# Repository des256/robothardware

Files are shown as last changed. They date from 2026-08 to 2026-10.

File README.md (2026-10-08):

# robothardware — Robot Backbone PCB

KiCad workspace for the backbone board described in [`HARDWARE.md`](HARDWARE.md)
(how and with what) and [`FUNCTIONAL.md`](FUNCTIONAL.md) (what it does, seen from
its connectors and from software).
Tooling follows [kevins-kicad-helpers](https://github.com/lynaghk/kevins-kicad-helpers)
(vendored at `vendor/kevins-kicad-helpers`, on PATH via `mise.toml`).

## Toolchain status

1. **mise** — `~/.local/bin/mise` (2026.10.3), activation line in `~/.bashrc`.
   `mise trust && mise install` done in this directory (babashka, cljfmt, uv).
2. **sqlite3** — static binary at `~/.local/bin/sqlite3` (3.53.4).
3. **KiCad 10** — 10.0.6 as a *user Flatpak* (`org.kicad.KiCad`, installed
   2026-10-08 because the apt PPA install did not land on this machine; the
   apt `kicad` package is absent). The kkh `bin/kicad-cli` shim falls back to
   the Flatpak automatically, so `kkh check`, `kkh build` and
   `kkh-analyze-schematic` work unchanged — run them from inside the repository,
   the Flatpak sandbox only sees `$PWD`. Direct use:
   `flatpak run --filesystem=$PWD:rw --command=/app/bin/kicad-cli org.kicad.KiCad …`.
4. **KiCad plugins** — *not* installed in the Flatpak yet: bennymeg/Fabrication-Toolkit
   (needed by `kkh build`; install from the Plugin and Content Manager inside
   the Flatpak KiCad) and CDFER/JLCPCB-Kicad-Library (not needed any more — the
   symbols, footprints and STEP models the project uses were copied into the
   project-local `0_backbone` library, see Library status).
5. **Analyzer toolchain** (`kkh check` / `kkh-analyze-schematic`) — Java
   temurin-25, clj-kondo and cljfmt via `mise -C vendor/kevins-kicad-helpers/analyzer install`.
   Clojure still needs the asdf-plugin workaround (`mise plugins install clojure
   https://github.com/asdf-community/asdf-clojure.git`, then
   `~/.local/bin/{clojure,clj}` → `~/.local/share/mise/installs/clojure/1.12.5.1654/bin/`).
   Verified: `kkh-analyze-schematic backbone/backbone.kicad_sch` runs.
6. **`KICAD_PYTHON`** — the apt `pcbnew` module is gone with the apt package;
   the board generator (`tools/schematic-gen/pcb.py`) therefore runs inside the
   Flatpak's own Python (`flatpak run --command=/usr/bin/python3 org.kicad.KiCad`).
   `mise.toml` still points `KICAD_PYTHON` at `/usr/bin/python3` for kkh's
   step-export helper; that path has no `pcbnew` until a KiCad apt package is
   installed again.

## Project layout

- `backbone/` — the KiCad project (`backbone.kicad_pro`, root sheet plus one file
  per block, see below); kkh tools discover it by scanning for `*.kicad_pro`.
  `0_backbone.kicad_sym` / `0_backbone.pretty/` / `0_backbone.3dshapes/` are the
  project-local libraries written by `kkh-import-easyeda-parts` (registered in
  the project `sym-lib-table` / `fp-lib-table`; reopen the project in KiCad
  after an import so it picks them up). Library status is tracked in the
  Schematic plan section.
- `jlcpcb_parts.db` — local JLCPCB catalog mirror (gitignored). **Currently not
  usable:** upstream jlcparts switched to a `source-db-v2` layout whose daily dump
  only carries LCSC numbers above ~C6,300,000, so the mirror built on 2026-10-08
  holds 72,611 parts and none of the classic Basic parts or the curated ICs
  (the vendored `kkh-download-jlcpcb-parts-database` also chokes on the split
  zip). The parts added during schematic capture were resolved against
  JLCPCB's live catalog search instead — see `parts-shortlist.md`.
- `docs/placement.md` — the board floorplan (placement diagram) with the
  rendered `docs/placement.png` / `.svg`.
- `tools/schematic-gen/` — the generator that produced every sheet and the
  placed board (see its README); rerun it instead of hand-editing wholesale.
- `parts-shortlist.md` — distilled candidate parts per block, queried from the DB.
- `datasheets/` — part datasheets for every curated pick plus vendor reference
  designs and the ROBOTIS servo circuits (`datasheets/README.md` is the index;
  `datasheets/fetch.sh` re-downloads from `manifest.tsv`).

## Schematic plan (mirrors HARDWARE.md sections 1 and 8)

**Status 2026-10-08: all 15 pages are drawn.** `kicad-cli sch erc` (KiCad 10.0.6)
reports zero errors and zero warnings for the whole hierarchy,
`kkh-analyze-schematic` passes (228 mA of `max_mA` on +3V3, nothing on VBUS),
and the kkh LCSC check passes. `backbone.kicad_pcb` holds every footprint with
its net and schematic link, placed block by block (`docs/placement.md`); it is
not routed, so `kkh check` stops at DRC with 499 unconnected pads.

The hierarchy lives in `backbone/`. The root sheet `backbone.kicad_sch` is the
block diagram of FUNCTIONAL.md §3 and holds only sheet symbols; every block is
its own file, and the two repeated blocks are one file instantiated several
times:

| Page | Sheet file | Instances | Contents | Golden reference |
|---|---|---|---|---|
| 2 | `input` | 1 | J1, fuse, LM74700 + FET, SMBJ24A, bulk; J2 19 V out with its fuse | LM74700 datasheet |
| 3 | `buck-12v-servo` | 1 | LM5145 → `+12V_SERVO`, shared bulk bank | LM5145 EVM / WEBENCH |
| 4 | `buck-5v-servo` | 1 | LM5145 → `+5V_SERVO` (own file: values differ, and D1 may delete it) | same |
| 5 | `buck-5v-usb` | 1 | TPS54560 → `+5V_USB`, TLV62569 → `+3V3` | TPS54560 EVM |
| 6 | `usbc-upstream` | 1 | J3, HD3SS3220 (UFP, GPIO mode), VBUS_DET, ESD | HD3SS3220 checklist + EVM |
| 7 | `usb-hub` | 1 | TUSB8041, 24 MHz crystal, +1V1_HUB buck (TLV62569 + ferrite), straps, GRSTz RC, USB_VBUS divider | TUSB8041 EVM |
| 8–10 | `usb-port` | 3: `usb-port-1..3` = hub DS1..DS3 | TPS2553 + RILIM (1.51 A, FAULT → hub), ferrite, TPD4E05U06, USBLC6-2, USB-A 3.0 receptacle | hub EVM downstream port |
| 11 | `servo-uart` | 1 | CH344Q on hub DS4, TNOW pull-downs, RXD pull-ups | CH344 datasheet |
| 12–15 | `servo-port` | 4: `servo-port-0..3` = CH344 UART0..3 | SP3485EN + LVC2G241 front-end, mode solder jumper, ESD, both connectors, TPS16630 / TPS25961 e-fuses, 470 µF polymer + TVS per connector | ROBOTIS circuits |

Every sheet starts with a note (golden references, LCSC parts, rails, open
FUNCTIONAL.md decisions) and its hierarchical pins on wire stubs. Anything that
must differ between instances cannot live in a multi-instance sheet: KiCad
stores only reference and unit per instance; values, footprints and DNP are
shared.

Conventions (see HARDWARE.md section 8):

- Rails are global power symbols — `+19V_IN`, `+19V_JETSON`, `+12V_SERVO`,
  `+5V_SERVO`, `+5V_USB`, `+3V3`, `+1V1_HUB`, `VBUS`, `GND` — with the
  `PWR_FLAG` on the sheet that produces the rail. In KiCad 10 a power symbol's
  Value is its net name, so a `power:+5V` symbol with Value `+5V_SERVO` *is*
  the `+5V_SERVO` rail. `VBUS` is reserved for the upstream USB-C VBUS (the
  < 10 µF check); the switched port outputs are `VBUS_OUT`.
- Signals cross sheets through hierarchical pins; the labels on the root name
  the top-level nets (`US_*` upstream ↔ hub, `DSn_*` hub ↔ ports, `UARTn_*`
  uart ↔ servo ports). Inside a multi-instance sheet nets get paths such as
  `/servo-port-0/DATA` — the net-class patterns and DRC rules key on them.
- Designators are sheet number × 100 + n (`R301` is on sheet 3, `#PWR0201` on
  sheet 2); multi-instance sheets count per instance (usb-port 8xx/9xx/10xx,
  servo-port 12xx–15xx). FUNCTIONAL.md §2 carries the resulting connector
  numbers (J201/J202, J601, J801/J901/J1001, J12x1/J12x2 …).
- Non-assembled items (test points, solder jumpers, mounting holes) are
  excluded from the BOM and carry `LCSC = n/a`, which is what the kkh LCSC
  check needs to pass without pretending they are purchasable parts.
- Net-class patterns in `backbone.kicad_pro` were extended while drawing:
  `/usb-port-*/VBUS_*` (the switched output has a ferrite, so two nets),
  `/usb-hub/SW_1V1` (the core-rail buck), plus the original ones.
- `max_mA`: `kkh-analyze-schematic` sums every `max_mA` in the design
  regardless of rail and asserts ≤ 300 mA (hardcoded in
  `vendor/kevins-kicad-helpers/analyzer/src/kicad_analyzer/core.clj`), so it is
  set only on the +3V3 ICs with typical-active numbers: hub VDD33 33, CH344Q 30,
  HD3SS3220 5, 4 × SP3485EN 35, 4 × LVC2G241 5 = 228 mA. The rail budgets
  stay in FUNCTIONAL.md §4.
- `kkh check` fails any placed part (non-DNP, with a footprint) whose `LCSC`
  field is empty — CDFER-library and `kkh-import-easyeda-parts` symbols carry
  it, symbols taken from KiCad's own libraries (`Device:R`, …) need it filled
  in by hand.

### Library status (`0_backbone` is self-contained)

Every symbol the sheets use lives in `backbone/0_backbone.kicad_sym` (KiCad 9
library format, read by KiCad 10) with its footprint in `0_backbone.pretty` and
STEP model in `0_backbone.3dshapes`; nothing depends on the global symbol or
footprint tables. Three sources:

- **`kkh-import-easyeda-parts`** (EasyEDA symbol + footprint + 3D, LCSC field
  filled): TUSB8041IRGCR, CH344Q, SN74LVC2G241DCU, LM5145RGYR, TPS54560DDAR,
  TLV62569DBVR, TPS16630PWPR, TPS25961DRVR, SY6280AAC (unused, kept as the
  imported alternate), HD3SS3220RNHR, LM74700QDBVRQ1, TPD4E05U06DQAR,
  USBLC6-2SC6, B4B-EH-A, B3B-EH-A, XT30PW-M, HC-ST-003-01-J (USB-A 3.0),
  TYPE-C 24P QT, TPS2553DBVR, and the parts added on 2026-10-08: CSD18532Q5B
  (buck + ideal-diode FET), the four inductors (TMPA1265SP-4R7MN-D,
  TMPC1265HP-3R3MG-D, 7447798720, SMNR4020-2.2UH), the 100 V / 16 V / 25 V
  1210 ceramics, the polymer and electrolytic bulk capacitors, both fuses and
  the B560C catch diode. Pin electrical types were set by hand (the import
  leaves them "unspecified", which ERC flags) — see `PIN_TYPES` in
  `tools/schematic-gen/libbuild.py`.
- **Copied from CDFER/JLCPCB-Kicad-Library 2025.07.18** (symbol, footprint,
  STEP; vendor stock/price fields dropped): generic `R_0603`, `C_0402`,
  `C_0603`, `C_0805`, `C_1206`, `FB_0603`, `FB_0805`, `TVS_SMB` — Value and
  LCSC are set per instance from the catalog in `tools/schematic-gen/common.py`
  — plus `LED_0805_Green`, `SMF5.0A`, `SS14`, `PSM712`, `SP3485EN`,
  `Crystal_8MHz_5032`, `Crystal_24MHz_3225`.
- **Copied from KiCad's own libraries**: the power symbols (`+VDC`, `+12V`,
  `+5V`, `+3V3`, `+1V1`, `VBUS`, `GND`, `PWR_FLAG`), `TestPoint`,
  `SolderJumper_3_Bridged12`, `SolderJumper_2_Bridged`, `SolderJumper_2_Open`,
  `MountingHole` with their footprints.

Footprint fixes applied to the imports (so DRC and schematic parity are
clean): the unnumbered thermal-via pads inside the HTSSOP-20 (TPS16630) and
SOIC-8-EP (TPS54560) exposed pads now carry the exposed pad's number, and the
two alignment pegs of both USB-C footprints are NPTH instead of copper-less
PTH. **V4 is still open**: every imported footprint must be checked against
its datasheet drawing before ordering; the USB-C QT shell legs in particular
are modelled as two overlapping oval PTH pads per side.

Alternates that stay importable as a symbol swap: RTS5411S-GR, CYUSB3304-68LTXC,
CH344L, SN74LVC1G126DBVR, SN74LVC1G125DBVR, LM5143RHAR, S4B-EH, S3B-EH,
DC-005-A200, TYPE-C 24P QCHT, SY6280AAC.

EasyEDA's API rate-limits bulk pulls (HTTP 403 after ~15 parts within a
minute); wait a few minutes and rerun the same command for the parts that
failed. Reruns skip parts the library already has.

### Schematic ↔ PCB correspondence

KiCad has no sheet-to-layer mapping; sheets are functional, layers are copper.
The links that do exist, and where each one is set up:

| Link | Where | State |
|---|---|---|
| Stackup | `backbone.kicad_pcb`: 4 copper layers, In1.Cu named `GND` (plane), In2.Cu named `PWR` | set; enter the JLC04161H-7628 thicknesses in Board Setup → Physical Stackup |
| Net classes | `backbone.kicad_pro`: `USB3_SS`, `USB2_HS`, `RS485`, `TTL_DATA`, `PWR_19V`, `PWR_SERVO`, `PWR_USB`, `SW_NODE`; Default clearance 0.127 mm (JLCPCB minimum, needed by the 0.4 mm-pitch HD3SS3220 and the USB-C pads) | defined; USB3_SS / USB2_HS width and gap **still to fill from the JLCPCB impedance calculator** (they inherit Default until then); power-class widths are starting values. The class clearances (SW_NODE 0.5 mm, PWR_SERVO 0.3 mm) and the 3 mm `sw_node_away_from_signals` rule also bite at IC pads (37 DRC clearance errors on the placed board) — scope them to tracks/zones with `A.Type` conditions in the `.kicad_dru` during layout |
| Class of a signal net | directive label on its stub inside the sheet (a multi-instance sheet applies it to every instance) | placed on every USB pair |
| Class of a rail / per-port net | `netclass_patterns` in `backbone.kicad_pro`: `+12V_SERVO`, `/servo-port-*/A`, `/servo-port-*/B`, `/servo-port-*/DATA`, `/servo-port-*/VDD_*`, `/usb-port-*/VBUS_*`, `/buck-*/SW*`, `/buck-*/BOOT*`, `/usb-hub/SW_1V1` | set and used by the drawn sheets |
| Layer geometry and keep-outs | `backbone.kicad_dru`: USB3_SS on F.Cu only and without vias, 1 mm zone clearance to the USB pairs, SW_NODE on outer layers and 3 mm from signal classes, PWR_SERVO copper barred from a rule area named `usb_section` (draw and name it in the PCB editor) | written; check it with Board Setup → Custom Rules → "Check rule syntax" — `kicad-cli pcb drc` silently ignores rule-file errors |
| Sheet → board region | `backbone.kicad_pcb`: one placement rule area per sheet instance (named like the sheet, source = sheet name) plus the `usb_section` area, generated by `tools/schematic-gen/pcb.py`; footprints are packed into them (`docs/placement.md`) | done; routing, exact placement and the connector orientations are the layout stage's job |
| Sheet → component class | `sheet_component_classes` enabled in `backbone.kicad_pro`; rules can use `A.hasComponentClass(...)` | enabled |

Workflow. ERC is clean and the footprints are placed, so `kkh check` now
stops at DRC (unconnected pads) until the board is routed; `kkh build` needs
the Fabrication Toolkit plugin as well. To regenerate sheets or the board after
editing the generator, see `tools/schematic-gen/README.md`. Direct commands:

```sh
kicad-cli sch erc --exit-code-violations -o /dev/stdout backbone/backbone.kicad_sch   # via the kkh shim → Flatpak
kicad-cli pcb drc --schematic-parity -o /dev/stdout backbone/backbone.kicad_pcb
kkh-analyze-schematic backbone/backbone.kicad_sch     # max_mA total, VBUS < 10 uF
kkh-import-easyeda-parts C544686 C2988084 ...          # symbols/footprints per LCSC number
```

From layout onward: `kkh check`, then `kkh build` for the JLCPCB order
package. Put `${KKH_VERSION_DATE}` on the silkscreen (the first `kkh check`
adds the placeholder text variable to `backbone.kicad_pro`; commit it).

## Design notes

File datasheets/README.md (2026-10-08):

# Datasheets and golden references

Everything the schematic gets drawn from, so nobody designs from memory.

- `manifest.tsv` lists every part datasheet (file, LCSC number, MPN, block, URL).
  URLs come from the JLCPCB catalog (`jlcpcb_parts.db`); TI links were rewritten
  to the English editions (`/lit/` instead of `/cn/lit/`).
- `fetch.sh` (re)downloads everything in the manifest and verifies each file is a
  PDF. Safe to re-run; cached files are skipped. LCSC-hosted sheets need the
  `wmsc.lcsc.com/wmsc/upload/file/pdf/…` form of the link (the `www.lcsc.com/datasheet/…`
  form returns an HTML viewer), so the manifest uses those.
- `reference/` holds vendor reference designs, app notes and the ROBOTIS
  circuits — the "golden references" HARDWARE.md §8 asks for per block.

Identical files were collapsed: one JST EH catalog sheet covers B3B/B4B/S3B/S4B,
one Hongjiacheng sheet covers all SMBJ values, one WCH sheet covers CH344Q/L.

## Part datasheets (by block)

| Block | Part (LCSC) | File | Notes |
|---|---|---|---|
| USB 3.0 hub | TUSB8041IRGCR (C544686) | `tusb8041.pdf` | 49 p. Rails: VDD 1.1 V + VDD33 3.3 V; 24 MHz crystal; `USB_VBUS` via 90.9 kΩ divider; per-port `PWRCTLx` / `OVERCURxz` |
| USB 3.0 hub (alt) | RTS5411S-GR (C5356838) | `rts5411s.pdf` | Consumer-hub chip, thinner docs |
| USB 3.0 hub (alt) | CYUSB3304-68LTXC (C462531) | `cyusb3304.pdf` | |
| USB-UART ×4 | CH344Q (C2988084), CH344L (C2887250) | `ch344.pdf` | **Chinese edition** (CH344DS1, 8 p.). TNOW facts extracted in `FUNCTIONAL.md` §5. English copy: manual grab from wch-ic.com (JS-only site) |
| RS-485 transceiver ×4 | SP3485EN-L/TR (C8963) | `sp3485en.pdf` | 3.3 V, 10 Mbps, −7…+12 V common mode; DE / R̄E̅ pins |
| TTL half-duplex buffer ×4 | SN74LVC2G241DCUR (C10430) | `sn74lvc2g241.pdf` | 1OE active-low, 2OE active-high; ±24 mA @ 3.3 V |
| TTL buffer (2-chip alt) | SN74LVC1G126 (C7834), SN74LVC1G125 (C23654) | `sn74lvc1g126.pdf`, `sn74lvc1g125.pdf` | |
| Buck controller, servo rails | LM5145RGYR (C485912) | `lm5145.pdf` | 6–75 V in, external FETs |
| Buck controller, dual (alt) | LM5143RHAR (C5219297) | `lm5143.pdf` | One chip for both servo rails |
| Buck 5 V USB | TPS54560DDAR (C31966) | `tps54560.pdf` | 60 V in, 5 A |
| Buck 3.3 V | TLV62569DBVR (C141836) | `tlv62569.pdf` | 2 A, Vin ≤ 5.5 V |
| eFuse, 12 V buses | TPS16630PWPR (C1849461) | `tps1663.pdf` | 60 V, ~6 A class |
| eFuse, light 5 V buses | TPS25961DRVR (C5571272) | `tps25961.pdf` | ≤ 2 A class |
| VBUS switch ×3 | SY6280AAC (C55136) | `sy6280.pdf` | `Ilim(A) = 6800 / Rset(Ω)`; EN must not float |
| VBUS switch (alt) | TPS2553DBVR (C55266) | `tps2553.pdf` | |
| USB-C CC + SS mux | HD3SS3220RNHR (C165155) | `hd3ss3220.pdf` | UFP: `PORT`=L, `ADDR`=NC (GPIO mode), `ENn_CC`=L, `VBUS_DET` via 900 kΩ |
| Ideal-diode controller | LM74700QDBVRQ1 (C2941042) | `lm74700-q1.pdf` | Drives external N-FET |
| TVS, rails | SMBJ24A / 13A / 6.0A (C19077578 / 67 / 60) | `smbj-series.pdf` | Chinese vendor sheet, all values |
| ESD, USB3 SS pairs | TPD4E05U06DQAR (C138714) | `tpd4e05u06.pdf` | 0.5 pF |
| ESD, USB2 + TTL DATA | USBLC6-2SC6 (C2687116) | `usblc6-2sc6.pdf` | UMW clone |
| ESD, RS-485 | SM712 (C7420375) | `sm712.pdf` | −7 / +12 V asymmetric |
| Servo connectors | JST B4B-EH-A (C160258), B3B-EH-A (C160259), S4B-EH (C265068), S3B-EH (C263754) | `jst-eh-series.pdf` | EH catalog page (drawings, ratings) |
| 19 V input | XT30PW-M (C431092) | `xt30pw-m.pdf` | Chinese drawing |
| 19 V out (alt) | DC-005-A200 (C720557) | `dc-005-a200.pdf` | |
| USB-A 3.0 receptacle ×3 | HC-ST-003-01-J (C2845330) | `usba3-hc-st-003-01-j.pdf` | Chinese drawing |
| USB-C receptacle | TYPE-C 24P QT (C2681555), QCHT (C456013) | `usbc-24p-qt.pdf`, `usbc-24p-qcht.pdf` | Chinese drawings |
| Buck / ideal-diode FET ×5 | CSD18532Q5B (C882766) | `csd18532q5b.pdf` | 60 V, 2.5 mΩ, SON 5×6; RILIM 240 Ω / 150 Ω sized for it |
| Buck inductors | TMPA1265SP-4R7MN-D (C2880057), TMPC1265HP-3R3MG-D (C357272), SMNR4020-2.2UH (C135262) | `tmpa1265sp-4r7.pdf`, `tmpc1265hp-3r3.pdf`, `smnr4020-2r2.pdf` | 12 V, 5 V servo, 3V3/1V1 bucks |
| Buck inductor, +5V_USB | 7447798720 (C105681) | `we-7447798720.pdf` | Würth 7.2 µH 6 A (TPS54560EVM part) |
| Catch diode, +5V_USB | B560C-13-F (C85100) | `b560c.pdf` | |
| 100 V input ceramics | C3225X7S2A475KT000N (C342614), C3225X7R2A225KT5L0U (C76686) | `tdk-c3225x7s2a475k.pdf`, `tdk-c3225x7r2a225k.pdf` | 1210 |
| Buck output ceramics | GRM32ER61C476KE15L (C77101), CS3225X7R226K250NRL (C2918511) | `murata-grm32er61c476k.pdf`, `samwha-cs3225x7r226k.pdf` | 1210 |
| Bulk capacitors | RVE470UF35V167RV084 (C5155332) | `rve470uf35v.pdf` | 19 V input bank. The polymer MA25V470M8X10 (C46550466) / MA10V470M6X8 (C46550459) have no datasheet file in the JLCPCB catalog — spec is the catalog line (25 mΩ / 20 mΩ, 4.1 A / 3.1 A ripple) |
| Fuses | 0453015.MR (C178997), 1206TD-4A (C2838918) | `littelfuse-0453015.pdf`, `prosemi-1206td-4a.pdf` | 15 A time-lag input, 4 A time-lag Jetson |

## Reference designs and app notes (`reference/`)

| Block | File | What it is |
|---|---|---|
| USB hub | `ti-sllu198-tusb8041-evm-users-guide.pdf` | TUSB8041 EVM — the reference schematic to copy |
| USB hub / SS layout | `ti-slla414a-usb-hub-highspeed-layout-guidelines.pdf` | TI SuperSpeed layout rules |
| USB ESD | `ti-slvaf82b-esd-surge-protection-usb.pdf` | Where the TVS arrays go |
| USB-C upstream | `ti-sllu241-hd3ss3220-ufp-dongle-evm.pdf` | HD3SS3220 in **UFP** mode — our exact use |
| USB-C upstream | `ti-slla481-hd3ss3220-schematic-checklist.pdf` | 3-page checklist; run it before ERC |
| 12 V / 5 V servo bucks | `ti-snvu545-lm5145evm-hd-20a.pdf` | LM5145 20 A EVM — schematic, BOM, layout |
| 5 V USB buck | `ti-slvu863-tps54560-evm.pdf` | TPS54560 EVM |
| Input protection | `ti-slvae57b-basics-of-ideal-diodes.pdf` | Background for the LM74700 stage |
| Servo TTL front-end | `robotis/dynamixel-x-ttl-circuit-3v3-74lvc2g241.png` | **ROBOTIS's recommended 3.3 V TTL circuit** (XL330 / XC330-M) — 74LVC2G241, TX_Enable → 1OE̅ + 2OE |
| Servo TTL front-end | `robotis/dynamixel-x-ttl-circuit-5v.png` | Same circuit at 5 V (XL430 / XM430-T class) |
| Servo RS-485 front-end | `robotis/dynamixel-x-rs485-circuit.jpg` | ROBOTIS's recommended RS-485 circuit — MAX485, TX_Enable → DE + R̄E̅ tied |
| Servo connectors | `robotis/dynamixel-x-ttl-connector-pinout.png`, `robotis/dynamixel-x-rs485-connector-pinout.png`, `robotis/emanual-jst-connectors.md` | Pinouts: TTL `1 GND, 2 VDD, 3 DATA`; RS-485 `1 GND, 2 VDD, 3 D+, 4 D−` |
| Servo specs | `robotis/dxl_x_info.yml` | ROBOTIS's own spec data for every X-series servo (voltage, stall current, baud) — feeds the fleet table |
| U2D2 | `robotis/u2d2-emanual.md`, `robotis/u2d2-pinouts.png` | ROBOTIS doesn't publish the U2D2 schematic; the emanual page + the circuits above are what exists |

Source pages: TI product pages (`ti.com/product/<part>`), ROBOTIS e-Manual
(`github.com/ROBOTIS-GIT/emanual`, `_includes/en/dxl/*_connection_x.md`).

## Still to collect (manual)

| Item | Why manual | Blocked on |
|---|---|---|
| WEBENCH designs: LM5145 → 12 V, LM5145 → 5 V, TPS54560 → 5 V | Interactive TI tool, needs login. Export PDF + BOM into `reference/webench/` | Servo fleet decision (currents) |
| English CH344DS1 | wch-ic.com is JavaScript-only; curl gets nothing | — |
| Jetson Orin NX carrier: datasheet / design guide (input range, polarity, USB-C port capabilities) | Depends on which carrier | Carrier decision |
| Dynamixel e-Manual pages for the chosen servos | Fleet not decided; `dxl_x_info.yml` already has the numbers | Fleet decision |
| JLCPCB impedance stackup (JLC04161H-7628) + DRC template | Layout stage | — |

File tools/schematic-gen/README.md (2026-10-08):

# schematic-gen — generator for the backbone sheets and the placed board

Every sheet under `backbone/` and `backbone/backbone.kicad_pcb` were produced by
these scripts on 2026-10-08. They are the source of truth for *regenerating*;
once the sheets are edited by hand in KiCad, stop running the generator (it
rewrites whole files) and keep the scripts as documentation of how the circuit
was derived from the datasheets.

Files

| File | Role |
|---|---|
| `sx.py` | minimal KiCad s-expression reader/writer |
| `sch.py` | schematic writer (KiCad 9 file format, read by KiCad 10): places symbols at coordinates, computes pin positions, draws stubs, labels, power symbols, no-connects, hierarchical labels; `Sheet.check()` is a small connectivity self-check that reports shorted nets and pins lying on foreign wires before writing |
| `common.py` | LCSC catalog (value → part number, verified against JLCPCB on 2026-10-08) and layout helpers (`vR`, `vC`, `decap`, `vdiode`, `rail_led`, `testpoint`, …) |
| `libbuild.py` | one-off: builds `backbone/0_backbone.kicad_sym` — sets pin electrical types on the EasyEDA imports, copies the generic passives and small parts from the CDFER JLCPCB library (needs the unzipped PCM package, `CDFER_PKG=…`), copies KiCad's power / jumper / test point / mounting hole symbols and footprints. Already applied; rerun only after new `kkh-import-easyeda-parts` imports |
| `d_power.py` | sheets 2–5: input, LM5145 bucks (TI application circuits 1 and 2 parametrised in `P12` / `P5`), TPS54560 + TLV62569 |
| `d_usb.py` | sheets 6–10: HD3SS3220 upstream, TUSB8041 hub, USB-A port (×3) |
| `d_servo.py` | sheets 11–15: CH344Q, dual-mode servo port (×4) |
| `d_root.py` | root sheet: re-emits the skeleton block diagram (`skeleton/backbone.kicad_sch`) in KiCad 9 format and adds the mounting holes |
| `build.py` | writes the sheets into `backbone/` and runs ERC through the Flatpak KiCad 10 |
| `pcb.py` | builds the board from the exported netlist: footprints with nets and paths, placement rule areas, outline, texts; the floorplan is the `REGIONS` table (see `docs/placement.md`). Runs inside the Flatpak's Python |
| `skeleton/` | the original KiCad 10 root sheet and board stub the generator starts from (sheet-symbol UUIDs and page numbers come from here) |

Regenerate everything (run from the repository root; the Flatpak only sees `$PWD`):

```sh
python3 tools/schematic-gen/build.py                      # all sheets + ERC summary
python3 tools/schematic-gen/build.py usb-hub servo-port   # a subset
kicad-cli sch export netlist --format kicadsexpr -o backbone/outputs/scratch/backbone.net backbone/backbone.kicad_sch
flatpak run --filesystem=$PWD:rw --command=/usr/bin/python3 org.kicad.KiCad tools/schematic-gen/pcb.py
kicad-cli pcb export svg --layers F.Cu,F.SilkS,Edge.Cuts,Cmts.User --page-size-mode 2 --exclude-drawing-sheet -o docs/placement.svg backbone/backbone.kicad_pcb
```

`kicad-cli` resolves through `vendor/kevins-kicad-helpers/bin` (on PATH via
`mise.toml`), which falls back to the Flatpak when no native KiCad is installed.

Conventions baked into the generator

- Symbol UUIDs are `uuid5` of sheet name + reference + position, so reruns
  produce the same identities and the board keeps its schematic links.
- References are sheet number × 100 + n; multi-instance sheets get one
  reference per instance path (usb-port 8xx/9xx/10xx, servo-port 12xx–15xx).
- Non-assembled parts (test points, solder jumpers, mounting holes) are
  excluded from the BOM and carry `LCSC = n/a`; DNP parts (RS-485 termination,
  SW snubbers) are marked DNP.
- Power symbols come from the project library; the sheet that produces a rail
  owns its `PWR_FLAG` (`Sheet.flag_rail`).

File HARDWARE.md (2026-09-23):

# HARDWARE — Robot Backbone PCB

Design notes for the power-and-interconnect motherboard: USB 3.0 hub with three
generic downstream ports (RealSense D435, ReSpeaker 4-mic array, future
hardware), four dual-mode servo buses (RS-485 @ 12 V or TTL @ 5 V) via a CH344,
and step-down converters feeding the Jetson Orin NX and peripherals.

> **Status: design guidance, not a finished design.** Every part number below is a
> *candidate* to be verified against its datasheet and current stock — nothing here
> substitutes for the reference design in each datasheet.

## 1. System architecture

```
19V laptop adapter ──► [fuse + reverse-polarity ideal diode + TVS + bulk caps]
                            │
        ├──► 19V passthrough ──► [fuse/load switch] ──► 19V out (Jetson Orin NX)
        ├──► Buck #1: 12V ──► star ──► 4× [e-fuse + bulk caps + TVS] ──► 4-pin RS-485 connectors
        ├──► Buck #2: 5V servo ──► star ──► 4× [e-fuse + bulk caps + TVS] ──► 3-pin TTL connectors
        └──► Buck #3: 5V USB @ ~5A ──► 3× VBUS switches ──► USB-A 3.0 sockets
                       │
                       └──► 3.3V (small buck or LDO) ──► hub, CH344, bus front-ends

USB-C (from Jetson, upstream) ──► [CC controller + SS mux] ──► USB 3.0 hub (4-port)
        ├── ports 1–3 (SS): generic USB-A 3.0 ──► RealSense, ReSpeaker, future hardware
        └── port 4 (USB2 only): CH344 ──► 4× dual-mode front-ends ──► RS-485 or TTL connector
```

Key insight: the Jetson is both a *load* (19V out) and the *USB host* (USB-C in).
The board is a **self-powered hub** — that has consequences (see §3, USB rules).

## 2. Power budget first — everything else follows from it

Build this table before picking any converter. Worst case, not typical:

| Rail | Loads | Estimate |
|---|---|---|
| 19V passthrough | Orin NX at MAXN (clocks pinned per README) + carrier | ~40 W (the Jetson's own USB loads live on *this* board, so it stays moderate — check the carrier's spec) |
| 12V servo (RS-485 buses) | RS-485 servo fleet. Sum-of-stall (~2 A @ 12 V per Dynamixel-X-class servo) is the conservative ceiling; size for the worst *simultaneous* mechanical load you can justify and let per-bus e-fuses bound the rest (§5) | 10–20 A depending on fleet |
| 5V servo (TTL buses) | TTL servo fleet — same sizing philosophy. XL330-class servos stall around 1–1.5 A each (verify per model). **Never shared with the USB 5 V rail** | 5–10 A depending on fleet |
| 5V USB | 3 generic ports × per-port current limit (~1.5 A each) + the 3.3 V rail derived from this (quiet) rail. **Generic ports mean sizing for the sum of the limits, not for a known device list** | ~5 A |
| 3.3V | Hub + CH344 + bus front-ends | < 0.5 A |

Sum at ~85% converter efficiency: a build with a 10 A 12 V budget and a 5 A TTL
budget lands around **~240 W peak** (≈141 W + ≈29 W for the servo rails + ≈29 W
USB + ~40 W Jetson). Big laptop bricks top out around 230–330 W — **spec the
adapter from this table, not from habit**, and recompute when the servo fleet
changes. A 90 W adapter will brown out during a servo stall while the Jetson is
at MAXN — the classic "robot reboots when the arm hits something" bug.

## 3. Component selection, block by block

### Input protection (19V)

Blade fuse or high-current polyfuse → reverse-polarity protection with an
ideal-diode controller + N-FET (e.g., LM74700-Q1) rather than a lossy series diode
(at 6 A a Schottky wastes ~3 W) → TVS with standoff above the adapter's max
(19 V + 10% → something like an SMBJ24A, which clamps near 39 V — so every
downstream converter needs Vin(max) well above that; hence 60 V-rated bucks) →
bulk electrolytics.

### Step-down converters

- 12 V at four-bus current (10–20 A) is beyond single-chip bucks — use a
  controller + external FETs (LM5145 class) or a validated power module. The same
  controller design can be reused for the 5 V servo rail with a different
  feedback divider — good BOM consolidation.
- 5 V servo rail: sized to the TTL fleet (§2); a single-chip 5 A part suffices
  only for a small fleet.
- 5 V USB at ~5 A sits right at the edge of a single-chip part like the TPS54560
  (4.5–60 V, 5 A): either bound the per-port limits so the sum fits (e.g.,
  3 × 1.3 A), or reuse the controller-based design here too.
- Use TI WEBENCH / the vendor's design tool for inductor and compensation values,
  then **copy the datasheet layout example exactly** — buck layout is not a place
  for creativity.
- 3.3 V via a small buck (TPS62-class) or LDO (if confirmed < ~300 mA), fed from
  the **quiet USB 5 V rail — never the servo rails**.
- USB 3.0 hub chips also need a core rail (1.1/1.2 V) — follow the hub datasheet's
  reference design, usually a dedicated LDO.

### USB 3.0 hub

4-port SuperSpeed hub controller — candidates: Microchip USB5744, TI TUSB8041,
VIA VL817. Selection criteria: in stock at LCSC/Digi-Key, a public reference
schematic, and (this matters) evidence people run RealSense cameras through it —
the D435 is notoriously picky about marginal USB3 links, and the librealsense
GitHub issues are full of hub horror stories. Search for hubs the RealSense
community has validated.

### Generic downstream ports

All three non-CH344 downstream ports are wired identically as USB-A 3.0: full
SuperSpeed pairs, same ESD array, same per-port power switch. Consequences:

- Any device fits any port. The RealSense needs SuperSpeed; the ReSpeaker is
  USB 2.0 and works fine in a USB 3.0 socket (the USB2 pins are a superset).
- Cost vs. dedicated ports: two extra SS pair routes + ESD arrays — cheap for the
  flexibility.
- **Per-port current limits must be identical (~1.5 A)** since you no longer know
  which device lands where, and the 5 V USB rail must be sized for the *sum* of
  the limits plus the 3.3 V derivation (§2) — not for the known device list.
- Software should identify devices by VID/PID (as the existing ReSpeaker udev
  rule already does), never by physical port position — anything keyed to
  `/dev/serial/by-path` or USB topology breaks when a device moves ports.

### USB-C upstream — a real gotcha

For SuperSpeed to work in *both* plug orientations, a device needs a CC controller
+ 2:1 SS mux (e.g., TI HD3SS3220 — the standard part for exactly this). Without
it, wire Rd (5.1 kΩ) pull-downs on CC1/CC2 and SS only links in one orientation,
silently falling back to USB 2.0 in the other — which for the D435 means depth
streams fail mysteriously. Budget the mux.

### Self-powered hub rules

- Do **not** connect upstream VBUS to the 5 V rail — the Jetson must not
  back-power the board or vice versa. Upstream VBUS goes only to the hub's
  VBUS-detect pin (through the divider the datasheet specifies).
- Downstream, give each USB-A socket a current-limiting power switch (TPS2553
  single / TPS2561A dual), fault flag wired to the hub's overcurrent-sense pins.
- Set all three port limits identically (~1.5 A) — generic ports, unknown
  placement (see above).

### Servo buses — CH344, four dual-mode ports (RS-485 or TTL)

- The **CH344 is a quad-UART bridge** — one USB 2.0 hub port in, four independent
  UARTs out. Each UART feeds a **dual-mode front-end**: a 4-pin RS-485 connector
  (12 V power) *and* a 3-pin TTL connector (5 V power), with one mode in use per
  port.
- **Both modes speak the same UART framing and protocol** — the difference is
  physical layer only. RS-485: differential A/B pair. TTL: single-ended,
  single-wire half-duplex — TX and RX share one DATA line that idles high via a
  pull-up.
- **RS-485 side:** one transceiver per port. With TNOW available (below), a plain
  DE/R̄E̅ transceiver (THVD1450-class) is preferred over auto-direction parts —
  one direction scheme serves both modes.
- **TTL side:** one tri-state buffer per port (SN74LVC2G241-class). Its two
  complementary output enables make a single chip a complete half-duplex
  front-end — one gate drives TXD onto DATA when enabled, the other feeds DATA
  back to RXD. This mirrors ROBOTIS's own U2D2 reference circuit — pull up that
  schematic as the golden reference.
- **Direction:** the CH344's per-UART TNOW pin (asserts during transmission)
  drives both the RS-485 DE and the '241 enables. Verify TNOW polarity against
  the enable pins — a tiny inverter may be needed.
- **Mode select (the either/or):** TXD may fan out to both drivers permanently —
  the unused connector just carries a harmless copy. **RX is the only conflict:**
  exactly one receiver may drive the UART RXD pin. A per-port jumper /
  solder-bridge (or GPIO) enables one receiver — transceiver R̄E̅ vs. '241 RX
  gate — with both outputs wire-OR'd onto RXD through a pull-up.
- **Echo symmetry:** gate both receivers off during TNOW so neither mode echoes
  the transmitted packet — echo behavior stays identical across all ports and
  modes, and the servo software needs no per-port special-casing.
- **Levels:** run logic at 3.3 V (the CH344's native level). LVC buffers are
  5 V-tolerant, so a 5 V-pulled DATA line is fine, and 3.3 V drive meets TTL
  thresholds — but check the specific servo's DATA-pin spec (XL330-class 5 V
  servos have 3.3 V-compatible logic; verify per model).
- **TTL caution:** single-ended means far less noise immunity than RS-485 on a
  robot full of motors — keep TTL runs short, ground solid, ESD TVS on DATA
  (5 V working-voltage part), optional small series resistor (~10–22 Ω).
- Check the transceiver's, buffer's, and CH344's max data rates against the servo
  protocol (Dynamixel Protocol 2.0 commonly runs 57.6 kbps–1 Mbps+).
- **Driver check before committing:** confirm how the CH344 enumerates on the
  L4T/Jetson kernel — the four ttys typically come from WCH's out-of-tree `ch343`
  serial driver; verify it builds for aarch64. Cheapest test: a CH344 dongle
  before the board exists.
- Why four buses: RS-485/TTL are multi-drop, so one bus *could* daisy-chain every
  servo — the four buses exist for **control bandwidth** (each bus polls fewer
  servos per cycle → lower feedback latency), plus fault isolation and per-limb
  home-run cabling.

### Connectors

- RS-485 mode: Dynamixel-X RS-485 servos use a JST EH 4-pin (GND, V+, D+, D−) —
  match the servo's actual pinout *from its manual*.
- TTL mode: bigger X-series TTL servos use a JST EH 3-pin (GND, V+, DATA);
  XL330-class servos use a smaller housing — check the manual.
- **The different 3-pin/4-pin housings double as keying**: a 5 V TTL servo
  physically can't be plugged into a 12 V RS-485 connector. Preserve that
  property when picking connectors.
- Mind per-contact current ratings (EH-class contacts are good for ~2–3 A — a
  daisy-chain of stalling servos can exceed that even on a single bus).
- Barrel jacks are often rated only ~5 A; adequate for ~40 W at 19 V but check the
  specific part. Verify the Jetson carrier's accepted input range and polarity
  before committing (official carriers take roughly 9–20 V center-positive —
  confirm).
- USB-A receptacles with through-hole shell stakes for mechanical strength.

### ESD on every external connector

Low-capacitance TVS arrays — TPD4E05U06-class on SuperSpeed pairs, USBLC6-2 on
USB 2.0 pairs, SM712 on RS-485, a 5 V-working-voltage single-line TVS on TTL
DATA, plain SMBJ on the power connectors.

## 4. Servo surge protection

Two distinct phenomena, applying to **both** servo rails (12 V and 5 V):

1. **Stall/inrush transients** — the servo rail sags. Fix: bulk low-ESR
   capacitance (≥ 470–1000 µF electrolytic/polymer) physically at each servo
   connector, plus a buck with headroom. Cap voltage rating: ≥ 25 V on the 12 V
   rail, ≥ 10 V on the 5 V rail.
2. **Regenerative back-EMF** — when servos decelerate or are back-driven, they
   *pump current into* the rail, and **buck converters cannot sink current**, so
   the rail voltage rises. Fix: the same bulk capacitance absorbs the energy, and
   a TVS catches what the caps don't — SMBJ13A-class (13 V standoff) on the 12 V
   rail, SMBJ6.0A-class (6 V standoff) on the 5 V servo rail. Confirm the buck
   tolerates output overvoltage gracefully (most modern ones stop switching). For
   large servos with heavy loads the proper fix is an active brake/shunt clamp
   (comparator + FET + power resistor); for Dynamixel-class servos, caps + TVS is
   standard practice.

A series diode between buck and servo rail (to protect the buck) is usually *not*
used — it ruins regulation, and the regen energy has nowhere to go but up. Caps +
TVS is the right shape.

## 5. Four dual-mode servo ports on shared rails

**One buck per voltage class, not per bus.** The standard shape is one 12 V rail
and one 5 V servo rail, each with per-connector protection — separate bucks per
bus are 4× the parts and board area for little gain, and each would still need
sizing for its own bus's stall anyway. Split a rail into two bucks only for very
asymmetric loads (one heavy arm bus + three light buses) or when hard fault
domains are required.

Applies identically to the 12 V (RS-485) and 5 V (TTL) rails:

- **Buck sizing:** each rail carries its whole fleet — see §2. Sum-of-stall is
  the conservative ceiling; size for the worst simultaneous mechanical load you
  can justify, and let per-bus current limits bound the rest.
- **Caps, shared + distributed:** a large bulk bank at the buck output, plus a
  local ~470 µF low-ESR cap *at each connector*. Regen from one bus pumps the
  shared rail, where the shared bulk — and the load of the other buses — absorbs
  it; that's a mild benefit of sharing one rail.
- **One TVS per connector.** Cheap; keep them all (voltage class per §4).
- **Per-connector e-fuse or polyfuse:** fault isolation, so a crushed servo cable
  on one limb doesn't drop the whole robot. GPIO-controlled e-fuses (TPS259x
  class) additionally give soft-start, a per-bus e-stop, and staggered power-up
  to tame the combined inrush of multiple buses enabling at once.
- **Star distribution:** route each rail from its buck's bulk bank to the
  connectors as separate polygon pours, so one bus's stall sag doesn't couple
  through shared trace impedance into the others.
- **The 5 V servo rail is never the USB 5 V rail** — servo stall transients on a
  shared rail would brown out the cameras. Two separate bucks, two separate
  distribution trees, joined only at ground.

## 6. Layout and stackup — where USB 3.0 boards live or die

- **4-layer minimum**: Signal / GND / Power / Signal. Order the fab's
  impedance-controlled stackup (e.g., JLCPCB's JLC04161H-7628) and use *their*
  calculator for trace geometry — don't copy numbers from forums.
- SuperSpeed pairs: 90 Ω differential, intra-pair matched to ~0.1 mm, continuous
  ground reference underneath (no plane splits), no stubs, AC-coupling caps
  (0.1 µF) on TX pairs where the hub datasheet shows them, ESD arrays right at the
  connector. Keep pairs short — place the hub between the USB-C and the USB-A
  ports.
- Keep buck inductors and switch nodes **away** from USB, RS-485, and TTL DATA
  routing; keep each buck's input loop tiny; thermal vias under converter pads.
- High-current paths (19 V in, both servo rails, servo ground returns) get
  polygons, not traces; route servo returns so they don't flow under the USB
  section.
- 2.4 GHz radios on the robot: USB 3.0 famously radiates in that band (Intel has a
  whole whitepaper) — keep antennas away from this board and use shielded
  connectors/cables.

## 7. Workflow: KiCad → fab

1. **Prototype the architecture first with off-the-shelf modules** — a powered
   USB3 hub, a CH344-based USB-RS485 dongle (doubles as the L4T driver check),
   buck modules. Most of this stack already runs; the PCB is an *integration*
   step, so de-risk each block before committing copper. The dual-mode front-end
   is breadboardable: CH344 dongle + '241 buffer + one TTL servo.
2. Hierarchical schematic, one sheet per block above. Pull symbols/footprints via
   easyeda2kicad (LCSC parts) or SnapEDA — and **verify every footprint against
   the datasheet drawing**; wrong footprints are the #1 first-spin killer.
3. If using JLCPCB assembly, prefer parts in their library ("Basic" parts avoid
   setup fees) and check stock *before* finalizing the schematic.
4. Set up net classes and diff-pair rules from the fab's stackup numbers; use
   KiCad's diff-pair router and length tuner; import the fab's DRC template.
5. ERC → layout → DRC → 3D check (connector collisions!) → `kkh build` produces
   the full JLCPCB order package (Gerbers, BOM, CPL, STEP, PDFs),
   git-revision-stamped — put `${KKH_VERSION_DATE}` on the silkscreen so the
   fabbed board identifies its own revision.
6. Board bring-up features: test points on every rail plus all four bus
   front-ends (both modes), power-good LEDs per rail, mounting holes, and 0 Ω
   resistor options where unsure (e.g., RS-485 termination, mode-select defaults,
   VBUS detect divider).
7. Order ~5 boards, assemble 2. Bring up power rails with USB/servos
   *disconnected* first, check every rail with a scope, then add subsystems one at
   a time — RealSense last, since it's the fussiest.

## 8. Schematic start: KiCad 10 + kevins-kicad-helpers

Toolchain: KiCad 10 with
[kevins-kicad-helpers](https://github.com/lynaghk/kevins-kicad-helpers) vendored
as a git submodule. Per its README that means `mise` for env management plus two
KiCad plugins: bennymeg/Fabrication-Toolkit and the CDFER JLCPCB-Kicad-Library
(ready-made symbols/footprints for JLC Basic parts).

The workspace is this repository (see [`README.md`](README.md)); the distilled
candidate parts are in [`parts-shortlist.md`](parts-shortlist.md).

Order of operations:

1. **Parts before wires.** `kkh-download-jlcpcb-parts-database` mirrors the
   JLCPCB catalog into SQLite with parametric columns. Resolve every "candidate"
   part in §3 into an actual LCSC part number — with stock, price, and
   Basic/Extended status — *before* drawing anything. Datasheets drive the
   schematic, not vice versa, and it prevents late "out of stock" redesigns.
2. **Golden references per block:** hub datasheet reference schematic, ROBOTIS
   U2D2 schematic (servo front-end), HD3SS3220 datasheet (USB-C upstream),
   vendor design-tool output (bucks). Collected under `datasheets/` — see
   `datasheets/README.md`; ROBOTIS does not publish the U2D2 schematic, the
   golden reference is their recommended TTL / RS-485 circuits instead
   (`datasheets/reference/robotis/`). The functional behaviour these blocks
   must deliver is written up in `FUNCTIONAL.md`.
3. **Hierarchical sheets, multi-instance:** the root sheet mirrors §1. The
   dual-mode servo front-end is *one* sheet instantiated 4×; the generic USB
   port is *one* sheet instantiated 3× — fix a bug once, every instance follows.
4. **Draw the risky blocks first** (servo front-end, USB-C upstream). The power
   sheets are cookbook copies of vendor reference designs and come after.
5. **Conventions that feed the automation:** put `max_mA` properties on the
   3.3 V ICs so `kkh-analyze-schematic` totals their draw — it sums every
   `max_mA` regardless of rail and asserts ≤ 300 mA, so it is a 3.3 V-rail
   check, not the §2 budget (that lives in FUNCTIONAL.md §4).
   Reserve the net name `VBUS` for the true upstream VBUS so its < 10 µF check
   enforces the USB device-side inrush limit — servo rails are `+12V_SERVO` /
   `+5V_SERVO` so their deliberately huge bulk banks don't trip it.
6. **`kkh check` from the first sheet onward;** pull symbols/footprints with
   `kkh-import-easyeda-parts` as parts get placed.

## 9. Biggest caveats, ranked

1. **Adapter wattage** vs. MAXN-Jetson + two servo rails of stall — do the math
   (§2); dual-rail builds escape 150 W-adapter territory fast.
2. **USB-C orientation mux**, or SuperSpeed works only one way.
3. **Bucks can't sink servo regen** — bulk caps + TVS, per connector, both rails
   (§4, §5).
4. **CH344 is a UART bridge** — per-port RS-485 transceivers *and* TTL half-duplex
   buffers are still required, and the L4T driver must be verified early (§3).
5. **RX contention on dual-mode ports** — exactly one receiver per UART RXD;
   mode-select gating is mandatory, not optional (§3).
6. **Never merge the 5 V servo rail with the 5 V USB rail** — servo stalls would
   brown out the cameras.
7. **D435 link-quality sensitivity** — pick a community-validated hub chip and
   test with the real camera at first power-on, not last.

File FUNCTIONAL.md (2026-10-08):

# FUNCTIONAL — Robot Backbone PCB

What the board *does*, seen from its connectors and from the Jetson's software.
[`HARDWARE.md`](HARDWARE.md) is the how-and-with-what; this document is the
what, so everyone — hardware, firmware, robot software — shares one picture
before the first schematic sheet is drawn. Facts below come from the datasheets
in [`datasheets/`](datasheets/README.md); anything not yet nailed down is an
explicit **Decision** (D‑n) or **Verify** (V‑n) item, collected in §10.

> **Status: draft for review.** D1 (which servos, on which rail) changes the
> power sheets and the connector story; settle it first.

## 1. The board in one paragraph

A self-powered USB 3.0 hub plus a servo-bus controller plus a power
distribution board, in one PCB. It takes 19 V from a laptop adapter, passes it
through to the Jetson Orin NX, and makes three more rails: 12 V and 5 V for
servo buses and 5 V for USB. The Jetson talks to the board over one USB-C
cable; behind that the board presents three generic USB 3.0 ports (RealSense,
ReSpeaker, whatever comes next) and four independent Dynamixel servo buses,
each usable in RS-485 or TTL mode. Every external connector is fused/limited,
ESD-protected and hot-plug tolerant. Nothing on the board runs firmware — it is
all hardware behaviour plus standard Linux USB drivers.

## 2. External interfaces

| # | Connector | Qty | Direction | Carries | Rail / limit |
|---|---|-----|---|---|---|
| J201 | 19 V IN — XT30PW-M | 1 | in | Adapter power | 19 V, adapter-rated (§4 budget); 15 A time-lag fuse, LM74700 ideal diode, SMBJ24A behind it |
| J202 | 19 V OUT — XT30PW-M (or barrel, D6) | 1 | out | Jetson carrier power | 19 V passthrough, 4 A time-lag fuse |
| J601 | USB-C upstream — 24-pin receptacle | 1 | in (host) | USB 3.0 SS + USB 2.0 from Jetson | VBUS *not* used for power (§6) |
| J801, J901, J1001 | USB-A 3.0 downstream | 3 | out (device side) | USB 3.0 SS + 2.0, generic | +5V_USB, 1.51 A each (TPS2553), switched by the hub |
| J1201, J1301, J1401, J1501 | Servo RS-485 — JST B4B-EH-A | 4 | bus | `1 GND · 2 VDD · 3 D+ · 4 D−` | +12V_SERVO, TPS16630 e-fuse 4.5 A per port |
| J1202, J1302, J1402, J1502 | Servo TTL — JST B3B-EH-A | 4 | bus | `1 GND · 2 VDD · 3 DATA` | +5V_SERVO (**D1**), TPS25961 e-fuse ≈ 2 A per port |
| — | Test points, rail LEDs, mode jumpers | — | — | Bring-up (§9) | — |

Designators are sheet × 100 + n (README.md); the servo-port x/y pairs belong to
servo port *n* = UART *n* (J12x1 = port 0, J13x1 = port 1, …).

Pinouts are ROBOTIS's (`datasheets/reference/robotis/`). RS-485 and TTL
connectors of the same servo port share one UART; one is populated with a
cable at a time (§5.3).

## 3. Block diagram

```
                J1 19V IN
                   │
     [fuse]─[ideal diode LM74700]─[TVS SMBJ24A]─[bulk]──── +19V_IN
                   │
     ┌─────────────┼──────────────────────┬──────────────────────┐
     │             │                      │                      │
 [fuse/switch]  [Buck A  LM5145]      [Buck B  LM5145]      [Buck C  TPS54560]
     │          +12V_SERVO 10–20 A     +5V_SERVO 5–10 A      +5V_USB 5 A
  J2 19V OUT       │                      │                      │
  (Jetson)   ┌─────┼─────┐          ┌─────┼─────┐         ┌──────┼──────┐
             4× [eFuse+cap+TVS]     4× [eFuse+cap+TVS]    3× [TPS2553 1.5A] [TLV62569]
             J7–J10 VDD             J11–J14 VDD           J4–J6 VBUS      +3V3 ─┐
                                                                                │
 ──────────────────────────── data ─────────────────────────────────────────────┤
                                                                                │
  J3 USB-C ──[HD3SS3220 CC + SS mux]──┐                                         │
   (Jetson host)                      ▼                   +1V1_HUB buck (TLV62569) ◄─┤
                             [TUSB8041 4-port hub]  ◄── 3V3, 1V1               │
                    ┌────────┬────────┼──────────────┐                          │
                   DS1      DS2      DS3            DS4 (USB 2.0 only)          │
                    │        │        │              │                          │
                 J4 USB-A  J5 USB-A  J6 USB-A     [CH344Q quad UART] ◄── 3V3 ───┘
                 (SS+HS)   (SS+HS)   (SS+HS)         │  │  │  │
                                            4× ─────┘  │  │  └───── UARTx: TXDx RXDx TNOWx
                                                       ▼
                                          ┌── per servo port ──────────────────────┐
                                          │  TNOWx ─┬─► SP3485EN  DE, R̄E̅ ─► A/B ─► J7+n (RS-485)
                                          │         └─► LVC2G241  2OE, 1OE̅ ─► DATA ─► J11+n (TTL)
                                          │  TXDx ──► both drivers      RXDx ◄── one receiver (mode jumper)
                                          └─────────────────────────────────────────┘
```

Net names that the automation checks (HARDWARE.md §8): `VBUS` is reserved for
the upstream USB-C VBUS; the servo rails are `+12V_SERVO` / `+5V_SERVO`; the
USB rail is `+5V_USB`; every load symbol carries `max_mA`.

## 4. Power domains

| Rail | Source | Feeds | Budget (worst case) | Protection at the load | Enable / sequencing |
|---|---|---|---|---|---|
| +19V_IN | Adapter via fuse, LM74700 ideal diode, SMBJ24A, bulk caps | Everything | Adapter rating (**D1** sets it; HARDWARE.md §2 example lands ~240 W) | Reverse polarity blocked; surge clamped ~39 V, hence 60 V-rated bucks | Present whenever the adapter is |
| +19V_JETSON (J2) | +19V_IN via fuse / load switch | Jetson carrier | ~40 W → ~2.1 A | Fuse | Same as input (Jetson boots as soon as power arrives) |
| +12V_SERVO | Buck A (LM5145 + FETs) | 4× RS-485 servo ports | Sum of stall of the RS-485 fleet, bounded by per-port e-fuses | Per port: e-fuse (TPS1663x class), ≥ 470 µF low-ESR, SMBJ13A | Up at power-on; per-port e-fuse soft-start staggers inrush (**D3**: always-on vs software-controlled) |
| +5V_SERVO | Buck B (same LM5145 design, 5 V divider) | 4× TTL servo ports | Sum of stall of the TTL fleet, bounded by per-port e-fuses | Per port: e-fuse (TPS25961 class if ≤ 2 A, else TPS1663x), ≥ 470 µF, SMBJ6.0A | As above. **Never merged with +5V_USB** |
| +5V_USB | Buck C (TPS54560) | 3× VBUS switches + 3V3 and 1V1 bucks + HD3SS3220 VDD5 | 3 × 1.5 A + 3V3 load ≈ 5 A | Per port: TPS2553 current limit 1.51 A (RILIM 16.9 kΩ), FAULT → hub `OVERCURxz` | Port VBUS switched on by the hub (`PWRCTLx`) after enumeration |
| +3V3 | TLV62569 from +5V_USB | Hub I/O, HD3SS3220, CH344Q, transceivers, buffers | < 0.5 A | — | Up with +5V_USB |
| +1V1_HUB | TLV62569 buck from +5V_USB, 1.09 V (82 k / 100 k), ferrite into the hub's VDD pins (**D7**: the EVM's TPS74801 LDO is the fallback if core noise is a problem) | Hub core | ≤ 778 mA per DS | — | Up with +5V_USB; GRSTz released ≈ 100 ms later by its RC |
| VBUS (upstream) | Jetson, through J3 | HD3SS3220 `VBUS_DET` (900 kΩ) and TUSB8041 `USB_VBUS` (90.9 kΩ divider) — **detection only** | ~0 | < 10 µF total on this net (USB inrush rule; `kkh` checks it) | — |

### 4.1 Fleet worksheet (input to D1)

ROBOTIS's own figures (`datasheets/reference/robotis/dxl_x_info.yml`): stall
current at rated voltage, and — the important part — which rail each family
actually wants.

| Family | Bus | Input voltage (recommended) | Stall current | Notes |
|---|-----|---|---|---|
| XL330-M077 / M288 | TTL, **3.3 V logic** (5 V compatible) | 3.7–6.0 V (**5 V**) | 1.11 A @ 3.7 V | The only family that is genuinely a 5 V servo |
| XC330-M181 / M288 | TTL, 3.3 V logic | 3.7–6.0 V (**5 V**) | 1.34 A @ 3.7 V | |
| XC330-T181 / T288 | TTL, 5 V logic | 6.5–12.0 V (**11.1 V**) | 0.61 A @ 9 V | Same 3-pin EH connector as the 5 V units |
| XL430-W250 (and 2XL430) | TTL, 5 V logic | 6.5–12.0 V (**11.1 V**) | 1.0 A @ 9 V | |
| XC430-W150 / W240 (and 2XC430) | TTL, 5 V logic | 6.5–14.8 V (**12 V**) | 1.1 A @ 9 V | |
| XM430-W210 / W350 | RS-485 (-R) **or** TTL (-T) | 10–14.8 V (**12 V**) | 2.1 A @ 11.1 V | |
| XH430-W210 / W350 | RS-485 or TTL | 10–14.8 V (**12 V**) | 1.2 A @ 11.1 V | |
| XH430-V210 / V350 | RS-485 | **24 V** | 0.7 A @ 24 V | Not supported by this board (no 24 V rail) |
| XM540-W150 / W270 | RS-485 or TTL | 10–14.8 V (**12 V**) | 4.2 A @ 11.1 V | |
| XH540-W150 / W270 | RS-485 or TTL | 10–14.8 V (**12 V**) | 4.5 A @ 11.1 V | |
| XW430 / XW540-T | RS-485 | 10–14.8 V (**12 V**) | 1.2 / 4.5 A | IP-rated |

Baud: 9.6 kbps – 4 Mbps (X330) or 4.5 Mbps (others). Protocol 2.0 throughout.

**What this means (D1):** HARDWARE.md pairs "TTL ↔ 5 V" and "RS-485 ↔ 12 V",
but only the X330-M family is a 5 V servo. Every other TTL X-series servo
(XL430, XC430, XM430-T, XH430-W-T, XC330-T) is a **12 V servo on the same
3-pin EH connector** — the connector keying does *not* separate 5 V from 12 V
TTL servos. The board therefore has to choose what VDD its 3-pin ports carry:

- **(a) 5 V** — as drafted. Supports X330-M only on the TTL ports; every 12 V
  servo must be an RS-485 variant on the 4-pin ports.
- **(b) 12 V on both connector types** — one servo rail, one buck; TTL ports
  serve XL430/XC430/XM430-T; X330-M units are then *excluded* (plugging one in
  destroys it — no keying protects against it).
- **(c) Per-port VDD select (jumper)** — flexible, but the failure mode of (b)
  becomes a jumper mistake. Only worth it with an idiot-proof mechanism.

Pick the fleet, then the option; the power sheets follow from that.

## 5. Servo subsystem — behaviour

### 5.1 Topology

One CH344Q on hub port DS4 (USB 2.0 High-Speed, 480 Mbps) exposes **four
independent UARTs**. UARTx drives servo port *x* (x = 0..3). The mapping UART
index → physical port is fixed by copper, so software may rely on it (contrast
with the USB-A ports, §6.3). Each port has both a 4-pin RS-485 and a 3-pin TTL
connector; both physical layers hang off the same UART.

### 5.2 Direction control — TNOW

- CH344Q provides **per-UART `TNOWx`** on the `DTRx/TNOWx/GPIOx` pins (Q
  package pins 39, 18, 19, 34). Each pin becomes TNOW instead of DTR when the
  chip sees a **pull-down resistor on that pin at power-on** (4.7 kΩ to GND
  is the value the datasheet uses for the same mechanism on the L variant).
  Per-pin, independent, no software involvement — the WCH `ch343` driver
  contains no TNOW/RS-485 handling at all, which is what we want.
- Semantics (datasheet, translated): "RS-485 transmit/receive control pin of
  the corresponding UART" — asserted while the UART is shifting out data.
- **V1 — polarity.** The Chinese CH344DS1 does not state the level explicitly.
  WCH's family convention is active-high (matches DE on a transceiver
  directly); confirm on the existing CH344Q dongle with a scope before the
  front-end sheet is finalised — if it is active-low, one inverter per port or
  the two-chip '126/'125 alternative fixes it.
- **V2 — release timing.** How long after the last stop bit TNOW de-asserts is
  not specified. Dynamixel **Return Delay Time** defaults to 250 × 2 µs =
  500 µs but can be set to 0 (2 µs) — at 1 Mbps that is two bit times. Until
  the release latency is measured, the servo software keeps Return Delay Time
  at a value comfortably above it (default is fine). This is the one place the
  board's behaviour and the servo configuration have to agree.

### 5.3 Front-end per port

Mirrors ROBOTIS's recommended circuits exactly (`datasheets/reference/robotis/`),
with TNOW playing the role of ROBOTIS's `TX_Enable`:

| Signal | RS-485 path (SP3485EN, 3.3 V) | TTL path (SN74LVC2G241, 3.3 V) |
|---|---|---|
| TXDx | `DI` | `2A` → `2Y` = DATA |
| Transmit gate | `DE` = TNOWx (active-high) | `2OE` = TNOWx (active-high) |
| Receive gate | `R̄E̅` = TNOWx **when this mode is selected**, else tied high (receiver off) | `1OE̅` = TNOWx **when this mode is selected**, else tied high (receiver off) |
| RXDx | `RO` | `1Y` |
| Bus | A = D+ (pin 3), B = D− (pin 4) | DATA (pin 3), 10 kΩ pull-up to 3.3 V |
| Pull-ups | RXDx 10 kΩ to 3.3 V (CH344Q has internal pull-ups on RXD0–2 but **RXD3 needs an external one** — fit all four for uniformity) | same RXDx pull-up; TNOW line 10 kΩ pull-down (idle = receive, as ROBOTIS) |
| Protection | SM712 on A/B, 120 Ω termination as 0 Ω-option | 5 V-working TVS on DATA, ~10–22 Ω series |

Behavioural consequences:

- **Transmit:** TNOW high → both drivers active. The RS-485 driver copies the
  packet onto A/B, the '241 copies it onto DATA. The unused connector carries a
  harmless copy.
- **No echo, either mode:** TNOW high also disables *both* receivers, so the
  UART never hears its own packet. Echo behaviour is identical on all four
  ports and both modes; the servo software needs no per-port special-casing.
- **Receive:** TNOW low → drivers Hi-Z, the *selected* receiver drives RXDx.
  The other receiver is held disabled (Hi-Z) — its output is wire-ORed on the
  same RXDx net, which is safe precisely because at most one is ever enabled.
- **Mode select (D2):** a per-port 3-pin jumper / solder bridge routes TNOWx
  to exactly one receiver-enable and leaves the other pulled inactive. Default
  bridge position is per fleet (D1). Software control via CH344Q GPIO is
  possible later (the CTS/RTS pins double as GPIO0–7) but ROBOTIS's own U2D2
  keeps *both* receivers enabled and relies on unique IDs — we deliberately
  don't, because two enabled receivers wire-ORed on RXD corrupt each other's
  packets and the U2D2 documents that failure mode.
- **Levels:** everything runs at 3.3 V (CH344Q native). ROBOTIS specifies the
  3.3 V '241 circuit for X330 and the 5 V one for the rest; LVC inputs are
  5 V-tolerant and a 3.3 V high clears the 5 V-logic servos' TTL threshold, so
  the 3.3 V build serves both — the pull-up on DATA stays at 3.3 V.
- **Speed:** CH344Q ≤ 6 Mbps, SP3485EN 10 Mbps, LVC2G241 far above — the
  4.5 Mbps Dynamixel ceiling is covered on every port.

### 5.4 Servo power ports

Per port, on the rail the port's mode uses: e-fuse → local bulk capacitor
(≥ 470 µF low-ESR, at the connector) → TVS → connector VDD.

- **Overcurrent / short on one bus:** its e-fuse limits, then trips; the other
  three buses and the rest of the board are unaffected (**D3**: latch-off with
  manual reset vs auto-retry; and whether the enable is software-controlled for
  a per-bus e-stop and staggered power-up).
- **Regenerative back-EMF:** the buck cannot sink; the local + shared bulk
  absorbs, the TVS clamps the rest (SMBJ13A on 12 V, SMBJ6.0A on 5 V).
- **Star distribution:** each port gets its own pour from the buck's bulk bank
  so one bus's stall sag does not appear on another.

## 6. USB subsystem — behaviour

### 6.1 Upstream (J3, USB-C, Jetson is host)

HD3SS3220 in **UFP, GPIO mode** — no I2C, no software: `PORT` tied low (UFP),
`ADDR` left open (GPIO mode), `ENn_CC` low (enabled), `VBUS_DET` from the
connector's VBUS through 900 kΩ. The CC logic detects attach and orientation;
the integrated 2:1 mux routes the live SuperSpeed pair to the hub. Result:
USB 3.0 works in **both plug orientations**. `CURRENT_MODE` is don't-care in UFP.

**VBUS is never a power source.** It only reaches the two detection inputs
(HD3SS3220 `VBUS_DET`, TUSB8041 `USB_VBUS` divider). The board is self-powered:
the Jetson cannot back-power it, it cannot back-power the Jetson, and the
< 10 µF rule on the `VBUS` net keeps the Jetson's port happy at attach.

### 6.2 Hub (TUSB8041)

- Self-powered 4-port hub; VID/PID and port configuration by **pin strapping**
  (no EEPROM, no I2C) unless a reason appears (**D5**).
- DS1–DS3 → J4–J6, full SuperSpeed + High-Speed. DS4 → CH344Q, USB 2.0 only;
  its SS pins are unused (**V5**: the datasheet has no explicit unused-SS-port
  note — take the termination from the EVM guide or TI E2E before ERC).
- Per port: `PWRCTLx` → VBUS switch `EN`; `OVERCURxz` ← switch fault. The hub
  turns port power on after the upstream connection is established and reports
  over-current to the host as a standard hub status change, so Linux logs the
  event and the OS/driver can react — no custom software.
- Rails: 3.3 V I/O + 1.1 V core (LDO per DS), 24 MHz crystal, `GRSTz` reset.
- Suspend: the hub follows USB suspend from the host; downstream port power
  behaviour in suspend is a strap option (**D5**).

### 6.3 Generic downstream ports (J4–J6)

- Identical wiring, identical 1.5 A limit (TPS2553, `RILIM` 16.9 kΩ →
  `IOS = 23950 / RILIM^0.977 mA` = 1.51 A; the SY6280 of the first draft had no
  fault output, so the hub could never have seen an over-current), identical
  ESD (TPD4E05U06 on SS, USBLC6-2 on D+/D−). Any device fits any port.
- **Software contract:** devices are identified by **VID/PID** (as the existing
  ReSpeaker udev rule already does). Nothing may key on `/dev/serial/by-path`
  or USB topology for J4–J6, because a device can move ports. The servo UARTs
  are the exception: CH344Q interface *n* ↔ servo port *n* is fixed.

### 6.4 What Linux sees

```
Jetson USB-C (host)
└── TUSB8041 hub (USB 3.0 + companion USB 2.0 hub, as all SS hubs)
    ├── port 1: whatever is on J4 (e.g. RealSense D435 — SS)
    ├── port 2: whatever is on J5 (e.g. ReSpeaker — HS)
    ├── port 3: whatever is on J6
    └── port 4: CH344Q → 4 serial interfaces (ttys via WCH ch343 driver — already verified on this kernel)
```

## 7. Power-up, hot-plug and fault behaviour

| Event | Board behaviour |
|---|---|
| Adapter connected | Ideal diode conducts, bucks start (all rails up, within their soft-start), Jetson receives 19 V and boots. Servo rails are live before any USB activity; servo ports power up staggered by e-fuse soft-start (D3). |
| Reverse-polarity adapter | LM74700 keeps the FET off — nothing conducts. |
| Input surge / adapter overshoot | SMBJ24A clamps; downstream bucks are 60 V-rated so they survive the clamp voltage. |
| USB-C plugged (either orientation) | HD3SS3220 detects, selects SS lane; hub enumerates as self-powered; hub enables J4–J6 VBUS. |
| Device plugged into J4–J6 | Enumerates. Over 1.5 A → switch limits, asserts fault → hub reports over-current → host disables the port. |
| Servo plugged in hot | Local bulk cap charges through the e-fuse's current limit (no spark-inrush on the shared rail). |
| Servo stall on bus *n* | Rail sags locally; star pour + local bulk keep buses ≠ *n* clean; per-port e-fuse bounds the current. |
| Servo back-driven / decelerating | Rail rises; caps absorb, TVS clamps; the buck stops switching (**V3**: confirm LM5145 output-overvoltage behaviour). |
| Crushed servo cable (short) on bus *n* | e-fuse on bus *n* trips; other buses and the robot keep running. |
| Jetson powered off / USB-C unplugged | Servo rails stay up (they don't depend on USB); hub drops port power per its strap; nothing back-feeds. |

## 8. What software needs to know (contract)

1. Three generic USB 3.0 ports; identify devices by VID/PID only.
2. Four servo buses = four CH344Q UART interfaces, fixed index ↔ port.
3. Both bus modes look identical to software: same framing, no echo, same
   direction timing. Only the physical layer (jumper) differs.
4. Keep Dynamixel Return Delay Time at default until V2 is measured.
5. Over-current on a USB port arrives as a normal hub over-current event.
6. Servo bus power is not software-visible unless D3 chooses GPIO-controlled
   e-fuses (then: per-bus enable/e-stop, staggered start).

## 9. Bring-up and test features

Test point on every rail and on TXD/RXD/TNOW/A/B/DATA of every servo port;
power-good LED per rail; 0 Ω options for RS-485 termination, mode-select
defaults and the VBUS-detect dividers; `${KKH_VERSION_DATE}` on the silkscreen;
mounting holes. Bring-up order per HARDWARE.md §7: rails alone → scope → hub →
servos → RealSense last.

## 10. Open decisions and verifications

| ID | Item | Affects | Owner |
|----|---|---|---|
| **D1** | Servo fleet: models × count per bus → rail per connector type (§4.1 options a/b/c), buck currents, e-fuse classes, adapter wattage | Power sheets, connectors, budget | Robot design |
| **D2** | Mode-select mechanism: solder bridge / jumper (recommended) vs CH344Q GPIO | Servo-port sheet | HW |
| **D3** | Servo e-fuse behaviour: latch vs auto-retry; enable always-on vs GPIO (per-bus e-stop, staggered start) | Servo power sheet, software contract §8.6 | HW + SW |
| **D4** | Hub chip: TUSB8041 vs alternatives, after checking librealsense issue history | Hub sheet | HW |
| **D5** | Hub configuration: pure pin-strap vs EEPROM (custom VID/PID, suspend port-power behaviour) | Hub sheet | HW |
| **D6** | Jetson carrier model → accepted input range/polarity, J202 connector type | Input sheet | Robot design |
| **D7** | +1V1_HUB: TLV62569 buck (drawn) vs TPS74801 LDO as on the TI EVM — decide after measuring core-rail noise / USB 3 eye | Hub sheet | HW |
| **V1** | TNOW polarity on CH344Q (scope the existing dongle) | Front-end gating; may add inverter | HW |
| **V2** | TNOW release latency after stop bit vs Dynamixel Return Delay Time | Software contract §8.4 | HW + SW |
| **V3** | LM5145 behaviour on output overvoltage from regen (stops switching?) | Servo rail protection | HW |
| **V4** | Every imported footprint against its datasheet drawing (HARDWARE.md §7) | Everything | HW |
| **V5** | Termination of the unused SS pins on hub port DS4 | Hub sheet | HW |

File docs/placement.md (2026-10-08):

# Placement diagram — robot backbone PCB

The board floorplan that `backbone/backbone.kicad_pcb` implements. Every
footprint from the schematic is on the board with its net and schematic link,
packed block by block into one placement rule area per hierarchical sheet. The
board is **not routed**; this is the starting point for layout, following the
rules in HARDWARE.md §6.

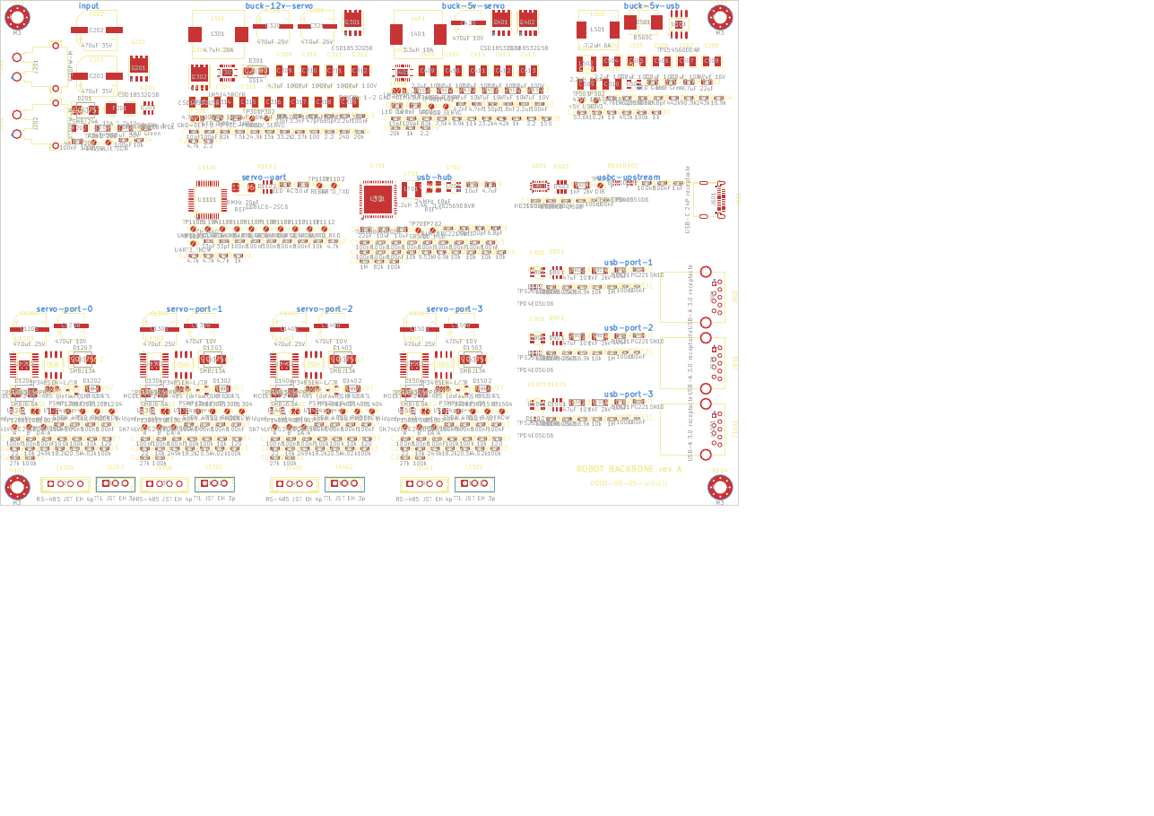
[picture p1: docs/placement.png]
placement


`placement.svg` is the same view as vector graphics (F.Cu, F.SilkS, Edge.Cuts,
Cmts.User region labels). Regenerate both with
`tools/schematic-gen/pcb.py` and `kicad-cli pcb export svg …` (see
`tools/schematic-gen/README.md`).

## Floorplan

Board 190 × 130 mm, 4 layers (F.Cu / In1.Cu = GND / In2.Cu = PWR / B.Cu),
origin top-left, M3 mounting holes 4.5 mm in from each corner. Coordinates in mm.

| Region (rule area name) | Sheet | x | y | Edge connectors |
|---|---|---|---|---|
| `input` | 2 input | 0–46 | 0–78 | J201 19 V IN, J202 19 V OUT on the **left** edge |
| `buck-12v-servo` | 3 | 46–98 | 0–44 | — |
| `buck-5v-servo` | 4 | 98–146 | 0–44 | — |
| `buck-5v-usb` | 5 | 146–190 | 0–44 | — |
| `servo-uart` | 11 | 46–90 | 44–78 | — |
| `usb-hub` | 7 | 90–134 | 44–78 | — |
| `usbc-upstream` | 6 | 134–190 | 44–66 | J601 USB-C on the **right** edge |
| `usb-port-1/2/3` | 8–10 | 134–190 | 66–83 / 83–100 / 100–117 | J801, J901, J1001 USB-A 3.0 on the **right** edge |
| `servo-port-0..3` | 12–15 | 0–33.5 / 33.5–67 / 67–100.5 / 100.5–134 | 78–130 | J1x01 RS-485 + J1x02 TTL on the **bottom** edge |
| `usb_section` (keep-out anchor, no placement source) | — | 90–190 | 44–130 | used by `backbone.kicad_dru`: servo-rail copper may not enter it |

Why this shape (HARDWARE.md §6):

- **Power enters on the left and flows right along the top.** Input
  protection and the three bucks sit in one row; their switch nodes and
  inductors are as far from the USB section as the board allows. The 19 V
  input bulk bank is next to the ideal diode, the servo bulk banks next to their
  bucks (star distribution starts there).
- **The hub sits between the USB-C upstream and the three USB-A ports**, so
  every SuperSpeed pair is short and stays on F.Cu over the In1.Cu ground plane.
  The whole USB block is the `usb_section` rule area: PWR_SERVO copper is barred
  from it, so servo return currents never flow under the USB pairs.
- **The four servo ports are a row along the bottom edge**, each with its own
  e-fuses, 470 µF polymer caps and TVS next to its two connectors, with the
  CH344 directly above them (short TXD / RXD / TNOW lines, TTL DATA runs short).
- The 3-pin / 4-pin EH housings alternate along the bottom edge: RS-485 (12 V)
  and TTL (5 V) connectors of the same port are side by side so the keying by
  housing size stays obvious.

## What the generator placed and what is left for layout

Done by `tools/schematic-gen/pcb.py`:

- all 430 footprints with nets, schematic paths, sheet names, LCSC / fields
  (schematic parity: 0 issues), DNP and exclude-from-BOM attributes;
- edge connectors rotated so their pads face inboard and the mating face points
  off the edge, every other part packed largest-first inside its region;
- placement rule areas (source = sheet name) and the `usb_section` area;
- board outline, four M3 holes, `${KKH_VERSION_DATE}` and the revision text on
  F.SilkS, `JLCJLCJLCJLC` order-number placeholder on B.SilkS.

Still to do in the PCB editor (DRC on the placed board: 499 unconnected pads,
37 clearance errors at IC pads from the net-class clearances, 4 annular-ring
errors inside the USB-C footprint, silkscreen overlaps from the dense packing):

1. Tidy placement within each region: the packer is a grid, not a layout.
   Decoupling caps belong at their pins, the buck input loops want to be tiny,
   the hub crystal next to XI/XO, the ESD arrays at the connectors.
2. Route: USB3_SS / USB2_HS geometry from the JLCPCB impedance calculator
   (JLC04161H-7628) into the net classes, polygons for the 19 V and servo
   rails, star pours per port from each buck's bulk bank, thermal vias under
   the QFN / HTSSOP / SON pads.
3. Scope the SW_NODE / PWR_SERVO class clearances and the 3 mm
   `sw_node_away_from_signals` rule to tracks and zones (`A.Type` conditions in
   `backbone.kicad_dru`) so they stop firing at the ICs' own pins.
4. V4: check every imported footprint against its datasheet drawing,
   especially the USB-C QT shell legs (two overlapping oval PTH pads per side)
   and the right-angle connectors' orientation on the edges.
5. Enter the JLC04161H-7628 physical stackup in Board Setup.

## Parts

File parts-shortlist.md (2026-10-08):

# Parts shortlist (JLCPCB catalog query results)

Auto-generated from `jlcpcb_parts.db` (jlcparts snapshot: 2026-08-29T14:48:52Z) by
querying per-block candidates from HARDWARE.md section 3. Raw query output --
curated picks are marked separately. Price is the qty-1 tier in USD; Lib
Basic = no extended-part fee at JLCPCB assembly. Stock changes daily; re-check
before ordering.

## Curated picks

Selection criteria: real datasheet + reference design available, stock depth,
price, Basic where possible. All main ICs are Extended parts (per-line feeding
fee at assembly -- normal for a board like this). **Every pick still needs its
datasheet read before the schematic is drawn.**

| Block | Pick | LCSC | USD@1 | Why / caveats |
|---|---|---|---|---|
| USB 3.0 hub | TUSB8041IRGCR | C544686 | 4.62 | Industrial temp, best docs + TI reference schematic. Cheap alt: RTS5411S (C5356838, $2.09), ubiquitous in consumer hubs; Cypress CYUSB3304 (C462531) also credible. Cross-check chosen chip against librealsense issue reports before committing. |
| USB-UART (4x UART) | CH344Q | C2988084 | 3.42 | Description lists RS-485 mode. **Verify per-UART TNOW pins in the WCH datasheet** -- that's the load-bearing feature. CH344L (C2887250) alt; CH343P (C2846043) single-bus fallback. |
| RS-485 transceiver (x4) | SP3485EN-L/TR | C8963 | 0.31 | **Basic part**, 3.3 V, 10 Mbps (> 4.5 Mbps Dynamixel max), DE/RE pins for TNOW. 395k stock. |
| TTL half-duplex buffer (x4) | SN74LVC2G241DCUR | C10430 | 0.51 | The one-chip front-end (complementary OEs). Alt: SN74LVC1G126 (TX, OE active-high) + SN74LVC1G125 (RX, OE active-low) -- same TNOW drives both, no inverter. |
| Buck controller 12 V | LM5145RGYR | C485912 | 2.45 | 6-75 V in, external FETs, WEBENCH support. Consolidation option: LM5143 (C5219297) is a *dual* controller -- one chip could run both servo rails. |
| Buck 5 V USB | TPS54560DDAR | C31966 | 1.02 | 60 V in, 5 A, SOIC-8-EP, 47k stock. Bound port limits so the sum fits (HARDWARE.md section 3). |
| Buck 3.3 V | TLV62569DBVR | C141836 | 0.07 | 2 A, Vin <= 5.5 V -- fed from the quiet 5 V USB rail. |
| eFuse, servo buses | TPS16630PWPR / TPS25961DRVR | C1849461 / C5571272 | 2.50 / 0.39 | Current class must match the bus: TPS1663x (60 V, ~6 A class) for 12 V buses; TPS25961 (19 V, <= 2 A) only for light 5 V TTL buses. Recompute per fleet; polyfuse + TVS is the budget fallback. |
| VBUS switch (x3) | TPS2553DBVR | C55266 | 0.54 | **Changed 2026-10-08 while drawing usb-port:** SY6280AAC (C55136, still imported as the alternate) has no fault output, so the hub's OVERCURxz could never see an over-current. TPS2553: FAULT open-drain → hub, EN active high from PWRCTLx, RILIM 16.9 kΩ → 1.51 A. |
| USB-C CC + SS mux | HD3SS3220RNHR | C165155 | 1.89 | The standard UFP orientation part; 5.5k stock. |
| Ideal diode ctrl | LM74700QDBVRQ1 | C2941042 | 1.06 | 65 V, drives external NFET (pick FET by input current). |
| TVS, rails | SMBJ24A / SMBJ13A / SMBJ6.0A | C19077578 / C19077567 / C19077560 | ~0.05 | All **Basic** (hongjiacheng). 19 V in / 12 V servo / 5 V servo respectively. |
| ESD, USB3 SS pairs | TPD4E05U06DQAR | C138714 | 0.08 | TI genuine, 0.5 pF, 94k stock. |
| ESD, USB2 + TTL DATA | USBLC6-2SC6 | C2687116 | 0.05 | UMW clone; TI/ST original if preferred. |
| ESD, RS-485 | SM712 | C7420375 | 0.07 | **Basic**, asymmetric -7/+12 V, made for RS-485. |
| Servo conn, RS-485 (x4) | B4B-EH-A(LF)(SN) | C160258 | 0.08 | JST EH 4-pin top-entry. Side-entry alt: S4B-EH (C265068). |
| Servo conn, TTL (x4) | B3B-EH-A(LF)(SN) | C160259 | 0.06 | JST EH 3-pin top-entry. Side-entry alt: S3B-EH (C263754). EHR-3/EHR-4 housings (C161660 etc.) are the *cable-side* parts for building servo leads. |
| 19 V input | XT30PW-M | C431092 | 0.38 | PCB right-angle, 15 A. **Do not use a barrel jack here** -- DC-005 class is ~3 A, a 150-240 W input needs 8-13 A. Adapter mates via a pigtail. |
| 19 V out (Jetson) | XT30PW-M or DC-005-A200 | C431092 / C720557 | 0.38 / 0.14 | ~2.1 A at 40 W, so the 3 A barrel is acceptable here if you want a barrel-to-barrel cable; XT30 is more robust. |
| USB-A 3.0 recept (x3) | HC-ST-003-01-J | C2845330 | 0.13 | 9-pin THT right-angle, shell stakes. |
| USB-C recept (upstream) | TYPE-C 24P QT | C2681555 | 0.54 | **Must be 24P full-featured female** for SuperSpeed -- the plentiful 16P parts are USB2-only, and one 24P hit (C3151751) is male. Alt: C456013. |

### Parts added during schematic capture (resolved against JLCPCB's live catalog, 2026-10-08)

`jlcpcb_parts.db` was unusable that day (see README.md), so these were looked up
one by one with JLCPCB's component search; stock is the figure returned then.
Values for the bucks are the TI reference designs (LM5145 datasheet application
circuits 1 and 2, TPS54560 datasheet figure 33, TLV62569 §8.2); E96 resistors
are the UNI-ROYAL 0603WAF series.

| Role | Part | LCSC | Stock | Note |
|---|---|---|---|---|
| Buck + ideal-diode N-FET (×5) | CSD18532Q5B, 60 V, 2.5 mΩ, SON 5×6 | C882766 | 2426 | TI, same package as the datasheet's CSD18563Q5A; RILIM recomputed for 2.5 mΩ (240 Ω / 150 Ω) |
| 12 V buck inductor | TMPA1265SP-4R7MN-D 4.7 µH 20 A / 25 A sat | C2880057 | 1243 | TAI-TECH, 13.5 × 12.6 mm like the Cyntec part TI lists |
| 5 V servo buck inductor | TMPC1265HP-3R3MG-D 3.3 µH 18 A / 30 A sat | C357272 | 753 | |
| 5 V USB buck inductor | 7447798720 7.2 µH 6 A | C105681 | 406 | Würth, the TPS54560EVM part |
| 3V3 / 1V1 buck inductor (×2) | SMNR4020-2.2UH 2.2 µH 3.4 A | C135262 | 103006 | |
| Catch diode, TPS54560 | B560C-13-F 60 V 5 A SMC | C85100 | 150633 | Diodes Inc, the EVM part |
| 100 V input ceramics | C3225X7S2A475KT000N 4.7 µF 100 V 1210 (×5) / C3225X7R2A225KT5L0U 2.2 µF 100 V 1210 (×9) | C342614 / C76686 | 4656 / 1572 | TDK |
| Buck output ceramics | GRM32ER61C476KE15L 47 µF 16 V 1210 (×7) / CS3225X7R226K250NRL 22 µF 25 V 1210 (×2) | C77101 / C2918511 | 225941 / 85727 | Murata / Samwha |
| 12 V bulk + per-port (×6) | MA25V470M8X10 470 µF 25 V polymer, 25 mΩ | C46550466 | 128243 | jieerrui |
| 5 V bulk + per-port (×5) | MA10V470M6X8 470 µF 10 V polymer, 20 mΩ | C46550459 | 81105 | |
| 19 V input bulk (×2) | RVE470UF35V167RV084 470 µF 35 V, 230 mΩ | C5155332 | 8698 | KNSCHA |
| Input fuse | 0453015.MR 15 A time-lag 2410 | C178997 | 530 | Littelfuse |
| Jetson fuse | 1206TD-4A 4 A time-lag 1206, 72 V | C2838918 | 374 | prosemi |
| Hub crystal | X322524MRB4SI 24 MHz 18 pF 3225 | C70571 | 44317 | YXC; 30 pF load caps |
| CH344 crystal | X50328MSB2GI 8 MHz 20 pF 5032 | C115962 | Basic | CDFER library; 33 pF load caps |
| Ferrites | BLM18PG221SN1D 0603 1.4 A (hub core) / BLM21PG221SN1D 0805 2 A (USB-A VBUS ×3) | C80165 / C85840 | 317212 / 262582 | Murata |
| RS-485 TVS (×4) | PSM712-LF-T7 | C32677 | Basic | ProTek SM712 equivalent, CDFER library |
| TTL DATA TVS (×4) | SMF5.0A SOD-123FL | C19077497 | Basic | hongjiacheng, CDFER library |
| VCC bias diode (12 V buck) | SS14 | C2480 | Basic | |
| Rail LEDs (×6) | 0805 green | C2297 | Basic | |
| E96 resistors 0603 1 % | 2.37k C25964 · 24.9k C25962 · 80.6k C23249 · 33.2k C23003 · 23.2k C23346 · 4.42k C23043 · 422 C23052 · 402 C23049 · 90.9k C23129 · 53.6k C23074 · 10.2k C22772 · 16.9k C25954 · 243k C23351 · 442k C23175 · 9.53k C23127 · 4.02k C23040 · 18.2k C22892 · 20.5k C22910 · 249k C22918 · 453k C25818 · 910k C23263 | — | ≥ 250 each | UNI-ROYAL 0603WAF |
| E24 resistors / ceramics | JLC Basic parts from the CDFER library (`tools/schematic-gen/common.py` has the full value → LCSC table) | — | Basic | |

Raw query noise to ignore below: HD3SS6126 and PTN36241G in the hub tables are
*redrivers*, not hubs; the "TPS16-N1F1" rows in the eFuse table are USB-C
connectors; the IDC headers in the DC-jack table matched a loose subcategory
filter; C598201 in the USB-A table is a Micro-B.

### USB 3.0 hub controller (known candidates)

| LCSC | MPN | Maker | Pkg | USD@1 | Stock | Lib | Description | DS |
|---|---|---|---|---|---|-----|---|---|
| C390630 | GL3523-OTY30  | Genesys Logic | QFN-76-EP(9x9) | 2.46  | 15315 | Ext | 4 4.75V~5.5V Transceiver USB 3.1 QFN-76-EP(9x9) USB Converters ROHS | [ds](https://jlcpcb.com/api/file/downloadByFileSystemAccessId/8588893245463515136) |
| C7501408  | GL3510-OSY52  | Genesys Logic | QFN-64 | 1.45  |  4007 | Ext | 0℃~+70℃ 2 4.75V~5.25V 5Gbps USB 3.1 QFN-64 USB Converters ROHS | [ds](https://jlcpcb.com/api/file/downloadByFileSystemAccessId/8590908898847379456) |
| C19725282 | GL3523-OTY3C  | | QFN-76(9x9) | 2.13  |  2619 | Ext | 0℃~+70℃ 4 4.75V~5.25V Transceiver USB 3.1 QFN-76(9x9) USB Converters R | [ds]() |
| C5159024  | RTS5411T-GR | Realtek Semicon | QFN-76(9x9) | 1.74  |  2259 | Ext | 0℃~+70℃ 1.1V、3.3V Hub USB 3.2 QFN-76(9x9) USB HUB Controllers ROHS | [ds](https://jlcpcb.com/api/file/downloadByFileSystemAccessId/8589834533467295744) |
| C544686 | TUSB8041IRGCR | | QFN-64-EP(9x9) | 4.62  |  1865 | Ext | -40℃~+85℃ 0.99V~1.26V、3V~3.6V 33mA 4 778mA Hub I2C、SMBus USB 2.0、USB 3 | [ds](https://www.ti.com/cn/lit/gpn/tusb8041) |
| C5356838  | RTS5411S-GR | | QFN-76 | 2.09  |  1100 | Ext | 0℃~+70℃ 4 4.45V~5.25V USB 3.1 USB Hub QFN-76 USB Converters ROHS | [ds](https://jlcpcb.com/api/file/downloadByFileSystemAccessId/8589838617779597312) |
| C633621 | USB5744-I/2G  | Microchip Tech  | HVQFN-56-EP(7x7) | 4.90  | 276 | Ext | 0℃~+70℃ 1.2V、3.3V 5Gbps Hub USB 2.0、USB 3.2 HVQFN-56-EP(7x7) USB HUB C  | [ds](https://jlcpcb.com/api/file/downloadByFileSystemAccessId/8576734294138167296) |
| C626715 | USB5744T-I/2G | Microchip Tech  | VQFN-56-EP(7x7)  | 5.22  | 203 | Ext | -40℃~+85℃ 1.2V、3.3V 5Gbps Hub USB 2.0、USB 3.2 VQFN-56-EP(7x7) USB HUB | [ds](https://jlcpcb.com/api/file/downloadByFileSystemAccessId/8589805030820769792) |

### USB 3.0 hub controller (generic search)

| LCSC | MPN | Maker | Pkg | USD@1 | Stock | Lib | Description | DS |
|---|---|---|---|---|---|-----|---|---|
| C5159024 | RTS5411T-GR | Realtek Semicon | QFN-76(9x9) | 1.74  |  2259 | Ext | 0℃~+70℃ 1.1V、3.3V Hub USB 3.2 QFN-76(9x9) USB HUB Controllers ROHS | [ds](https://jlcpcb.com/api/file/downloadByFileSystemAccessId/8589834533467295744) |
| C544686  | TUSB8041IRGCR | | QFN-64-EP(9x9) | 4.62  |  1865 | Ext | -40℃~+85℃ 0.99V~1.26V、3V~3.6V 33mA 4 778mA Hub I2C、SMBus USB 2.0、USB 3 | [ds](https://www.ti.com/cn/lit/gpn/tusb8041) |
| C5356838 | RTS5411S-GR | | QFN-76 | 2.09  |  1100 | Ext | 0℃~+70℃ 4 4.45V~5.25V USB 3.1 USB Hub QFN-76 USB Converters ROHS | [ds](https://jlcpcb.com/api/file/downloadByFileSystemAccessId/8589838617779597312) |
| C462531  | CYUSB3304-68LTXC | Infineon Cypress Semicon | QFN-68 | 3.43  | 626 | Ext | -40℃~+85℃ 1.2V、3.3V、5V 4 5Gbps Hub I2C USB 3.0 QFN-68 USB HUB Controll  | [ds](https://jlcpcb.com/api/file/downloadByFileSystemAccessId/8589838206326763520) |
| C701818  | HD3SS6126RUAR | | WFQFN-42-EP(3.5x9) | 1.57  | 566 | Ext | 0℃~+70℃ 10Gbps 3.3V 3mA Hub USB 2.0、USB 3.0 WFQFN-42-EP(3.5x9) USB HUB | [ds](https://www.ti.com/cn/lit/gpn/hd3ss6126) |
| C633621  | USB5744-I/2G | Microchip Tech | HVQFN-56-EP(7x7) | 4.90  | 276 | Ext | 0℃~+70℃ 1.2V、3.3V 5Gbps Hub USB 2.0、USB 3.2 HVQFN-56-EP(7x7) USB HUB C  | [ds](https://jlcpcb.com/api/file/downloadByFileSystemAccessId/8576734294138167296) |
| C2678039 | TUSB8020BIPHPRQ1 | Texas Instruments | HTQFP-48(7x7) | 6.27  | 253 | Ext | -40℃~+85℃ 0.99V~1.26V、3V~3.6V 2 5Gbps Hub I2C、SMBus USB 3.0 HTQFP-48(7  | [ds](https://www.ti.com/cn/lit/gpn/tusb8020b-q1) |
| C2675243 | PTN36241GHXZ | NXP Semicon | XQFN-12(1.7x2) | 1.98  | 207 | Ext | -40℃~+85℃ 1.8V 5Gbps Hub USB 3.0 XQFN-12(1.7x2) USB HUB Controllers RO | [ds](https://www.nxp.com/docs/en/data-sheet/PTN36241G.pdf) |

### USB-UART bridge: CH344 (quad) + CH343 (single, fallback)

| LCSC |  MPN | Maker | Pkg | USD@1 | Stock | Lib | Description | DS |
|---|---|---|---|---|---|-----|---|---|
| C2846043 | CH343P | WCH Jiangsu Qin Heng | TQFN-16-EP(3x3) | 1.11  |  4152 | Ext | -40℃~+85℃ 3.3V、5V 3mA 6Mbps 90uA USB 2.0 USB to UART TQFN-16-EP(3x3) U | [ds](https://jlcpcb.com/api/file/downloadByFileSystemAccessId/8618866816802574336) |
| C5832295 | CH343K | | ESSOP-10-150mil-1mm | 1.08  |  3918 | Ext | 1.8V~5V、3.3V、5V 15mA 50uA 6Mbps USB 2.0 USB to UART ESSOP-10-150mil-1m  | [ds]() |
| C2844153 | CH343G | WCH Jiangsu Qin Heng | SOP-16 | 1.22  |  3239 | Ext | -40℃~+85℃ 15mA 160uA 3.3V、5V 6Mbps USB 2.0 USB to UART SOP-16 USB Conv | [ds](https://jlcpcb.com/api/file/downloadByFileSystemAccessId/8618866813874679808) |
| C2887250 | CH344L | WCH Jiangsu Qin Heng | LQFP-48(7x7) | 2.82  |  1425 | Ext | -40℃~+85℃ 3.3V、5V 4 USB 2.0 USB to UART LQFP-48(7x7) USB Converters RO | [ds](https://jlcpcb.com/api/file/downloadByFileSystemAccessId/8618866860662546432) |
| C2988084 | CH344Q | WCH Jiangsu Qin Heng | LQFP-48(7x7) | 3.42  | 477 | Ext | -40℃~+85℃ 3.3V 4 6Mbps USB to UART、USB to RS232、USB to RS422、USB to RS | [ds](https://jlcpcb.com/api/file/downloadByFileSystemAccessId/8618866915339493376) |

### RS-485 transceivers (known candidates)

| LCSC | MPN | Maker |  Pkg | USD@1 | Stock  |  Lib  | Description | DS |
|---|---|---|---|---|---|---|---|---|
| C8963 | SP3485EN-L/TR | MaxLinear | SOIC-8 | 0.31  | 395153 | Basic | -40℃~+85℃ 1 1 10Mbps 2mA 3.3V 32 Half-Duplex Transceiver SOIC-8 RS-485  | [ds](https://jlcpcb.com/api/file/downloadByFileSystemAccessId/8579709476519542784) |
| C94206 | TP8485E-SR | 3PEAK | SOIC-8 | 0.14  | 117396 | Ext | -40℃~+125℃ 1 1 1.4mA 250Kbps 256 3V~5.5V Transceiver ±18kV SOIC-8 RS-4  | [ds](https://jlcpcb.com/api/file/downloadByFileSystemAccessId/8588879899309821952) |
| C668205 | SP3485EEN(UMW)  | | SOP-8  | 0.27  | 113295 | Ext | -40℃~+85℃ 1 1 12Mbps 2.97V~3.63V 256 520uA Half-Duplex Transceiver SOP  | [ds](https://jlcpcb.com/api/file/downloadByFileSystemAccessId/8757270730231173120) |
| C313015 | SIT3485ESA | SIT | SOP-8  | 0.35  | 102472 | Ext | -40℃~+85℃ 1 1 12Mbps 256 3V~3.6V 800uA Half-Duplex Transceiver SOP-8 R  | [ds](https://jlcpcb.com/api/file/downloadByFileSystemAccessId/8588881758171639808) |
| C3235232  | THVD1400DR | | SOIC-8 | 0.42  |  93954 | Ext | -40℃~+125℃ 1 1 1.5mA 256 3V~5.5V 500Kbps Enable shutdown、Tx/Rx enable  | [ds](https://www.ti.com/cn/lit/ds/symlink/thvd1400.pdf) |
| C41365340 | SP3485EN-L/TR | ElecSuper | SOP-8  | 0.21  |  58642 | Ext | | [ds](https://jlcpcb.com/api/file/downloadByFileSystemAccessId/8604439314516627456) |
| C668204 | MAX3485ESA(UMW) | | SOP-8  | 0.38  |  51823 | Ext | -40℃~+85℃ 1 1 12Mbps 2.97V~3.63V 256 Half-Duplex Transceiver SOP-8 RS-  | [ds](https://jlcpcb.com/api/file/downloadByFileSystemAccessId/8757271611299119104) |
| C3235215  | THVD1420DR | | SOIC-8 | 0.76  |  31181 | Ext | -40℃~+125℃ 1 1 1.5mA 12Mbps 256 3V~5.5V Half-Duplex Transceiver ±12kV | [ds](https://www.ti.com/cn/lit/gpn/thvd1420) |
| C9943 | MAX3485EESA+T | Analog Devices Inc Maxim Integrated | SOIC-8 | 1.99  |  27908 | Ext | -40℃~+85℃ 1 1 12Mbps 2.2mA 3V~3.6V Half-Duplex Transceiver ±15kV SOIC-  | [ds](https://jlcpcb.com/api/file/downloadByFileSystemAccessId/8586171749355933696) |
| C382671 | SIT3485EUA | SIT | MSOP-8 | 0.37  |  25763 | Ext | -40℃~+85℃ 1 1 12Mbps 256 3V~3.6V 800uA Half-Duplex Transceiver MSOP-8 | [ds](https://jlcpcb.com/api/file/downloadByFileSystemAccessId/8588883641350545408) |

### RS-485 transceivers (generic, high stock)

| LCSC | MPN | Maker |  Pkg | USD@1 | Stock  |  Lib  | Description | DS |
|---|---|---|---|---|---|---|---|---|
| C8963 | SP3485EN-L/TR  | MaxLinear | SOIC-8 | 0.31  | 395153 | Basic | -40℃~+85℃ 1 1 10Mbps 2mA 3.3V 32 Half-Duplex Transceiver SOIC-8 RS-485  | [ds](https://jlcpcb.com/api/file/downloadByFileSystemAccessId/8579709476519542784) |
| C6855 | SP485EEN-L/TR  | MaxLinear | SOIC-8 | 0.24  | 268465 | Basic | -40℃~+85℃ 1 1 10Mbps 4.75V~5.25V 900uA Half-Duplex Transceiver ±15kV S  | [ds](https://jlcpcb.com/api/file/downloadByFileSystemAccessId/8579709487195668480) |
| C7063 | SN75176BDR | Texas Instruments | SOIC-8 | 0.20  | 157024 | Basic | 0℃~+70℃ 1 1 4.75V~5.25V Transceiver SOIC-8 RS-485 / RS-422 ICs ROHS | [ds](https://www.ti.com/cn/lit/gpn/sn75176b) |
| C269864  | GM3085E | GATEMODE | SOP-8  | 0.12  | 295847 | Ext | -40℃~+85℃ 1 1 1Mbps 256 3V~5.5V 600uA Half-Duplex Transceiver ±15kV SO  | [ds](https://jlcpcb.com/api/file/downloadByFileSystemAccessId/8588881092011307009) |
| C269866  | YD3082EESA | GATEMODE | SOP-8  | 0.22  | 178995 | Ext | -40℃~+85℃ 1 1 1Mbps 256 3V~5.5V 600uA Half-Duplex Transceiver ±15kV SO  | [ds](https://jlcpcb.com/api/file/downloadByFileSystemAccessId/8586198293885542400) |
| C277895  | SSP485 | Shanghai Siproin Microelectronics | SOP-8  | 0.20  | 166337 | Ext | -40℃~+85℃ 1 1 256 2Mbps 450uA 5V Half-Duplex Transceiver ±15kV SOP-8 R  | [ds](https://jlcpcb.com/api/file/downloadByFileSystemAccessId/8588881756942032896) |
| C94206 | TP8485E-SR | 3PEAK | SOIC-8 | 0.14  | 117396 | Ext | -40℃~+125℃ 1 1 1.4mA 250Kbps 256 3V~5.5V Transceiver ±18kV SOIC-8 RS-4  | [ds](https://jlcpcb.com/api/file/downloadByFileSystemAccessId/8588879899309821952) |
| C2960453 | BL3085(I47) | BL Shanghai Belling | SOP-8  | 0.17  | 116471 | Ext | -40℃~+85℃ 1 1 256 3.3V、5V 500Kbps 600uA Half-Duplex Transceiver ±15kV  | [ds](https://jlcpcb.com/api/file/downloadByFileSystemAccessId/8589834892167962624) |
| C668205  | SP3485EEN(UMW) | | SOP-8  | 0.27  | 113295 | Ext | -40℃~+85℃ 1 1 12Mbps 2.97V~3.63V 256 520uA Half-Duplex Transceiver SOP  | [ds](https://jlcpcb.com/api/file/downloadByFileSystemAccessId/8757270730231173120) |
| C313015  | SIT3485ESA | SIT | SOP-8  | 0.35  | 102472 | Ext | -40℃~+85℃ 1 1 12Mbps 256 3V~3.6V 800uA Half-Duplex Transceiver SOP-8 R  | [ds](https://jlcpcb.com/api/file/downloadByFileSystemAccessId/8588881758171639808) |

### TTL half-duplex buffer: 74LVC2G241 (and 1G125/1G126 two-chip alt)

| LCSC | MPN | Maker | Pkg | USD@1 | Stock | Lib | Description | DS |
|---|---|---|---|---|---|-----|---|---|
| C7394032 | SN74LVC1G126DCKR(UMW) | UMW Youtai Semiconductor Co Ltd | SC-70-5  | 0.04  | 84425 | Ext | -40℃~+85℃ 1 1 1.65V~5.5V 10uA 24mA 24mA 4.8ns@5V,50pF 74LVC Tri-State  | [ds](https://jlcpcb.com/api/file/downloadByFileSystemAccessId/8590905756558708736) |
| C7834 | SN74LVC1G126DBVR | Texas Instruments | SOT-23-5 | 0.08  | 75466 | Ext | -40℃~+125℃ 1 1 1.65V~5.5V 10uA 3.7ns@3.3V,15pF 32mA 32mA 74LVC Tri-Sta | [ds](https://www.ti.com/cn/lit/gpn/sn74lvc1g126) |
| C23654 | SN74LVC1G125DBVR | Texas Instruments | SOT-23-5 | 0.21  | 51120 | Ext | -40℃~+125℃ 1 1 1.65V~5.5V 10uA 3.7ns@3.3V,15pF 32mA 32mA 74LVC Tri-Sta | [ds](https://www.ti.com/cn/lit/gpn/sn74lvc1g125) |
| C7833 | SN74LVC1G125DCKR | Texas Instruments | SC-70-5  | 0.10  | 46893 | Ext | -40℃~+125℃ 0.6ns@3.3V,15pF 1 1 1.65V~5.5V 10uA 32mA 32mA 74LVC Tri-Sta | [ds](https://www.ti.com/cn/lit/gpn/sn74lvc1g125) |
| C88039 | SN74LVC1G126DCKR | Texas Instruments | SC-70-5  | 0.06  | 39956 | Ext | -40℃~+125℃ 1 1 1.65V~5.5V 10uA 3.7ns@3.3V,15pF 32mA 32mA 74LVC Tri-Sta | [ds](https://www.ti.com/cn/lit/gpn/sn74lvc1g126) |
| C12519 | 74LVC1G125GW,125 | Nexperia | SOT-353  | 0.11  | 37943 | Ext | -40℃~+125℃ 1 1 1.65V~5.5V 2.1ns@3.3V,50pF 32mA 32mA 4uA 74LVC Schmitt  | [ds](https://jlcpcb.com/api/file/downloadByFileSystemAccessId/8586172448777908224) |
| C7394017 | SN74LVC1G125DBVR(UMW) | UMW Youtai Semiconductor Co Ltd | SOT-23-5 | 0.05  | 35189 | Ext | -40℃~+85℃ 1 1 1.65V~5.5V 10uA 24mA 24mA 74LVC Tri-State Unidirectional | [ds](https://jlcpcb.com/api/file/downloadByFileSystemAccessId/8590904162777444352) |
| C3040595 | 74LVC1G125GV-TP | TECH PUBLIC | SOT-23-5 | 0.09  | 25524 | Ext | -40℃~+125℃ 1.65V~5.5V 2.6ns@5.0V,50pF 24mA 24mA 2uA 74LVC Tri-State SO | [ds](https://jlcpcb.com/api/file/downloadByFileSystemAccessId/8589837347358470144) |

### Buck controllers for 12V/5V servo rails (external FETs, 10-20A)

| LCSC | MPN | Maker | Pkg | USD@1 | Stock | Lib | Description | DS |
|---|---|---|---|---|---|-----|---|---|
| C485912  | LM5145RGYR | Texas Instruments | VQFN-20-EP(3.5x4.5) | 2.45  |  4116 | Ext | -40℃~+125℃@(TJ) 1 1.8mA 1MHz 6V~75V 800mV~60V Adjustable Buck Buck Ext | [ds](https://www.ti.com/cn/lit/gpn/lm5145) |
| C56175 | TPS40170RGYR | Texas Instruments | TQFN-20-EP(3.5x4.5) | 1.80  |  2979 | Ext | -40℃~+125℃@(TJ) 1 4.5V~60V 600kHz 6A Adjustable Buck Buck External Yes | [ds](https://www.ti.com/cn/lit/gpn/tps40170) |
| C148172  | TPS53355DQPR | Texas Instruments | LSON-22-EP(5x6) | 6.13  |  1045 | Ext | -40℃~+125℃ 1 1.5V~15V 1MHz 30A 420uA 600mV~5.5V Adjustable Buck Buck B | [ds](https://jlcpcb.com/api/file/downloadByFileSystemAccessId/8588893308009517056) |
| C181238  | TPS40170QRGYRQ1 | Texas Instruments | VQFN-20-EP(3.7x4.7) | 2.20  | 479 | Ext | -40℃~+125℃@(TA) 1 100kHz~600kHz 4.5V~60V Adjustable Buck Buck External | [ds](https://www.ti.com/cn/lit/gpn/tps40170-q1) |
| C5219258 | LM5143QRHARQ1 | Texas Instruments | VQFN-40(6x6) | 3.95  | 376 | Ext | -40℃~+150℃ 15uA 2 2.2MHz 3.5V~65V 600mV~55V Buck Buck Built-in Yes VQF | [ds](https://www.ti.com/cn/lit/gpn/lm5143a-q1) |
| C2876740 | LM25145RGYR | Texas Instruments | VQFN-20-EP(3.5x4.5) | 3.65  | 350 | Ext | -40℃~+125℃@(TJ) 1 100kHz~1MHz 6V~42V 800mV~40V Adjustable Buck Buck Ex | [ds](https://www.ti.com/cn/lit/gpn/lm25145) |
| C1849541 | LM5143QRWGRQ1 | Texas Instruments | VQFN-40-EP(6x6) | 5.83  | 294 | Ext | -40℃~+150℃@(TJ) 15uA 2 2.2MHz 3.5V~65V 600mV~55V Adjustable Buck Buck  | [ds](https://www.ti.com/cn/lit/gpn/lm5143-q1) |
| C5219297 | LM5143RHAR | | VQFN-40-EP(6x6) | 4.83  | 252 | Ext | -40℃~+150℃@(TJ) 15uA 2 2.2MHz 3.5V~65V 600mV~55V Adjustable Buck Buck  | [ds](https://www.ti.com/cn/lit/gpn/lm5143) |

### Monolithic bucks, 60V-class in (5V USB rail candidates)

| LCSC | MPN | Maker | Pkg | USD@1 | Stock | Lib | Description | DS |
|---|---|---|---|---|---|-----|---|---|
| C31966 | TPS54560DDAR  | Texas Instruments | SOIC-8-EP | 1.02  | 47941 | Ext | -40℃~+150℃@(TJ) 1 146uA 2.5MHz 4.5V~60V 5A 800mV~58.8V Adjustable Buck | [ds](https://www.ti.com/cn/lit/gpn/tps54560) |
| C95286 | TPS54540DDAR  | Texas Instruments | SOIC-8-EP | 1.42  | 14850 | Ext | -40℃~+150℃@(TJ) 1 146uA 2.5MHz 4.5V~42V 5A 800mV~41.1V Adjustable Buck | [ds](https://www.ti.com/cn/lit/gpn/tps54540) |
| C1850354 | TPS54560BDDAR | Texas Instruments | SO-8 | 1.19  | 11483 | Ext | -40℃~+150℃@(TJ) 1 146uA 4.5V~60V 500kHz 5A 800mV~58.8V Adjustable Buck | [ds](https://www.ti.com/cn/lit/gpn/tps54560b) |
| C841384  | LMR33630ADDAR | Texas Instruments | ESOP-8 | 0.69  |  9908 | Ext | -40℃~+125℃@(TJ) 1 1V~24V 24uA 3.8V~36V 3A 400kHz Adjustable Buck Buck  | [ds](https://www.ti.com/cn/lit/gpn/lmr33630) |
| C477928  | LM5164DDAR | Texas Instruments | SO-8-EP | 1.36  |  6260 | Ext | -40℃~+150℃@(TJ) 1 10.5uA 1A 1MHz 6V~100V Adjustable Buck Buck Built-in | [ds](https://www.ti.com/cn/lit/gpn/lm5164) |
| C1850368 | TPS54540BDDAR | Texas Instruments | SO-8 | 2.23  |  5032 | Ext | -40℃~+150℃@(TJ) 1 146uA 4.5V~42V 500kHz 5A 800mV~41.1V Adjustable Buck | [ds](https://www.ti.com/cn/lit/gpn/tps54540b) |
| C544370  | LMR33630BDDAR | Texas Instruments | SOIC-8-EP | 0.74  |  4197 | Ext | -40℃~+125℃@(TJ) 1 1.4MHz 1V~24V 24uA 3.8V~36V 3A Adjustable Buck Buck  | [ds](https://www.ti.com/cn/lit/gpn/lmr33630) |
| C3194572 | AP63357QZV-7  | Diodes Incorporated | VDFN-13(2x3) | 1.09  |  3246 | Ext | -40℃~+125℃@(TA) 1 22uA 3.5A 3.8V~32V 450kHz 800mV~32V Adjustable Buck  | [ds](https://jlcpcb.com/api/file/downloadByFileSystemAccessId/8590903542410657792) |

### Small 3.3V buck (from 5V USB rail)

| LCSC | MPN | Maker | Pkg | USD@1 | Stock  | Lib | Description | DS |
|---|---|---|---|---|---|-----|---|---|
| C468250  | TPS563208DDCR | Texas Instruments | TSOT-23-6 | 0.16  | 140671 | Ext | -40℃~+125℃@(TJ) 1 3A 4.5V~17V 580kHz 768mV~7V Adjustable Buck Buck Bui | [ds](https://www.ti.com/cn/lit/gpn/tps563208) |
| C116592  | TPS563201DDCR | Texas Instruments | SOT-23-THIN-6 | 0.07  | 113251 | Ext | -40℃~+125℃@(TJ) 1 3A 4.5V~17V 580kHz 768mV~7V Adjustable Buck Buck Bui | [ds](https://jlcpcb.com/api/file/downloadByFileSystemAccessId/8588884106902323200) |
| C141836  | TLV62569DBVR  | Texas Instruments | SOT-23-5 | 0.07  | 108275 | Ext | -40℃~+125℃@(TJ) 1 1.5MHz 2.5V~5.5V 2A 600mV~5.5V Adjustable Buck Buck  | [ds](https://www.ti.com/cn/lit/gpn/tlv62569) |
| C2895288 | AP62200TWU-7  | Diodes Incorporated | TSOT-26 | 0.21  |  38030 | Ext | -40℃~+125℃ 1 135uA 2A 4.2V~18V 750kHz 800mV~7V Adjustable Buck Buck Bu | [ds](https://jlcpcb.com/api/file/downloadByFileSystemAccessId/8560089911954341888) |
| C2071106 | TPS56339DDCR  | Texas Instruments | TSOT-23-6 | 0.36  |  15757 | Ext | -40℃~+125℃@(TJ) 1 3A 4.5V~24V 500kHz 800mV~16V 98uA Adjustable Buck Bu | [ds](https://www.ti.com/cn/lit/gpn/tps56339) |
| C97253 | TPS563200DDCR | Texas Instruments | TSOT-23-6 | 1.41  |  14409 | Ext | -40℃~+85℃@(TA) 1 3A 4.5V~17V 650kHz 760mV~7V Adjustable Buck Buck Buil | [ds](https://www.ti.com/cn/lit/gpn/tps563200) |
| C1323282 | AP62200WU-7 | Diodes Incorporated | TSOT-26 | 0.17  |  14253 | Ext | -40℃~+125℃ 1 135uA 2A 4.2V~18V 750kHz 800mV~7V Adjustable Buck Buck Bu | [ds](https://jlcpcb.com/api/file/downloadByFileSystemAccessId/8560078892020097024) |
| C1513007 | TPS563202DRLR | Texas Instruments | SOT-563 | 0.15  |  13346 | Ext | -40℃~+125℃@(TJ) 1 3A 4.3V~17V 580kHz 806mV~7V Adjustable Buck Buck Bui | [ds](https://www.ti.com/cn/lit/gpn/tps563202) |

### eFuses / per-bus protection

| LCSC | MPN | Maker | Pkg | USD@1 | Stock | Lib | Description | DS |
|---|---|---|---|---|---|-----|---|---|
| C5571272  | TPS25961DRVR | Texas Instruments | WSON-6(2x2) | 0.39  | 27695 | Ext | -40℃~+125℃ 0.75mm 1 100mA~2A 106mΩ 2.7V~19V 2mm 2mm Integrated FET Sur  | [ds](https://jlcpcb.com/api/file/downloadByFileSystemAccessId/8590902654426439680) |
| C2155806  | TPS25940AQRVCRQ1  | Texas Instruments | QFN-20-EP(3x4)  | 1.81  |  6766 | Ext | -40℃~+125℃ 0.8mm 1 10mA 2.7V~18V 3mm 42mΩ 4mm 66mV Integrated FET Surf  | [ds](https://www.ti.com/cn/lit/gpn/tps25940-q1) |
| C7471768  | TPS16412DRCR | Texas Instruments | VSON-10(3x3) | 1.49  |  6178 | Ext | -40℃~+125℃ 1.8A 153mΩ 2.7V~40V Short-Circuit  Protection(SCP)、Over Vol | [ds](https://jlcpcb.com/api/file/downloadByFileSystemAccessId/8586208148742393856) |
| C2155776  | TPS259630DDAR | Texas Instruments | ESOP-8 | 0.70  |  4199 | Ext | -40℃~+125℃ 1 1.7mm 2.7V~19V 3.9mm 4.91mm 89mΩ Integrated FET Surface M  | [ds](https://www.ti.com/cn/lit/gpn/tps2596) |
| C2155778  | TPS259631DDAR | Texas Instruments | SOPowerPAD-8 | 0.79  |  3456 | Ext | -40℃~+125℃ 1 1.7mm 131mΩ 2.7V~19V 3.9mm 4.91mm Integrated FET Surface | [ds](https://www.ti.com/cn/lit/gpn/tps2596) |
| C1849461  | TPS16630PWPR | Texas Instruments | HTSSOP-20 | 2.50  |  2066 | Ext | -40℃~+125℃@(Tj) 1 1.2mm 30.44mΩ 4.4mm 4.5V~60V 6.5mm Integrated FET Su  | [ds](https://www.ti.com/cn/lit/gpn/tps1663) |
| C22357897 | TPS16-N1F1-2016-A | XFCN | SMD | 0.14  |  1321 | Ext | -25℃~+85℃ 1 10000 times 16P 5A 5V 6.5mm Laminated board Type-C SMD USB  | [ds](https://jlcpcb.com/api/file/downloadByFileSystemAccessId/8590921495675944960) |
| C52750323 | TPS16-N1F1-2016-A | | SMD | 0.09  |  1162 | Ext | -25℃~+85℃ 16P 3.16mm 5,000 cycles 5A 5V 6.5mm Black Female Type-C USB | [ds]() |
| C2653873  | TPS25940ARVCR | Texas Instruments | WQFN-20-EP(3x4) | 2.00  |  1086 | Ext | -40℃~+125℃ 1 2.7V~18V 42mΩ 5.2A Active High Overvoltage protection、Sof | [ds](https://www.ti.com/cn/lit/ds/symlink/tps25940.pdf) |
| C22433503 | TPS16416DRCR | | VSON-10-EP(3x3) | 1.66  |  1045 | Ext | -40℃~+125℃ 0.9mm 1 2.7V~40V 260mΩ 3mm 3mm Integrated FET Surface Mount  | [ds](https://www.ti.com.cn/cn/lit/ds/symlink/tps1641.pdf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) |

### USB VBUS power switches (per-port current limit)

| LCSC | MPN | Maker | Pkg | USD@1 | Stock  | Lib | Description | DS |
|---|---|---|---|---|---|-----|---|---|
| C55136 | SY6280AAC | Silergy Corp | SOT-23-5 | 0.10  | 233263 | Ext | -40℃~+125℃ 1 2.4V~5.5V 80mΩ Active High High Side Switch Overcurrent P | [ds](https://jlcpcb.com/api/file/downloadByFileSystemAccessId/8586176486478368768) |
| C42441843 | MT9700-N | | SOT-23-5 | 0.04  | 226501 | Ext | -40℃~+85℃ 1 2.4V~5.5V 2A 80mΩ Active High Current Limiting Switch SOT- | [ds](https://jlcpcb.com/api/file/downloadByFileSystemAccessId/8604442566352400384) |
| C55266 | TPS2553DBVR | Texas Instruments | SOT-23-6 | 0.30  |  44248 | Ext | -40℃~+150℃ 1 1.5A 2.5V~6.5V 85mΩ Active High High Side Switch 过压保护、软启动 | [ds](https://www.ti.com/cn/lit/gpn/tps2553) |
| C207620 | SY6280AAAC | Silergy Corp | SOT-23-5 | 0.10  |  32439 | Ext | -40℃~+125℃ 1 2.4V~5.5V 2A 63mΩ Active High High Side Switch Overcurren | [ds](https://jlcpcb.com/api/file/downloadByFileSystemAccessId/8588884728518336512) |
| C521201 | TPS2553DDBVR  | Texas Instruments | SOT-23-6 | 0.21  |  22579 | Ext | -40℃~+150℃ 1 1.5A 2.7V~6.5V 85mΩ Active High High Side Switch 软启动、欠压锁定 | [ds](https://www.ti.com/cn/lit/gpn/tps2553d) |
| C111738 | TPS2553DBVR-1 | Texas Instruments | SOT-23-6 | 0.29  |  14979 | Ext | -40℃~+150℃ 1 1.5A 2.5V~6.5V 85mΩ Active High High Side Switch 过压保护、软启动 | [ds](https://www.ti.com/cn/lit/gpn/tps2553-1) |
| C411878 | TPS2553DRVR-1 | Texas Instruments | WSON-6-EP(2x2)  | 0.38  | 4017 | Ext | -40℃~+105℃ 1 1.5A 115mΩ 2.5V~6.5V Active High Load Switch 软启动、欠压锁定、反向电 | [ds](https://www.ti.com/cn/lit/gpn/tps2553-1) |
| C140303 | TPS2561DRCR | Texas Instruments | VSON-10-EP(3x3) | 0.88  | 1213 | Ext | -40℃~+125℃ 2 2.5V~6.5V 2.8A 44mΩ Active High High Side Switch Overcurr | [ds](https://www.ti.com/cn/lit/gpn/tps2561) |
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

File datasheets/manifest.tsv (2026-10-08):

# file | lcsc | mpn | block | url
tusb8041.pdf | C544686 | TUSB8041IRGCR | usb-hub | https://www.ti.com/lit/gpn/tusb8041
rts5411s.pdf | C5356838 | RTS5411S-GR | usb-hub-alt | https://jlcpcb.com/api/file/downloadByFileSystemAccessId/8589838617779597312
cyusb3304.pdf | C462531 | CYUSB3304-68LTXC | usb-hub-alt | https://jlcpcb.com/api/file/downloadByFileSystemAccessId/8589838206326763520
ch344.pdf | C2988084 | CH344Q | servo-uart | https://jlcpcb.com/api/file/downloadByFileSystemAccessId/8618866915339493376
ch344.pdf | C2887250 | CH344L | servo-uart-alt | https://jlcpcb.com/api/file/downloadByFileSystemAccessId/8618866860662546432
sp3485en.pdf | C8963 | SP3485EN-L/TR | rs485-xcvr | https://jlcpcb.com/api/file/downloadByFileSystemAccessId/8579709476519542784
sn74lvc2g241.pdf | C10430 | SN74LVC2G241DCUR | ttl-buffer | https://www.ti.com/lit/ds/symlink/sn74lvc2g241.pdf
sn74lvc1g126.pdf | C7834 | SN74LVC1G126DBVR | ttl-buffer-alt | https://www.ti.com/lit/gpn/sn74lvc1g126
sn74lvc1g125.pdf | C23654 | SN74LVC1G125DBVR | ttl-buffer-alt | https://www.ti.com/lit/gpn/sn74lvc1g125
lm5145.pdf | C485912 | LM5145RGYR | buck-ctrl | https://www.ti.com/lit/gpn/lm5145
lm5143.pdf | C5219297 | LM5143RHAR | buck-ctrl-dual-alt | https://www.ti.com/lit/gpn/lm5143
tps54560.pdf | C31966 | TPS54560DDAR | buck-5v-usb | https://www.ti.com/lit/gpn/tps54560
tlv62569.pdf | C141836 | TLV62569DBVR | buck-3v3 | https://www.ti.com/lit/gpn/tlv62569
tps1663.pdf | C1849461 | TPS16630PWPR | efuse-12v | https://www.ti.com/lit/gpn/tps1663
tps25961.pdf | C5571272 | TPS25961DRVR | efuse-5v | https://jlcpcb.com/api/file/downloadByFileSystemAccessId/8590902654426439680
sy6280.pdf | C55136 | SY6280AAC | vbus-switch | https://jlcpcb.com/api/file/downloadByFileSystemAccessId/8586176486478368768
tps2553.pdf | C55266 | TPS2553DBVR | vbus-switch-alt | https://www.ti.com/lit/gpn/tps2553
hd3ss3220.pdf | C165155 | HD3SS3220RNHR | usbc-upstream | https://www.ti.com/lit/gpn/hd3ss3220
lm74700-q1.pdf | C2941042 | LM74700QDBVRQ1 | ideal-diode | https://www.ti.com/lit/gpn/lm74700-q1
smbj-series.pdf | C19077578 | SMBJ24A | tvs-19v | https://jlcpcb.com/api/file/downloadByFileSystemAccessId/8564879132338790400
smbj-series.pdf | C19077567 | SMBJ13A | tvs-12v | https://jlcpcb.com/api/file/downloadByFileSystemAccessId/8564879123408982016
smbj-series.pdf | C19077560 | SMBJ6.0A | tvs-5v | https://jlcpcb.com/api/file/downloadByFileSystemAccessId/8564879118736121856
tpd4e05u06.pdf | C138714 | TPD4E05U06DQAR | esd-usb3 | https://www.ti.com/lit/gpn/tpd4e05u06
usblc6-2sc6.pdf | C2687116 | USBLC6-2SC6 | esd-usb2-ttl | https://jlcpcb.com/api/file/downloadByFileSystemAccessId/8755886574108323840
sm712.pdf | C7420375 | SM712 | esd-rs485 | https://jlcpcb.com/api/file/downloadByFileSystemAccessId/8590905169016410112
jst-eh-series.pdf | C160258 | B4B-EH-A(LF)(SN) | conn-rs485 | https://jlcpcb.com/api/file/downloadByFileSystemAccessId/8588891962850627584
jst-eh-series.pdf | C160259 | B3B-EH-A(LF)(SN) | conn-ttl | https://jlcpcb.com/api/file/downloadByFileSystemAccessId/8564893974092939264
jst-eh-series.pdf | C265068 | S4B-EH(LF)(SN) | conn-rs485-alt | https://jlcpcb.com/api/file/downloadByFileSystemAccessId/8561889239836762112
jst-eh-series.pdf | C263754 | S3B-EH(LF)(SN) | conn-ttl-alt | https://jlcpcb.com/api/file/downloadByFileSystemAccessId/8588890020664631297
xt30pw-m.pdf | C431092 | XT30PW-M | conn-19v | https://jlcpcb.com/api/file/downloadByFileSystemAccessId/8588889116385136640
dc-005-a200.pdf | C720557 | DC-005-A200 | conn-19v-out-alt | https://jlcpcb.com/api/file/downloadByFileSystemAccessId/8588896245406842880
usba3-hc-st-003-01-j.pdf | C2845330 | HC-ST-003-01-J | conn-usba3 | https://jlcpcb.com/api/file/downloadByFileSystemAccessId/8588944600710569984
usbc-24p-qt.pdf | C2681555 | TYPE-C 24P QT | conn-usbc | https://jlcpcb.com/api/file/downloadByFileSystemAccessId/8756352863621144576
usbc-24p-qcht.pdf | C456013 | TYPE-C 24P QCHT | conn-usbc-alt | https://jlcpcb.com/api/file/downloadByFileSystemAccessId/8756352776610172928
csd18532q5b.pdf | C882766 | CSD18532Q5B | buck-fet | https://www.ti.com/cn/lit/gpn/csd18532q5b
tmpa1265sp-4r7.pdf | C2880057 | TMPA1265SP-4R7MN-D | buck-12v-inductor | https://wmsc.lcsc.com/wmsc/upload/file/pdf/v2/lcsc/2108241130_TAI-TECH-TMPA1265SP-4R7MN-D_C2880057.pdf
tmpc1265hp-3r3.pdf | C357272 | TMPC1265HP-3R3MG-D | buck-5v-inductor | https://wmsc.lcsc.com/wmsc/upload/file/pdf/v2/lcsc/2009171339_TAI-TECH-TMPC1265HP-3R3MG-D_C357272.pdf
we-7447798720.pdf | C105681 | 7447798720 | buck-5v-usb-inductor | https://www.we-online.com/components/products/datasheet/7447798720.pdf
smnr4020-2r2.pdf | C135262 | SMNR4020-2.2UH | buck-3v3-inductor | https://wmsc.lcsc.com/wmsc/upload/file/pdf/v2/lcsc/2108131530_SXN-Shun-Xiang-Nuo-Elec-SMNR4020-2-2UH_C135262.pdf
b560c.pdf | C85100 | B560C-13-F | catch-diode | https://wmsc.lcsc.com/wmsc/upload/file/pdf/v2/lcsc/2412251154_Diodes-Incorporated-B560C-13-F_C85100.pdf
tdk-c3225x7s2a475k.pdf | C342614 | C3225X7S2A475KT000N | cap-100v | https://wmsc.lcsc.com/wmsc/upload/file/pdf/v2/lcsc/2304140030_TDK-C3225X7S2A475KT000N_C342614.pdf
tdk-c3225x7r2a225k.pdf | C76686 | C3225X7R2A225KT5L0U | cap-100v | https://wmsc.lcsc.com/wmsc/upload/file/pdf/v2/lcsc/2304140030_TDK-C3225X7R2A225KT5L0U_C76686.pdf
murata-grm32er61c476k.pdf | C77101 | GRM32ER61C476KE15L | cap-out | https://wmsc.lcsc.com/wmsc/upload/file/pdf/v2/lcsc/2212021100_Murata-Electronics-GRM32ER61C476KE15L_C77101.pdf
samwha-cs3225x7r226k.pdf | C2918511 | CS3225X7R226K250NRL | cap-out | https://wmsc.lcsc.com/wmsc/upload/file/pdf/v2/lcsc/2111172030_Samwha-Capacitor-CS3225X7R226K250NRL_C2918511.pdf
rve470uf35v.pdf | C5155332 | RVE470UF35V167RV084 | bulk-19v | https://wmsc.lcsc.com/wmsc/upload/file/pdf/v2/lcsc/2209011730_KNSCHA-RVE470UF35V167RV084_C5155332.pdf
littelfuse-0453015.pdf | C178997 | 0453015.MR | fuse-19v | https://wmsc.lcsc.com/wmsc/upload/file/pdf/v2/lcsc/2304140030_Littelfuse-0453015-MR_C178997.pdf
prosemi-1206td-4a.pdf | C2838918 | 1206TD-4A | fuse-jetson | https://wmsc.lcsc.com/wmsc/upload/file/pdf/v2/lcsc/2204131745_prosemi-1206TD-4A_C2838918.pdf

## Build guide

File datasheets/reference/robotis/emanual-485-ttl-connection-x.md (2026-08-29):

## [Communication Circuit](#communication-circuit)
To control the DYNAMIXEL actuators, the main controller needs to convert its UART signals to the half duplex type. The recommended circuit diagram for this is shown below.

{% if page.product_group !='dxl_xw540' %}
### TTL Communication


> TTL Circuit

**NOTE**: Above circuit is designed for 5V or 5V tolerant MCU. Otherwise, use a Level Shifter to match the voltage of MCU.
{: .notice}


{% else %}{% endif %}

### RS-485 Communication
  
> RS-485 Circuit 

**NOTE**: Above circuit is designed for 5V or 5V tolerant MCU. Otherwise, use a Level Shifter to match the voltage of MCU.
{: .notice}

{% if page.product_group=='dxl_xw540' or page.product_group=='dxl_xw430' %}  

  
> XW540-Series Connector


> Dust and Water Proof Data Cable

{% else %}



{% endif %}

The power of DYNAMIXEL is supplied via Pin1(-), Pin2(+).  
(The above circuit is built into DYNAMIXEL's controller only)  
In the above circuit diagram, the direction of data signal of TxD and RxD in the TTL Level is determined according to the level of DIRECTION 485 as follows:  
In case of DIRECTION485 Level = High: The signal of TxD is output to D+ and D-  
In case of DIRECTION485 Level = Low: The signal of D+ and D- is output to RxD

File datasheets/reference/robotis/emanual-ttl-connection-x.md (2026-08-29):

<!-- TTL 통신, X만 사용. -->

## [Communication Circuit](#communication-circuit)
To control the DYNAMIXEL actuators, the main controller needs to convert its UART signals to the half duplex type. The recommended circuit diagram for this is shown below.

{% if page.product_group=='xl330' or page.ref == 'xc330-m288' or page.ref == 'xc330-m181'%}

### [TTL Communication (3.3V Logic, 5V Compatible)](#ttl-communication-33v-logic-5v-compatible)


**NOTE**: Though the communication bus of {{ page.product_group | upcase }} series is 3.3 V TTL logic level unlike other DYNAMIXELs, the {{ page.product_group | upcase }} series can be also compatible with 5V TTL logic level. 
{: .notice}

{% else %}

### [TTL Communication](#ttl-communication)
{% if page.product_group=='xm335' %}


{% else %}


{% endif %}

**NOTE**: Above circuit is designed for 5V or 5V tolerant MCU. Otherwise, use a Level Shifter to match the voltage of MCU.
{: .notice}

{% endif %}

{% if page.ref=='2xl430-w250' or page.ref=='2xc430-w250' %} 


{% elsif page.product_group=='xm335' %}
 

{% else %}


{% endif %}

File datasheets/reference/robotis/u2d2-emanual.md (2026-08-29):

---
layout: archive
lang: en
ref: u2d2
share: true
author_profile: false
permalink: /docs/en/parts/interface/u2d2/
sidebar:
  title: U2D2
  nav: "u2d2"
---

# [Introduction](#introduction)



> U2D2

U2D2 is a small size USB communication converter that enables to control and operate DYNAMIXEL with PC.

# [How to Use](#how-to-use)

**NOTE**: If U2D2 is unable to be detected by your computer, download the [Virtual COM Port Driver](https://ftdichip.com/drivers/vcp-drivers/) to detect the FTDI devices such as the U2D2.  
{: .notice}

## PC to DYNAMIXEL

U2D2 can be connected to the USB port of the PC with the enclosed USB cable.  
It supports both 3Pin TTL connector and 4Pin RS-485 connector to link up with various DYNAMIXEL's.  
U2D2 does not supply power to DYNAMIXEL, therefore, an external power supply should provide power to DYNAMIXEL.  
Be careful as recommended voltage for each DYNAMIXEL could be vary by model.  
Please refer to e-Manual for recommended supply voltage and power connection with various power supplies.



## PC to UART

U2D2 is able to connect ROBOTIS controllers that support 4Pin UART communication such as OpenCM9.04, CM-150 and CM-200 to the PC with the enclosed USB cable.



**NOTE** : In case of unstable communication with U2D2, check if there is a reference voltage difference in the communication.
Please check PC and other devices are grounded properly. Failing to do so might cause damages on the U2D2.
{: .notice}

# [Specifications](#specifications)



| Item | Description |
| :---: | :---: |
| Weight | 9g |
| Dimensions | 48mm x 18mm x 14.9mm |
| Ports | 3Pin TTL Level(TTL Communication supported DYNAMIXEL)<br />4Pin RS-485(RS-485 Communication supported DYNAMIXEL)<br />4Pin UART(Controllers that support 4Pin UART(such as CM-150 and CM-200) |
|  Baudrate  | Maximum 6Mbps |

{% include en/dxl/warning.md %}

# [Layout](#layout)



| Ports | Description |
| :---: | :---: |
| 4Pin UART | Convert USB and UART |
| 3Pin TTL Level | Connect to DYNAMIXEL with 3Pin TTL Level Communication |
|  4Pin RS-485 | Connect to DYNAMIXEL with 4Pin RS-485 Communication |
| Status LED | Display status of Power supply, TxD(Data write) and RxD(Data Read) |
|  *Type-C USB | Connect to the PC with USB cable |

**Note**: The USB port type of U2D2 products has been changed from Micro-B to Type-C from August 2025.
{: .notice}

# [Baudrate](#baudrate)

| Reference BPS |  Actual BPS | Error(%) |
| :---: | :---: | :---: |
| 9,600 | 9,600 | 0.00 |
| 57,600 |  57,588.4823  |  -0.02 |
| 115,200 | 115,246.0984  | 0.04 |
| 1,000,000 | 1,000,000 | 0.00 |
| 2,000,000 | 2,000,000 | 0.00 |
| 3,000,000 | 3,000,000 | 0.00 |
| 4,000,000 | 4,000,000 | 0.00 |
| 4,500,000 | 4,571,428.571 | 1.56 |
| 6,000,000 | 6,000,000 | 0.00 |

**NOTE** : Less than 3% of the baud rate error will not affect to the UART communication.
{: .notice}

**NOTE** : For the stable communication with higher baudrate, configure USB Latency value to the lower.  
[USB Latency Setting](/docs/en/software/dynamixel/dynamixel_wizard2/#usb-latency-setting)
{: .notice}

# [Supply Power](#supply-power)

U2D2 does not supply power to DYNAMIXEL, therefore, an external power supply should provide power to DYNAMIXEL as below.
Before connecting DYNAMIXEL to an external power supply, please check the recommended voltage for DYNAMIXEL.

{% capture u2d2_warning_01 %}
Caution for Power Supply

- For a stable power supply, it is recommended to use ROBOTIS controller or SMPS2Dynamixel.
- When connecting cable to DYNAMIXEL, please turn off the power.
  {% endcapture %}

<div class="notice--warning">{{ u2d2_warning_01 | markdownify }}</div>

## Using SMPS2Dynamixel

In order to operate DYNAMIXEL with SMPS2Dynamixel, please connect DYNAMIXEL to SMPS2Dynamixel, then connect SMPS to SMPS2Dynamixel as shown below image.  
Please compare operating voltage of DYNAMIXEL with 12V 5A ROBOTIS SMPS before supplying power.



## Using ROBOTIS Controller

In order to operate DYNAMIXEL with OpenCM 485 Expansion board, please connect DYNAMIXEL to OpenCM485 Exp board, then connect battery or SMPS to the expansion board as shown below image.  
Please compare operating voltage of DYNAMIXEL with battery or 12V 5A ROBOTIS SMPS before supplying power.  
OpenCM485 EXP board will bypass the input power source to output power.



## Using Power Supply

In order to operate DYNAMIXEL with Power Supply, please configure the power supply for DYNAMIXEL before connecting cable.  
Please check the pinout of the cable to avoid connecting to wrong pins.  
How to check whether the USB downloader(LN-101) driver is installed correctly.



# [Pinouts](#pinouts)



# [Data Flow Control](#data-flow-control)









When data is transmitted from the USB port in PC to peripheral devices(Tx), all connected device will receive an identical data.

On the other hand, when data is received from one of the peripheral devices(Rx), it will be automatically converted as USB communication and sent to the PC. During this process, received data will not be transmitted to other peripheral devices. If data from more than two peripheral devices are received, the received data can be corrupted.

Therefore, when connecting 3Pin TTL Level DYNAMIXEL and 4Pin RS-485 DYNAMIXEL at the same time, all connected DYNAMIXEL should have its unique ID in order to prevent receiving corrupt data. In addition, when using Bulk Read and Sync Read instructions that requires to receive data from multiple DYNAMIXEL's, relevant DYNAMIXEL's should be connected to the same communication channel or else the instruction will not work properly.

# [Software](#software)

1. **RoboPlus**  
   RoboPlus supports Windows environment to manage controllers and DYNAMIXEL's.

- [R+ Task 2.0] : R+ Task 2.0 can be used when downloading Task Code to the controller.
- [R+ Motion 2.0] : R+ Motion 2.0 can be used when downloading Motion file to the controller.
- [R+ Manager 2.0] : R+ Manager 2.0 is used to connect controllers or DYNAMIXEL's and update firmware or test the control table..
- [R+ Task 3.0] : Integrated software with R+ Task 2.0 and R+ Motion 2.0

[r+ task 2.0]: /docs/en/software/rplus2/task/
[r+ motion 2.0]: /docs/en/software/rplus2/motion/
[r+ manager 2.0]: /docs/en/software/rplus2/manager/
[r+ task 3.0]: /docs/en/software/rplustask3/

2. **DYNAMIXEL Workbench**  
   DYNAMIXEL Workbench supports Linux environment to test control table of DYNAMIXEL.

- [ROBOTIS GitHub](https://github.com/ROBOTIS-GIT)
- [DYNAMIXEL Workbench Manual](http://emanual.robotis.com/docs/en/software/dynamixel/dynamixel_workbench/dynamixel_workbench/)

3. **DYNAMIXEL SDK**  
   DYNAMIXEL SDK supports various programming languages such as C, C++, C#, MATLAB, LabVIEW, Python and Java in order to help developing DYNAMIXEL control software. DYNAMIXEL SDK provides a bundle of functions/methods that can be used for operating DYNAMIXEL with protocols in the form of digital packet. DYNAMIXEL SDK is free to download from GitHub.

- [ROBOTIS GitHub](https://github.com/ROBOTIS-GIT)
- [DYNAMIXEL SDK Manual](http://emanual.robotis.com/docs/en/software/dynamixel/dynamixel_sdk/overview/)

# [Additional Features](#additional-features)

## [Internal DIP Switch](#internal-dip-switch)

There is a two-pole switch inside of the plastic cover. This switch is set to OFF as a default. Under normal circumstances this default setting is recommended, therefore, the switch cannot be accessed without opening the case. Please open the case and set RS-485 termination resistor and UART 3.3V power switch only after thoroughly understand its usage.



### RS-485 Termination Resistor(120&Omega;) Switch

Transmission devices are designed to have certain impedances based on design standard and signal reflection or interference can occur when impedance do not match over the transmission lines. The termination resistors at the end of transmission lines suppress such effect by adjusting impedance and allowing constant current flow. However, the termination resistor is not a mandatory, especially in a short RS-485 network with lower communication baud rate.

If communication is suffering from frequent errors, the termination resistor might be required. The regular 120&Omega; termination resistor will be applied on the transmission line by shifting the switch to ON. If termination resistor doesn’t resolve the communication issue, the resistance value might need to be adjusted.



### UART 3.3V Power Supply Switch

The peripheral device such as controllers that can be connected to the 4Pin UART usually have an external power source, therefore additional 3.3V power from the UART port #2 pin is not necessary.  
However, when connecting BT-410 that does not have an external power source needs to be powered by the 4Pin UART port #2 pin. In this case, the UART 3.3V power switch need to be turned on.  
If the switch is turned on, second pin of the 4Pin UART connector will be able to supply 3.3V.

## [Caution for Assembly](#caution-for-assembly)



- Bolt for Mount Hole : M2 Tap bolt
- Mount Hole Depth : Valid depth 4.7mm, Depth from the surface 5.5mm

# [References](#references)

## [Connector Information](#connector-information)

{% include en/dxl/jst_485_ttl.md %}

## [USB Latency Setting](#usb-latency-setting)

For the most reliable high-speed communication with DYNAMIXEL it is recommended to reduce USB port latency as described below. 

### Windows

1. Open `Device Manager`. Go to `Ports` item and right click on the relative serial port to select `Properties`.

    

2. In the Properties window, go to `Port Settings` tab and click `Advanced` button.

    

3. Set the `Latency Timer (msec)` to `1ms` and click `OK` to confirm the change.

    

### Linux

1. Execute below commands to configure the `latency_timer` to `1ms`.

    ```c
    # cat /sys/bus/usb-serial/devices/ttyUSB0/latency_timer
    16
    # echo 1 > /sys/bus/usb-serial/devices/ttyUSB0/latency_timer
    # cat /sys/bus/usb-serial/devices/ttyUSB0/latency_timer
    1
    ```

## [Certifications](#certifications)

Please inquire us for information regarding unlisted certifications.

### [FCC](#fcc)

{% include en/dxl/fcc_class_a.md %}

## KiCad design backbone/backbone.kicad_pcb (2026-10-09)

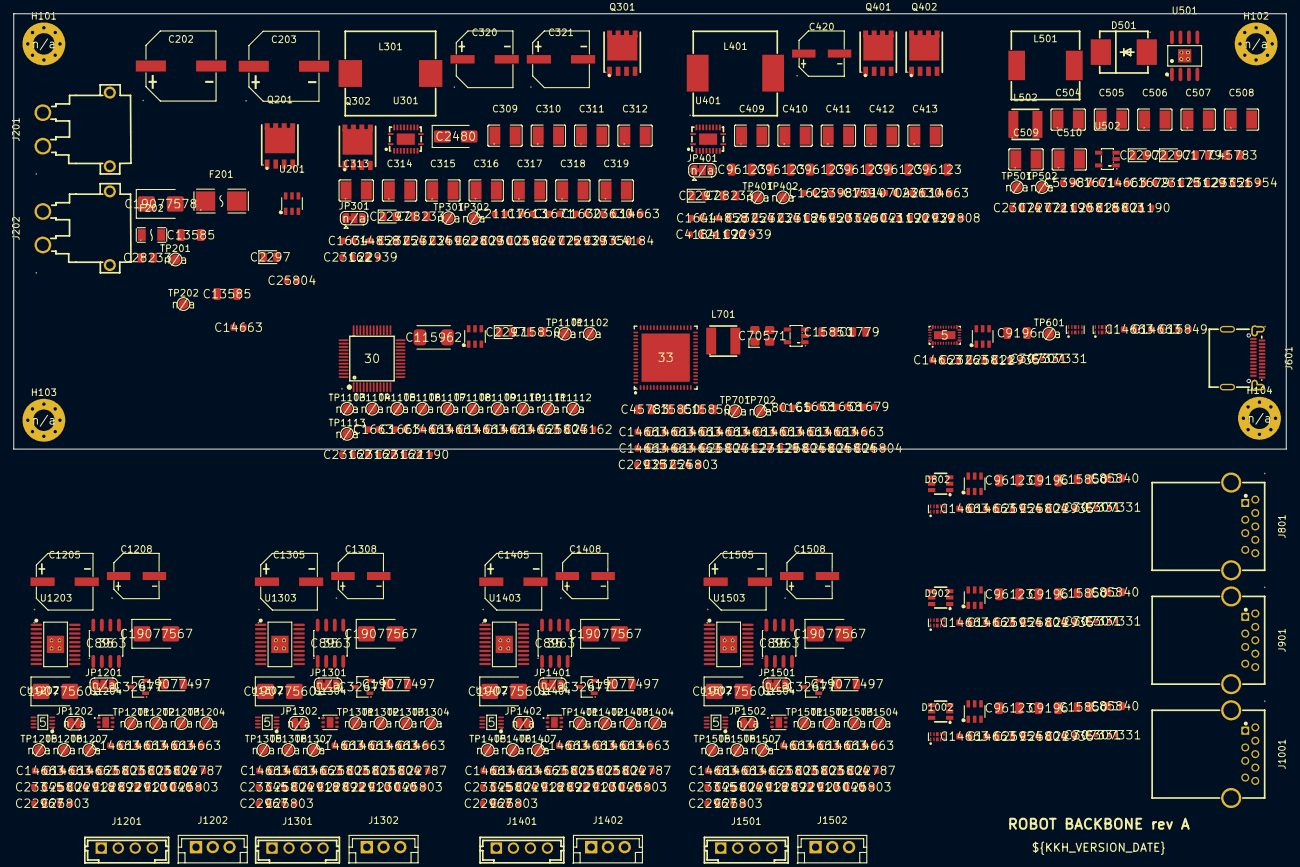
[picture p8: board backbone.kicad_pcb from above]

Board: 4 copper layers, 190.0 x 65.0 mm, 430 parts (0 on the bottom side), 225 nets, no tracks yet.

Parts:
C201, C306, C406, C503, C603, C604, C606, C707, C708, C709, C710, C711, C712, C713, C714, C716, C717, C718, C719, C801, C804, C901, C904, C1001, C1004, C1103, C1104, C1105, C1106, C1107, C1201, C1202, C1203, C1204, C1206, C1207, C1209, C1301, C1302, C1303, C1304, C1306, C1307, C1309, C1401, C1402, C1403, C1404, C1406, C1407, C1409, C1501, C1502, C1503, C1504, C1506, C1507, C1509: 100nF; C_0603
C202, C203: 470uF 35V; CAP-SMD_BD10.0-L10.3-W10.3-LS11.3-FD
C204, C206: 10uF 50V; C_1206
C205, C307, C407: 100nF 100V; C_0805
C301: 33nF; C_0603
C302: 3.3nF; C_0603
C303, C502: 47pF; C_0603
C304: 680pF; C_0603
C305, C405: 2.2uF; C_0603
C308: 10pF; C_0603
C309, C310, C311, C312, C313: 4.7uF 100V; C1210
C314, C315, C316, C317, C508, C509, C510: 47uF 16V; C1210
C318, C319: 22uF 25V; C1210
C320, C321, C1205, C1305, C1405, C1505: 470uF 25V; CAP-SMD_BD8.0-L8.3-W8.3-LS9.0-FD_H10.5
C322, C421: 100pF; C_0603
C401: 47nF; C_0603
C402, C501: 4.7nF; C_0603
C403: 150pF; C_0603
C404: 1.8nF; C_0603
C408: 15pF; C_0603
C409, C410, C411, C412, C413, C504, C505, C506, C507: 2.2uF 100V; C1210
C414, C415, C416, C417, C418, C419, C803, C903, C1003: 47uF 10V; C_1206
C420, C1208, C1308, C1408, C1508: 470uF 10V; CAP-SMD_BD6.3-L6.6-W6.6-LS7.3-FD-H7.7
C511, C704: 6.8pF; C_0603
C512, C705: 4.7uF; C_0805
C513, C706: 22uF; C_0805
C601, C602, C805, C806, C905, C906, C1005, C1006: 100nF; C_0402
C605: 1uF; C_0603
C607, C807, C907, C1007: 1nF 2kV; C_1206
C701, C715, C720, C802, C902, C1002, C1108: 10uF; C_0805
C702, C703: 30pF; C_0603
C1101, C1102: 33pF; C_0603
D201: SMBJ24A; D_SMB
D202, D302, D401, D502, D503: LED Green; D_0805
D301: SS14; D_SMA
D501: B560C; SMC_L7.1-W6.2-LS8.1-RD
D601, D602, D802, D902, D1002: TPD4E05U06; USON-10_L2.5-W1.0-P0.50-BL
D603, D801, D901, D1001, D1102: USBLC6-2SC6; SOT-23-6_L2.9-W1.6-P0.95-LS2.8-BL
D1101: LED ACT; D_0805
D1201, D1301, D1401, D1501: PSM712-LF-T7; SOT-23-3_L3.0-W1.7-P0.95-LS2.9-BR
D1202, D1302, D1402, D1502: SMF5.0A; D_SOD-123FL
D1203, D1303, D1403, D1503: SMBJ13A; D_SMB
D1204, D1304, D1404, D1504: SMBJ6.0A; D_SMB
F201: 15A T 2410; FUSE-SMD_L6.1-W2.7
F202: 4A T 1206; F1206
FB701: BLM18PG221SN1D; FB_0603
FB801, FB901, FB1001: BLM21PG221SN1D; FB_0805
H101, H102, H103, H104: M3; MountingHole_3.2mm_M3_Pad_Via
J201, J202: XT30PW-M; CONN-TH_XT30PW-M
J601: USB-C 24P receptacle; USB-C-SMD_TYPE-C-24P-QT
J801, J901, J1001: USB-A 3.0 receptacle; USB-3.0-A-TH_HC-ST-003-01-Z
J1201, J1301, J1401, J1501: RS-485 JST EH 4p; CONN-TH_B4B-EH-A-LF-SN
J1202, J1302, J1402, J1502: TTL JST EH 3p; CONN-TH_B3B-EH-A-LF-SN
JP301, JP401: SYNCIN: 1-2 GND=DEM, 2-3 VCC=FPWM; SolderJumper-3_P1.3mm_Bridged12_RoundedPad1.0x1.5mm
JP1201, JP1301, JP1401, JP1501: MODE: 1-2 RS-485 (default), 2-3 TTL; SolderJumper-3_P1.3mm_Bridged12_RoundedPad1.0x1.5mm
JP1202, JP1302, JP1402, JP1502: MODE: bridged = auto-retry, open = latch-off; SolderJumper-2_P1.3mm_Bridged_RoundedPad1.0x1.5mm
L301: 4.7uH 20A; IND-SMD_L13.5-W12.6
L401: 3.3uH 18A; IND-SMD_L13.5-W12.6_125CDMCC-DS
L501: 7.2uH 6A; IND-SMD_L10.2-W10.2_7447798720
L502, L701: 2.2uH 3.4A; IND-SMD_L4.0-W4.0_LQH44PN2R2MP0L
Q201, Q301, Q302, Q401, Q402: CSD18532Q5B; SON-8_L5.0-W6.0-P1.27-BL-1
R201, R701, R704, R705, R706, R707, R802, R902, R1002, R1101, R1203, R1206, R1303, R1306, R1403, R1406, R1503, R1506: 10k; R_0603
R301, R401, R709: 82k; R_0603
R302, R402: 7.5k; R_0603
R303: 24.9k; R_0603
R304: 15k; R_0603
R305: 33.2k; R_0603
R306: 2.37k; R_0603
R307: 100; R_0603
R308, R312, R408, R412: 2.2; R_0603
R309: 240; R_0603
R310, R410: 20k; R_0603
R311, R1102, R1103, R1104, R1105: 4.7k; R_0603
R403: 49.9k; R_0603
R404: 11k; R_0603
R405: 23.2k; R_0603
R406: 4.42k; R_0603
R407, R411, R507, R510, R1106: 1k; R_0603
R409: 150; R_0603
R501: 442k; R_0603
R502, R703: 90.9k; R_0603
R503: 243k; R_0603
R504, R801, R901, R1001: 16.9k; R_0603
R505: 53.6k; R_0603
R506: 10.2k; R_0603
R508: 453k; R_0603
R509, R710, R1201, R1202, R1211, R1213, R1301, R1302, R1311, R1313, R1401, R1402, R1411, R1413, R1501, R1502, R1511, R1513: 100k; R_0603
R601: 910k; R_0603
R602: 200k; R_0603
R603, R708, R803, R903, R1003: 1M; R_0603
R702: 9.53k; R_0603
R1204, R1304, R1404, R1504: 120; R_0603
R1205, R1305, R1405, R1505: 22; R_0603
R1207, R1307, R1407, R1507: 249k; R_0603
R1208, R1308, R1408, R1508: 18.2k; R_0603
R1209, R1309, R1409, R1509: 20.5k; R_0603
R1210, R1310, R1410, R1510: 4.02k; R_0603
R1212, R1312, R1412, R1512: 27k; R_0603
TP201: +19V_IN; TestPoint_Pad_D1.5mm
TP202: +19V_JETSON; TestPoint_Pad_D1.5mm
TP301, TP401: PGOOD; TestPoint_Pad_D1.5mm
TP302: +12V_SERVO; TestPoint_Pad_D1.5mm
TP402: +5V_SERVO; TestPoint_Pad_D1.5mm
TP501: +5V_USB; TestPoint_Pad_D1.5mm
TP502: +3V3; TestPoint_Pad_D1.5mm
TP601: DIR; TestPoint_Pad_D1.5mm
TP701: GRSTz; TestPoint_Pad_D1.5mm
TP702: VDD_HUB; TestPoint_Pad_D1.5mm
TP1101: RESET; TestPoint_Pad_D1.5mm
TP1102: UART0_TXD; TestPoint_Pad_D1.5mm
TP1103: UART0_RXD; TestPoint_Pad_D1.5mm
TP1104: UART0_TNOW; TestPoint_Pad_D1.5mm
TP1105: UART1_TXD; TestPoint_Pad_D1.5mm
TP1106: UART1_RXD; TestPoint_Pad_D1.5mm
TP1107: UART1_TNOW; TestPoint_Pad_D1.5mm
TP1108: UART2_TXD; TestPoint_Pad_D1.5mm
TP1109: UART2_RXD; TestPoint_Pad_D1.5mm
TP1110: UART2_TNOW; TestPoint_Pad_D1.5mm
TP1111: UART3_TXD; TestPoint_Pad_D1.5mm
TP1112: UART3_RXD; TestPoint_Pad_D1.5mm
TP1113: UART3_TNOW; TestPoint_Pad_D1.5mm
TP1201, TP1301, TP1401, TP1501: SHDN_485; TestPoint_Pad_D1.5mm
TP1202, TP1302, TP1402, TP1502: TXD; TestPoint_Pad_D1.5mm
TP1203, TP1303, TP1403, TP1503: RXD; TestPoint_Pad_D1.5mm
TP1204, TP1304, TP1404, TP1504: TNOW; TestPoint_Pad_D1.5mm
TP1205, TP1305, TP1405, TP1505: A; TestPoint_Pad_D1.5mm
TP1206, TP1306, TP1406, TP1506: B; TestPoint_Pad_D1.5mm
TP1207, TP1307, TP1407, TP1507: DATA; TestPoint_Pad_D1.5mm
U201: LM74700QDBVRQ1; SOT-23-6_L2.9-W1.6-P0.95-LS2.8-BL
U301, U401: LM5145RGYR; VQFN-20_L4.5-W3.5-P0.50-BL-EP
U501: TPS54560DDAR; SOIC-8_L5.0-W4.0-P1.27-LS6.0-BL-EP2.0
U502, U702: TLV62569DBVR; SOT-23-5_L3.0-W1.7-P0.95-LS2.8-BR
U601: HD3SS3220RNHR; WQFN-30_L4.5-W2.5-P0.4-BL-EP
U701: TUSB8041IRGCR; QFN-64_L9.0-W9.0-P0.50-BL-EP7.2
U801, U901, U1001: TPS2553DBVR; SOT-23-6_L2.9-W1.6-P0.95-LS2.8-BR
U1101: CH344Q; LQFP-48_L7.0-W7.0-P0.50-LS9.0-BL
U1201, U1301, U1401, U1501: SP3485EN-L/TR; SOIC-8_L5.0-W4.0-P1.27-LS6.0-BL
U1202, U1302, U1402, U1502: SN74LVC2G241DCU; VSSOP-8_L2.3-W2.0-P0.50-LS3.1-BR
U1203, U1303, U1403, U1503: TPS16630PWPR; HTSSOP-20_L6.5-W4.4-P0.65-LS6.4-TL-EP2.58
U1204, U1304, U1404, U1504: TPS25961DRVR; WSON-6_L2.0-W2.0-P0.65-TL-EP
Y701: 24MHz 18pF; OSC-SMD_4P-L3.2-W2.5-BL
Y1101: 8MHz 20pF; CRYSTAL-SMD_L5.0-W3.2

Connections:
+1V1_HUB: C704.1, C706.1, FB701.1, L701.2, R709.1
+3V3: C511.1, C513.1, C603.1, C604.1, C716.1, C717.1, C718.1, C719.1, C720.1, C1104.1, C1105.1, C1106.1, C1107.1, C1108.1, C1201.1, C1202.1, C1301.1, C1302.1, C1401.1, C1402.1, C1501.1, C1502.1, D1102.5, L502.2, R508.1, R510.1, R602.1, R701.1, R705.1, R706.1, R707.1, R802.1, R902.1, R1002.1, R1101.1, R1106.1, R1201.1, R1202.1, R1203.1, R1206.1, R1301.1, R1302.1, R1303.1, R1306.1, R1401.1, R1402.1, R1403.1, R1406.1, R1501.1, R1502.1, R1503.1, R1506.1, TP502.1, U601.8, U701.16, U701.34, U701.52, U701.63, U1101.9, U1101.24, U1101.36, U1101.48, U1201.8, U1202.8, U1301.8, U1302.8, U1401.8, U1402.8, U1501.8, U1502.8
+5V_SERVO: C414.1, C415.1, C416.1, C417.1, C418.1, C419.1, C420.1, C1207.1, C1307.1, C1407.1, C1507.1, L401.2, R405.1, R407.1, R411.1, R1213.1, R1313.1, R1413.1, R1513.1, TP402.1, U1204.6, U1304.6, U1404.6, U1504.6
+5V_USB: C508.1, C509.1, C510.1, C512.1, C605.1, C606.1, C705.1, C801.1, C802.1, C901.1, C902.1, C1001.1, C1002.1, L501.2, R505.1, R507.1, TP501.1, U502.1, U502.4, U601.30, U702.1, U702.4, U801.1, U901.1, U1001.1
+12V_SERVO: C314.1, C315.1, C316.1, C317.1, C318.1, C319.1, C320.1, C321.1, C1204.1, C1304.1, C1404.1, C1504.1, D301.2, L301.2, R305.1, R307.1, R311.1, R1207.1, R1211.1, R1307.1, R1311.1, R1407.1, R1411.1, R1507.1, R1511.1, TP302.1, U1203.1, U1203.2, U1203.3, U1203.6, U1303.1, U1303.2, U1303.3, U1303.6, U1403.1, U1403.2, U1403.3, U1403.6, U1503.1, U1503.2, U1503.3, U1503.6
+19V_IN: C202.1, C203.1, C204.1, C205.1, C307.1, C309.1, C310.1, C311.1, C312.1, C313.1, C407.1, C409.1, C410.1, C411.1, C412.1, C413.1, C504.1, C505.1, C506.1, C507.1, F202.1, Q201.5, Q201.6, Q201.7, Q201.8, Q201.9, Q301.5, Q301.6, Q301.7, Q301.8, Q301.9, Q401.5, Q401.6, Q401.7, Q401.8, Q401.9, R201.1, R301.1, R401.1, R501.1, TP201.1, U201.4, U301.20, U401.20, U501.2
+19V_JETSON: C206.1, F202.2, J202.2, TP202.1
/DS1_DM: D801.4, U701.2
/DS1_DP: D801.6, U701.1
/DS1_OVERCUR_N: R705.2, R802.2, U701.46, U801.4
/DS1_PWRCTL: U701.36, U801.3
/DS1_SSRX_N: D802.5, J801.5, U701.7
/DS1_SSRX_P: D802.4, J801.6, U701.6
/DS1_SSTX_N: C806.1, U701.4
/DS1_SSTX_P: C805.1, U701.3
/DS2_DM: D901.4, U701.10
/DS2_DP: D901.6, U701.9
/DS2_OVERCUR_N: R706.2, R902.2, U701.47, U901.4
/DS2_PWRCTL: U701.35, U901.3
/DS2_SSRX_N: D902.5, J901.5, U701.15
/DS2_SSRX_P: D902.4, J901.6, U701.14
/DS2_SSTX_N: C906.1, U701.12
/DS2_SSTX_P: C905.1, U701.11
/DS3_DM: D1001.4, U701.18
/DS3_DP: D1001.6, U701.17
/DS3_OVERCUR_N: R707.2, R1002.2, U701.44, U1001.4
/DS3_PWRCTL: U701.33, U1001.3
/DS3_SSRX_N: D1002.5, J1001.5, U701.23
/DS3_SSRX_P: D1002.4, J1001.6, U701.22
/DS3_SSTX_N: C1006.1, U701.20
/DS3_SSTX_P: C1005.1, U701.19
/DS4_DM: D1102.4, U701.25
/DS4_DP: D1102.6, U701.24
/UART0_RXD: R1203.2, TP1103.1, TP1203.1, U1101.31, U1201.1, U1202.6
/UART0_TNOW: JP1201.2, R1102.1, TP1104.1, TP1204.1, U1101.39, U1201.3, U1202.7
/UART0_TXD: TP1102.1, TP1202.1, U1101.30, U1201.4, U1202.5
/UART1_RXD: R1303.2, TP1106.1, TP1303.1, U1101.13, U1301.1, U1302.6
/UART1_TNOW: JP1301.2, R1103.1, TP1107.1, TP1304.1, U1101.18, U1301.3, U1302.7
/UART1_TXD: TP1105.1, TP1302.1, U1101.12, U1301.4, U1302.5
/UART2_RXD: R1403.2, TP1109.1, TP1403.1, U1101.22, U1401.1, U1402.6
/UART2_TNOW: JP1401.2, R1104.1, TP1110.1, TP1404.1, U1101.19, U1401.3, U1402.7
/UART2_TXD: TP1108.1, TP1402.1, U1101.21, U1401.4, U1402.5
/UART3_RXD: R1503.2, TP1112.1, TP1503.1, U1101.38, U1501.1, U1502.6
/UART3_TNOW: JP1501.2, R1105.1, TP1113.1, TP1504.1, U1101.34, U1501.3, U1502.7
/UART3_TXD: TP1111.1, TP1502.1, U1101.37, U1501.4, U1502.5
/US_DM: D603.4, U701.54
/US_DP: D603.6, U701.53
/US_SSRX_N: U601.10, U701.59
/US_SSRX_P: U601.9, U701.58
/US_SSTX_N: C602.1, U701.56
/US_SSTX_P: C601.1, U701.55
/buck-5v-servo/BOOT: R408.1, U401.17
/buck-5v-servo/COMP: C403.1, R404.1, U401.4
/buck-5v-servo/FB: C402.2, C403.2, C404.2, R405.2, R406.1, U401.5
/buck-5v-servo/HO: Q401.4, U401.18
/buck-5v-servo/ILIM: C408.1, R409.1, U401.11
/buck-5v-servo/LO: Q402.4, U401.13
/buck-5v-servo/PGOOD: R410.2, TP401.1, U401.10
/buck-5v-servo/RT: R403.1, U401.2
/buck-5v-servo/SS: C401.1, U401.3
/buck-5v-servo/SW: C406.2, L401.1, Q401.1, Q401.2, Q401.3, Q402.5, Q402.6, Q402.7, Q402.8, Q402.9, R409.2, R412.1, U401.19
/buck-5v-servo/SYNCIN: JP401.2, U401.8
/buck-5v-servo/UVLO: R401.2, R402.1, U401.1
/buck-5v-servo/VCC: C405.1, JP401.3, R410.1, U401.14
/buck-5v-usb/BOOT: C503.1, U501.1
/buck-5v-usb/COMP: C502.1, R504.1, U501.6
/buck-5v-usb/EN: R501.2, R502.1, U501.3
/buck-5v-usb/FB: R505.2, R506.1, U501.5
/buck-5v-usb/FB_3V3: C511.2, R508.2, R509.1, U502.5
/buck-5v-usb/RT: R503.1, U501.4
/buck-5v-usb/SW: C503.2, D501.1, L501.1, U501.8
/buck-5v-usb/SW_3V3: L502.1, U502.3
/buck-12v-servo/BOOT: R308.1, U301.17
/buck-12v-servo/COMP: C303.1, R304.1, U301.4
/buck-12v-servo/FB: C302.2, C303.2, C304.2, R305.2, R306.1, U301.5
/buck-12v-servo/HO: Q301.4, U301.18
/buck-12v-servo/ILIM: C308.1, R309.1, U301.11
/buck-12v-servo/LO: Q302.4, U301.13
/buck-12v-servo/PGOOD: R310.2, TP301.1, U301.10
/buck-12v-servo/RT: R303.1, U301.2
/buck-12v-servo/SS: C301.1, U301.3
/buck-12v-servo/SW: C306.2, L301.1, Q301.1, Q301.2, Q301.3, Q302.5, Q302.6, Q302.7, Q302.8, Q302.9, R309.2, R312.1, U301.19
/buck-12v-servo/SYNCIN: JP301.2, U301.8
/buck-12v-servo/UVLO: R301.2, R302.1, U301.1
/buck-12v-servo/VCC: C305.1, D301.1, JP301.3, R310.1, U301.14
/input/GATE: Q201.4, U201.5
/input/VCAP: C201.1, U201.1
/input/VIN_F: C201.2, D201.1, F201.2, Q201.1, Q201.2, Q201.3, U201.3, U201.6
/input/VIN_RAW: F201.1, J201.2
/servo-port-0/A: D1201.1, J1201.3, R1204.1, TP1205.1, U1201.6
/servo-port-0/B: D1201.2, J1201.4, R1204.2, TP1206.1, U1201.7
/servo-port-0/DATA: D1202.1, J1202.3, R1205.2, R1206.2, TP1207.1
/servo-port-0/DATA_BUF: R1205.1, U1202.2, U1202.3
/servo-port-0/DVDT_485: C1203.1, U1203.10
/servo-port-0/EN_TTL: R1213.2, U1204.5
/servo-port-0/ILIM_485: R1210.1, U1203.11
/servo-port-0/ILIM_TTL: R1212.1, U1204.3
/servo-port-0/MODE_485: JP1202.1, U1203.12
/servo-port-0/OE_TTL: JP1201.3, R1202.2, U1202.1
/servo-port-0/OVP_485: R1207.2, R1208.1, U1203.8
/servo-port-0/RE_485: JP1201.1, R1201.2, U1201.2
/servo-port-0/SHDN_485: R1211.2, TP1201.1, U1203.13
/servo-port-0/UVLO_485: R1208.2, R1209.1, U1203.7
/servo-port-0/VDD_485: C1205.1, C1206.1, D1203.1, J1201.2, U1203.18, U1203.19, U1203.20
/servo-port-0/VDD_TTL: C1208.1, C1209.1, D1204.1, J1202.2, U1204.1
/servo-port-1/A: D1301.1, J1301.3, R1304.1, TP1305.1, U1301.6
/servo-port-1/B: D1301.2, J1301.4, R1304.2, TP1306.1, U1301.7
/servo-port-1/DATA: D1302.1, J1302.3, R1305.2, R1306.2, TP1307.1
/servo-port-1/DATA_BUF: R1305.1, U1302.2, U1302.3
/servo-port-1/DVDT_485: C1303.1, U1303.10
/servo-port-1/EN_TTL: R1313.2, U1304.5
/servo-port-1/ILIM_485: R1310.1, U1303.11
/servo-port-1/ILIM_TTL: R1312.1, U1304.3
/servo-port-1/MODE_485: JP1302.1, U1303.12
/servo-port-1/OE_TTL: JP1301.3, R1302.2, U1302.1
/servo-port-1/OVP_485: R1307.2, R1308.1, U1303.8
/servo-port-1/RE_485: JP1301.1, R1301.2, U1301.2
/servo-port-1/SHDN_485: R1311.2, TP1301.1, U1303.13
/servo-port-1/UVLO_485: R1308.2, R1309.1, U1303.7
/servo-port-1/VDD_485: C1305.1, C1306.1, D1303.1, J1301.2, U1303.18, U1303.19, U1303.20
/servo-port-1/VDD_TTL: C1308.1, C1309.1, D1304.1, J1302.2, U1304.1
/servo-port-2/A: D1401.1, J1401.3, R1404.1, TP1405.1, U1401.6
/servo-port-2/B: D1401.2, J1401.4, R1404.2, TP1406.1, U1401.7
/servo-port-2/DATA: D1402.1, J1402.3, R1405.2, R1406.2, TP1407.1
/servo-port-2/DATA_BUF: R1405.1, U1402.2, U1402.3
/servo-port-2/DVDT_485: C1403.1, U1403.10
/servo-port-2/EN_TTL: R1413.2, U1404.5
/servo-port-2/ILIM_485: R1410.1, U1403.11
/servo-port-2/ILIM_TTL: R1412.1, U1404.3
/servo-port-2/MODE_485: JP1402.1, U1403.12
/servo-port-2/OE_TTL: JP1401.3, R1402.2, U1402.1
/servo-port-2/OVP_485: R1407.2, R1408.1, U1403.8
/servo-port-2/RE_485: JP1401.1, R1401.2, U1401.2
/servo-port-2/SHDN_485: R1411.2, TP1401.1, U1403.13
/servo-port-2/UVLO_485: R1408.2, R1409.1, U1403.7
/servo-port-2/VDD_485: C1405.1, C1406.1, D1403.1, J1401.2, U1403.18, U1403.19, U1403.20
/servo-port-2/VDD_TTL: C1408.1, C1409.1, D1404.1, J1402.2, U1404.1
/servo-port-3/A: D1501.1, J1501.3, R1504.1, TP1505.1, U1501.6
/servo-port-3/B: D1501.2, J1501.4, R1504.2, TP1506.1, U1501.7
/servo-port-3/DATA: D1502.1, J1502.3, R1505.2, R1506.2, TP1507.1
/servo-port-3/DATA_BUF: R1505.1, U1502.2, U1502.3
/servo-port-3/DVDT_485: C1503.1, U1503.10
/servo-port-3/EN_TTL: R1513.2, U1504.5
/servo-port-3/ILIM_485: R1510.1, U1503.11
/servo-port-3/ILIM_TTL: R1512.1, U1504.3
/servo-port-3/MODE_485: JP1502.1, U1503.12
/servo-port-3/OE_TTL: JP1501.3, R1502.2, U1502.1
/servo-port-3/OVP_485: R1507.2, R1508.1, U1503.8
/servo-port-3/RE_485: JP1501.1, R1501.2, U1501.2
/servo-port-3/SHDN_485: R1511.2, TP1501.1, U1503.13
/servo-port-3/UVLO_485: R1508.2, R1509.1, U1503.7
/servo-port-3/VDD_485: C1505.1, C1506.1, D1503.1, J1501.2, U1503.18, U1503.19, U1503.20
/servo-port-3/VDD_TTL: C1508.1, C1509.1, D1504.1, J1502.2, U1504.1
/servo-uart/ACT: D1101.1, U1101.14
/servo-uart/RESET: C1103.1, R1101.2, TP1101.1, U1101.7
/servo-uart/UDM: D1102.3, U1101.42
/servo-uart/UDP: D1102.1, U1101.43
/servo-uart/XI: C1101.1, U1101.5, Y1101.1
/servo-uart/XO: C1102.1, U1101.6, Y1101.2
/usb-hub/FB_1V1: C704.2, R709.2, R710.1, U702.5
/usb-hub/GRSTz: C701.1, R701.2, TP701.1, U701.50
/usb-hub/SW_1V1: L701.1, U702.3
/usb-hub/USB_R1: R702.1, U701.64
/usb-hub/USB_VBUS: R703.2, R704.1, U701.48
/usb-hub/VDD_HUB: C707.1, C708.1, C709.1, C710.1, C711.1, C712.1, C713.1, C714.1, C715.1, FB701.2, TP702.1, U701.5, U701.8, U701.13, U701.21, U701.28, U701.31, U701.51, U701.57
/usb-hub/XI: C702.1, R708.1, U701.62, Y701.1
/usb-hub/XO: C703.1, R708.2, U701.61, Y701.3
/usb-port-1/DM_J: D801.3, J801.2
/usb-port-1/DP_J: D801.1, J801.3
/usb-port-1/ILIM: R801.1, U801.5
/usb-port-1/SHIELD: C807.1, J801.10, J801.11, R803.1
/usb-port-1/SSTX_N_J: C806.2, D802.2, J801.8
/usb-port-1/SSTX_P_J: C805.2, D802.1, J801.9
/usb-port-1/VBUS_J: C804.1, D801.5, FB801.2, J801.1
/usb-port-1/VBUS_OUT: C803.1, FB801.1, U801.6
/usb-port-2/DM_J: D901.3, J901.2
/usb-port-2/DP_J: D901.1, J901.3
/usb-port-2/ILIM: R901.1, U901.5
/usb-port-2/SHIELD: C907.1, J901.10, J901.11, R903.1
/usb-port-2/SSTX_N_J: C906.2, D902.2, J901.8
/usb-port-2/SSTX_P_J: C905.2, D902.1, J901.9
/usb-port-2/VBUS_J: C904.1, D901.5, FB901.2, J901.1
/usb-port-2/VBUS_OUT: C903.1, FB901.1, U901.6
/usb-port-3/DM_J: D1001.3, J1001.2
/usb-port-3/DP_J: D1001.1, J1001.3
/usb-port-3/ILIM: R1001.1, U1001.5
/usb-port-3/SHIELD: C1007.1, J1001.10, J1001.11, R1003.1
/usb-port-3/SSTX_N_J: C1006.2, D1002.2, J1001.8
/usb-port-3/SSTX_P_J: C1005.2, D1002.1, J1001.9
/usb-port-3/VBUS_J: C1004.1, D1001.5, FB1001.2, J1001.1
/usb-port-3/VBUS_OUT: C1003.1, FB1001.1, U1001.6
/usbc-upstream/CC1: J601.A5, U601.2
/usbc-upstream/CC2: J601.B5, U601.1
/usbc-upstream/C_RX1N: D601.5, J601.B10, U601.14
/usbc-upstream/C_RX1P: D601.4, J601.B11, U601.15
/usbc-upstream/C_RX2N: D602.5, J601.A10, U601.18
/usbc-upstream/C_RX2P: D602.4, J601.A11, U601.19
/usbc-upstream/C_TX1N: D601.2, J601.A3, U601.16
/usbc-upstream/C_TX1P: D601.1, J601.A2, U601.17
/usbc-upstream/C_TX2N: D602.2, J601.B3, U601.20
/usbc-upstream/C_TX2P: D602.1, J601.B2, U601.21
/usbc-upstream/DIR: R602.2, TP601.1, U601.11
/usbc-upstream/DM_C: D603.3, J601.A7, J601.B7
/usbc-upstream/DP_C: D603.1, J601.A6, J601.B6
/usbc-upstream/SHIELD_C: C607.1, J601.3, J601.4, J601.25, R603.1
/usbc-upstream/SSTX_N_C: C602.2, U601.7
/usbc-upstream/SSTX_P_C: C601.2, U601.6
/usbc-upstream/VBUS_DET: R601.2, U601.5
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

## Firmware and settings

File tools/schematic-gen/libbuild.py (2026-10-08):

"""Assemble the project symbol library 0_backbone.kicad_sym.

- fixes pin electrical types on the EasyEDA-imported symbols (they come in as "unspecified")
- copies the generic passives / small parts we need from the CDFER JLCPCB library
  (symbol + footprint + STEP model) into the project-local library
- copies the KiCad standard power / jumper / test point / mounting hole symbols so the
  project is self-contained (no dependency on global symbol libraries)
"""
import copy
import glob
import os
import re
import shutil
import sys

sys.path.insert(0, os.path.dirname(os.path.abspath(__file__)))
from sx import parse, dump, find, first, prop, set_prop, QStr as Q  # noqa: E402

REPO = os.path.abspath(os.path.join(os.path.dirname(os.path.abspath(__file__)), '..', '..'))
PROJ = os.path.join(REPO, 'backbone')
CDFER = os.environ.get('CDFER_PKG', '/tmp/kk/cdfer_pkg')  # unzipped JLCPCB-KiCad-Library PCM package
KSYM = '/usr/share/kicad/symbols'
LIBNAME = '0_backbone'

# ---------------------------------------------------------------- pin types
# name regex -> type, first match wins; '*' is the default for the symbol
PIN_TYPES = {
    'TUSB8041IRGCR': [
        (r'^VDD(33)?$', 'power_in'), (r'^VSS$', 'power_in'),
        (r'^USB_D[PM]_', 'bidirectional'), (r'^USB_SSTX', 'output'), (r'^USB_SSRX', 'input'),
        (r'^PWRCTL\d', 'output'), (r'^PWRCTL_POL', 'bidirectional'), (r'^OVERCUR', 'input'),
        (r'^(SDA|SCL)/', 'bidirectional'),
        (r'^(SMBUSz|FULLPWRMGMTz|GANGED|AUTOENz)', 'bidirectional'),
        (r'^(TEST|GRSTz|XI|USB_VBUS)$', 'input'), (r'^XO$', 'output'), (r'^USB_R1$', 'passive'),
        (r'^NC$', 'no_connect'),
    ],
    'CH344Q_C2988084': [
        (r'^VCC$', 'power_in'), (r'^GND$', 'power_in'), (r'^TXD', 'output'), (r'^RXD', 'input'),
        (r'^TNOW', 'output'), (r'^(CTS|DSR|RI|DCD)', 'input'), (r'^RTS', 'output'),
        (r'^(ACT|TX_S|RX_S)', 'output'), (r'^UD[+-]$', 'bidirectional'), (r'^XI$', 'input'),
        (r'^XO$', 'output'), (r'^(RESET|TEST)$', 'input'), (r'^NC$', 'no_connect'),
    ],
    'SN74LVC2G241DCU': [
        (r'OE', 'input'), (r'^[12]A$', 'input'), (r'^[12]Y$', 'tri_state'),
        (r'^(VCC|GND)$', 'power_in'),
    ],
    'LM5145RGYR': [
        (r'^(EN/UVLO|RT|SS/TRK|FB|SYNCIN|ILIM)$', 'input'), (r'^(COMP|SYNCOUT|LO|HO)$', 'output'),
        (r'^(AGND|PGND|EP|VIN)$', 'power_in'), (r'^PGOOD$', 'open_collector'),
        (r'^VCC$', 'power_out'), (r'^(BST|SW)$', 'passive'), (r'^NC$', 'no_connect'),
    ],
    'TPS54560DDAR': [
        (r'^(BOOT|SW)$', 'passive'), (r'^(VIN|GND|EP)$', 'power_in'),
        (r'^(EN|RT/CLK|FB)$', 'input'), (r'^COMP$', 'output'),
    ],
    'TLV62569DBVR': [
        (r'^(EN|FB)$', 'input'), (r'^(GND|VIN)$', 'power_in'), (r'^SW$', 'passive'),
    ],
    'TPS16630PWPR': [
        (r'^(IN|P_IN|GND|EP)$', 'power_in'), (r'^N\.C$', 'no_connect'),
        (r'^(UVLO|OVP|MODE|~\{SHDN\})$', 'input'), (r'^(dVdT|ILIM|OUT)$', 'passive'),
        (r'^IMON$', 'output'), (r'^~\{FLT\}$', 'open_collector'), (r'^PGOOD$', 'output'),
    ],
    'TPS25961DRVR': [
        (r'^(OUT|ILIM)$', 'passive'), (r'^(OVLO|EN/UVLO)$', 'input'), (r'^(GND|IN)$', 'power_in'),
    ],
    'HD3SS3220RNHR': [
        (r'^CC[12]$', 'bidirectional'),
        (r'^(CURRENT_MODE|PORT|VBUS_DET|ENn_MUX|ADDR|ENn_CC)$', 'input'),
        (r'^(TX|RX)', 'bidirectional'), (r'^(VCC33|VDD5|GND|EP)$', 'power_in'),
        (r'^(DIR|INT_N/OUT3|VCONN_FAULT_N|SDA/OUT1|SCL/OUT2|ID)$', 'open_collector'),
    ],
    'LM74700QDBVRQ1': [
        (r'^(VCAP|CATHODE)$', 'passive'), (r'^(GND|ANODE)$', 'power_in'),
        (r'^EN$', 'input'), (r'^GATE$', 'output'),
    ],
    'TPD4E05U06DQAR_C138714': [(r'^D', 'passive'), (r'^GND$', 'power_in'), (r'^NC$', 'no_connect')],
    'USBLC6-2SC6_C2687116': [(r'^GND$', 'power_in'), (r'.*', 'passive')],
    'TPS2553DBVR': [
        (r'^(IN|GND)$', 'power_in'), (r'^EN$', 'input'), (r'^/FAULT$', 'open_collector'),
        (r'^(ILIM|OUT)$', 'passive'),
    ],
    'CSD18532Q5B': [(r'^G$', 'input'), (r'.*', 'passive')],
    'SP3485EN': [
        (r'^RO$', 'tri_state'), (r'^(RE#|DE|DI)$', 'input'), (r'^(GND|VCC)$', 'power_in'),
        (r'^[AB]$', 'bidirectional'),
    ],
}
ALL_PASSIVE = [
    'B4B-EH-A', 'B3B-EH-A', 'XT30PW-M', 'HC-ST-003-01-J', 'TYPE-C24PQT',
    'TMPA1265SP-4R7MN-D', 'TMPC1265HP-3R3MG-D', '7447798720', 'SMNR4020-2.2UH',
    'C3225X7S2A475KT000N', 'C3225X7R2A225KT5L0U', 'GRM32ER61C476KE15L', 'CS3225X7R226K250NRL',
    'MA25V470M8X10', 'MA10V470M6X8', 'RVE470UF35V167RV084', '0453015.MR', '1206TD-4A', 'B560C-13-F',
    'PSM712', 'Crystal_8MHz_5032', 'Crystal_24MHz_3225',
    'R_0603', 'C_0402', 'C_0603', 'C_0805', 'C_1206', 'FB_0603', 'FB_0805', 'LED_0805_Green',
    'TVS_SMB', 'SMF5.0A', 'SS14',
]

# ---------------------------------------------------------------- CDFER copies
# new name, cdfer lib, cdfer symbol, footprint (CDFER name), value, lcsc, description
CDFER_COPIES = [
    ('R_0603', 'JLCPCB-Resistors', '0603,10kΩ', 'R_0603', '', '', 'Resistor 0603 (value + LCSC per instance)'),
    ('C_0402', 'JLCPCB-Capacitors', '0402,100nF,(2)', 'C_0402', '', '', 'Capacitor 0402 (value + LCSC per instance)'),
    ('C_0603', 'JLCPCB-Capacitors', '0603,100nF', 'C_0603', '', '', 'Capacitor 0603 (value + LCSC per instance)'),
    ('C_0805', 'JLCPCB-Capacitors', '0805,100nF', 'C_0805', '', '', 'Capacitor 0805 (value + LCSC per instance)'),
    ('C_1206', 'JLCPCB-Capacitors', '1206,10uF', 'C_1206', '', '', 'Capacitor 1206 (value + LCSC per instance)'),
    ('FB_0603', 'JLCPCB-Inductors', 'Ferrite,0603,(2)', 'FB_0603', '', '', 'Ferrite bead 0603 (value + LCSC per instance)'),
    ('FB_0805', 'JLCPCB-Inductors', 'Ferrite,0805', 'FB_0805', '', '', 'Ferrite bead 0805 (value + LCSC per instance)'),
    ('LED_0805_Green', 'JLCPCB-Diodes', 'LED,0805,Green', 'D_0805', 'LED Green', 'C2297', 'Green LED 0805 (JLC Basic)'),
    ('TVS_SMB', 'JLCPCB-Diodes', 'TVS-Uni,SMBJ28A', 'D_SMB', '', '', 'Unidirectional TVS, SMB (value + LCSC per instance)'),
    ('SMF5.0A', 'JLCPCB-Diodes', 'TVS-Uni,SMF5.0A', 'D_SOD-123FL', 'SMF5.0A', 'C19077497', 'TVS 5 V working, SOD-123FL (JLC Basic)'),
    ('SS14', 'JLCPCB-Diodes', 'Schottky,SS14', 'D_SMA', 'SS14', 'C2480', 'Schottky 40 V 1 A, SMA (JLC Basic)'),
    ('PSM712', 'JLCPCB-Diode-Packages', 'TVS-Bi, PSM712-LF-T7', 'SOT-23-3_L3.0-W1.7-P0.95-LS2.9-BR', 'PSM712-LF-T7', 'C32677', 'RS-485 TVS array -7/+12 V, SOT-23 (JLC Basic)'),
    ('SP3485EN', 'JLCPCB-Interface', 'Transceiver, RS485/422, 10Mbps, SP3485EN-L/TR', 'SOIC-8_L5.0-W4.0-P1.27-LS6.0-BL', 'SP3485EN-L/TR', 'C8963', 'RS-485 transceiver 3.3 V 10 Mbps (JLC Basic)'),
    ('Crystal_8MHz_5032', 'JLCPCB-Crystals', 'Crystal, 8MHz, 20pF, ±10ppm', 'CRYSTAL-SMD_L5.0-W3.2', '8MHz 20pF', 'C115962', 'Crystal 8 MHz 20 pF SMD5032 (JLC Basic)'),
    ('Crystal_24MHz_3225', 'JLCPCB-Crystals', 'Crystal, 25MHz, 11pF', 'OSC-SMD_4P-L3.2-W2.5-BL', '24MHz 18pF', 'C70571', 'Crystal 24 MHz 18 pF SMD3225 (YXC X322524MRB4SI)'),
]
DROP_PROPS = {'Stock', 'Price', 'Minimum Qty', 'Process', 'Attrition Qty', 'Part', 'LCSC Part', 'Manufacturer Part'}

# ---------------------------------------------------------------- KiCad std copies
KICAD_COPIES = [
    ('power', '+VDC', None), ('power', '+12V', None), ('power', '+5V', None), ('power', '+3V3', None),
    ('power', '+1V1', None), ('power', 'VBUS', None), ('power', 'GND', None), ('power', 'PWR_FLAG', None),
    ('Connector', 'TestPoint', 'TestPoint:TestPoint_Pad_D1.5mm'),
    ('Jumper', 'SolderJumper_3_Bridged12', 'Jumper:SolderJumper-3_P1.3mm_Bridged12_RoundedPad1.0x1.5mm'),
    ('Jumper', 'SolderJumper_2_Bridged', 'Jumper:SolderJumper-2_P1.3mm_Bridged_RoundedPad1.0x1.5mm'),
    ('Jumper', 'SolderJumper_2_Open', 'Jumper:SolderJumper-2_P1.3mm_Open_RoundedPad1.0x1.5mm'),
    ('Mechanical', 'MountingHole', 'MountingHole:MountingHole_3.2mm_M3_Pad_Via'),
]


def load_lib(path):
    return parse(open(path, encoding='utf-8').read())


def symbols(tree):
    return {s[1]: s for s in find(tree, 'symbol')}


def rename_symbol(sym, new):
    old = sym[1]
    sym[1] = Q(new)
    for u in find(sym, 'symbol'):
        if u[1].startswith(old + '_'):
            u[1] = Q(new + u[1][len(old):])
    return sym


def set_pin_types(sym, rules):
    for u in find(sym, 'symbol'):
        for p in find(u, 'pin'):
            name = first(p, 'name')[1]
            for rx, typ in rules:
                if re.search(rx, name):
                    p[1] = typ
                    break


def pin_type_fix(libsyms):
    for name, rules in PIN_TYPES.items():
        if name in libsyms:
            set_pin_types(libsyms[name], rules)
    for name in ALL_PASSIVE:
        if name in libsyms:
            set_pin_types(libsyms[name], [(r'.*', 'passive')])


def copy_footprint(fp, src_dir, dst_pretty, dst_3d):
    src = os.path.join(src_dir, fp + '.kicad_mod')
    dst = os.path.join(dst_pretty, fp + '.kicad_mod')
    text = open(src, encoding='utf-8').read()
    m = re.search(r'\(model "([^"]+)"', text)
    if m:
        model = m.group(1)
        step = os.path.basename(model)
        step_src = os.path.join(CDFER, '3dmodels', 'JLCPCB.3dshapes', step)
        if os.path.exists(step_src):
            shutil.copyfile(step_src, os.path.join(dst_3d, step))
            text = text.replace(model, '${KIPRJMOD}/' + LIBNAME + '.3dshapes/' + step)
        else:
            text = re.sub(r'\(model "[^"]+"', '(model ""', text)
    open(dst, 'w', encoding='utf-8').write(text)


def main():
    proj_lib_path = os.path.join(PROJ, LIBNAME + '.kicad_sym')
    tree = load_lib(proj_lib_path)
    libsyms = symbols(tree)

    cdfer_libs = {}
    for fn in glob.glob(os.path.join(CDFER, 'symbols', '*.kicad_sym')):
        cdfer_libs[os.path.basename(fn)[:-10]] = symbols(load_lib(fn))

    new_syms = []
    for new, lib, srcname, fp, value, lcsc, desc in CDFER_COPIES:
        if new in libsyms:
            continue
        src = cdfer_libs[lib][srcname]
        sym = copy.deepcopy(src)
        rename_symbol(sym, new)
        # drop volatile vendor fields, rename Part -> MPN
        mpn = prop(sym, 'Part')
        for p in list(find(sym, 'property')):
            if p[1] in DROP_PROPS:
                sym.remove(p)
        set_prop(sym, 'Footprint', LIBNAME + ':' + fp, hide=True)
        set_prop(sym, 'Value', value)
        set_prop(sym, 'LCSC', lcsc, hide=True)
        set_prop(sym, 'Description', desc, hide=True)
        if mpn and value:
            set_prop(sym, 'MPN', mpn, hide=True)
        copy_footprint(fp, os.path.join(CDFER, 'footprints', 'JLCPCB.pretty'),
                       os.path.join(PROJ, LIBNAME + '.pretty'), os.path.join(PROJ, LIBNAME + '.3dshapes'))
        new_syms.append(sym)
        libsyms[new] = sym

    for lib, name, fp in KICAD_COPIES:
        if name in libsyms:
            continue
        src = symbols(load_lib(os.path.join(KSYM, lib + '.kicad_sym')))[name]
        sym = copy.deepcopy(src)
        if fp:
            set_prop(sym, 'Footprint', fp, hide=True)
        new_syms.append(sym)
        libsyms[name] = sym

    pin_type_fix(libsyms)

    # KiCad standard footprints for the test points / jumpers / mounting holes: copy into the
    # project library so nothing depends on the global fp-lib-table
    KFP = '/usr/share/kicad/footprints'
    for sym, lib, fp in [('TestPoint', 'TestPoint', 'TestPoint_Pad_D1.5mm'),
                         ('SolderJumper_3_Bridged12', 'Jumper', 'SolderJumper-3_P1.3mm_Bridged12_RoundedPad1.0x1.5mm'),
                         ('SolderJumper_2_Bridged', 'Jumper', 'SolderJumper-2_P1.3mm_Bridged_RoundedPad1.0x1.5mm'),
                         ('SolderJumper_2_Open', 'Jumper', 'SolderJumper-2_P1.3mm_Open_RoundedPad1.0x1.5mm'),
                         ('MountingHole', 'MountingHole', 'MountingHole_3.2mm_M3_Pad_Via')]:
        src_fp = os.path.join(KFP, lib + '.pretty', fp + '.kicad_mod')
        dst_fp = os.path.join(PROJ, LIBNAME + '.pretty', fp + '.kicad_mod')
        if not os.path.exists(dst_fp):
            shutil.copyfile(src_fp, dst_fp)
        if sym in libsyms:
            set_prop(libsyms[sym], 'Footprint', LIBNAME + ':' + fp, hide=True)

    # rebuild the library tree with a KiCad 9 header
    out = ['kicad_symbol_lib', ['version', '20241209'], ['generator', Q('kicad_symbol_editor')],
           ['generator_version', Q('9.0')]]
    for s in find(tree, 'symbol'):
        out.append(s)
    for s in new_syms:
        out.append(s)
    open(proj_lib_path, 'w', encoding='utf-8').write(dump(out) + '\n')
    print('library written:', proj_lib_path, 'symbols:', len(find(out, 'symbol')))


if __name__ == '__main__':
    main()

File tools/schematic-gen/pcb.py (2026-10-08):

"""Build backbone.kicad_pcb from the schematic netlist: footprints with nets and schematic paths,
one placement rule area per hierarchical sheet, the usb_section rule area the DRU keys on, the
board outline, mounting holes and the version text.  Components are packed block by block into the
floorplan below (the "placement diagram"); routing is left for the layout stage.

Runs inside the KiCad 10 Flatpak python (pcbnew 10):
  flatpak run --filesystem=<repo>:rw --command=/usr/bin/python3 org.kicad.KiCad tools/schematic-gen/pcb.py
"""
import os
import sys

import pcbnew

sys.path.insert(0, os.path.dirname(os.path.abspath(__file__)))
from sx import parse, find, first  # noqa: E402

REPO = os.path.abspath(os.path.join(os.path.dirname(os.path.abspath(__file__)), '..', '..'))
PROJ = os.path.join(REPO, 'backbone')
NETLIST = os.path.join(PROJ, 'outputs', 'scratch', 'backbone.net')
PCB = os.path.join(PROJ, 'backbone.kicad_pcb')
SKELETON_PCB = os.path.join(os.path.dirname(os.path.abspath(__file__)), 'skeleton', 'backbone.kicad_pcb')
LIB = os.path.join(PROJ, '0_backbone.pretty')

BOARD_W, BOARD_H = 190.0, 130.0

# floorplan: sheet path -> (x0, y0, x1, y1, connector edge)
REGIONS = {
    '/input/': (0, 0, 46, 78, 'left'),
    '/buck-12v-servo/': (46, 0, 98, 44, None),
    '/buck-5v-servo/': (98, 0, 146, 44, None),
    '/buck-5v-usb/': (146, 0, 190, 44, None),
    '/servo-uart/': (46, 44, 90, 78, None),
    '/usb-hub/': (90, 44, 134, 78, None),
    '/usbc-upstream/': (134, 44, 190, 66, 'right'),
    '/usb-port-1/': (134, 66, 190, 83, 'right'),
    '/usb-port-2/': (134, 83, 190, 100, 'right'),
    '/usb-port-3/': (134, 100, 190, 117, 'right'),
    '/servo-port-0/': (0, 78, 33.5, 130, 'bottom'),
    '/servo-port-1/': (33.5, 78, 67, 130, 'bottom'),
    '/servo-port-2/': (67, 78, 100.5, 130, 'bottom'),
    '/servo-port-3/': (100.5, 78, 134, 130, 'bottom'),
}
USB_SECTION = (90, 44, 190, 130)
HOLES = [(4.5, 4.5), (BOARD_W - 4.5, 4.5), (4.5, BOARD_H - 4.5), (BOARD_W - 4.5, BOARD_H - 4.5)]
# connector rotation so the mating face points off the board edge (degrees, per footprint name prefix)
CONN_ROT = {'left': 180, 'right': 0, 'bottom': 270, 'top': 90}
MARGIN = 2.5
GAP = 1.2
EDGE_INSET = 0.6


def mm(v):
    return pcbnew.FromMM(v)


def vec(x, y):
    return pcbnew.VECTOR2I(mm(x), mm(y))


def main():
    net = parse(open(NETLIST, encoding='utf-8').read())
    comps = find(first(net, 'components'), 'comp')
    nets = find(first(net, 'nets'), 'net')

    # always start from the skeleton board (layers, plot settings, DRU hooks) so reruns are clean
    board = pcbnew.LoadBoard(SKELETON_PCB)

    # ---- nets
    netmap = {}
    node_net = {}
    for n in nets:
        name = first(n, 'name')[1]
        ni = pcbnew.NETINFO_ITEM(board, name)
        board.Add(ni)
        netmap[name] = ni
        for node in find(n, 'node'):
            node_net[(first(node, 'ref')[1], first(node, 'pin')[1])] = name

    # ---- footprints
    by_region = {}
    fps = {}
    for c in comps:
        ref = first(c, 'ref')[1]
        value = first(c, 'value')[1]
        fpname = first(c, 'footprint')[1].split(':', 1)[1]
        sp = first(c, 'sheetpath')
        names = first(sp, 'names')[1]
        tst = first(sp, 'tstamps')[1]
        sym_uuid = first(c, 'tstamps')[1]
        props = {first(p, 'name')[1]: (first(p, 'value')[1] if first(p, 'value') else '') for p in find(c, 'property')}
        fp = pcbnew.FootprintLoad(LIB, fpname)
        if fp is None:
            raise SystemExit(f'footprint {fpname} not found for {ref}')
        fp.SetFPID(pcbnew.LIB_ID('0_backbone', fpname))
        fp.SetReference(ref)
        fp.SetValue(value)
        try:
            fp.SetField('Footprint', '0_backbone:' + fpname)
            fp.SetField('Description', first(c, 'description')[1] if first(c, 'description') else '')
            fp.SetField('Datasheet', first(c, 'datasheet')[1] if first(c, 'datasheet') else '')
        except Exception:
            pass
        path = tst.rstrip('/') + '/' + sym_uuid
        fp.SetPath(pcbnew.KIID_PATH(path))
        fp.SetSheetname(names.strip('/') or 'backbone')
        fp.SetSheetfile(props.get('Sheetfile', ''))
        for fname in ('LCSC', 'MPN', 'max_mA'):
            if fname in props:
                try:
                    fp.SetField(fname, props[fname])
                except Exception:
                    pass
        attrs = fp.GetAttributes()
        if 'exclude_from_bom' in props:
            attrs |= pcbnew.FP_EXCLUDE_FROM_BOM | pcbnew.FP_EXCLUDE_FROM_POS_FILES
        if 'dnp' in props:
            attrs |= pcbnew.FP_DNP
        fp.SetAttributes(attrs)
        for pad in fp.Pads():
            key = (ref, pad.GetNumber())
            if key in node_net:
                pad.SetNet(netmap[node_net[key]])
        board.Add(fp)
        fps[ref] = fp
        by_region.setdefault(names, []).append((ref, fp))

    # ---- placement
    reserved = [(hx - 6, hy - 6, hx + 6, hy + 6) for hx, hy in HOLES]

    def bbox_mm(fp):
        bb = fp.GetBoundingBox(False, False)
        return (pcbnew.ToMM(bb.GetLeft()), pcbnew.ToMM(bb.GetTop()), pcbnew.ToMM(bb.GetRight()), pcbnew.ToMM(bb.GetBottom()))

    def place_center(fp, cx, cy):
        fp.SetPosition(vec(0, 0))
        l, t, r, b = bbox_mm(fp)
        ox, oy = (l + r) / 2, (t + b) / 2
        fp.SetPosition(vec(cx - ox, cy - oy))

    def intersects(a, b):
        return not (a[2] <= b[0] or a[0] >= b[2] or a[3] <= b[1] or a[1] >= b[3])
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

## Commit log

2026-08-29 Initial commit: robot backbone PCB workspace
    - HARDWARE.md: design notes for the Jetson backbone board (power tree,
    four dual-mode RS-485/TTL servo buses via CH344, USB 3.0 hub with
    generic downstream ports, surge protection, layout rules, workflow)
    - parts-shortlist.md: curated JLCPCB picks per block + raw catalog queries
    - kevins-kicad-helpers vendored as a git submodule (vendor/), wired onto
    PATH via mise.toml
    - .gitignore: excludes the local jlcpcb_parts.db catalog mirror and
    future kkh build outputs
2026-08-29 Add datasheets, golden references and functional design
    datasheets/: part datasheets for every curated pick in parts-shortlist.md
    (manifest.tsv + fetch.sh, TI sheets in the English editions), TI reference
    designs (TUSB8041 EVM, HD3SS3220 UFP EVM + checklist, LM5145 20 A EVM,
    TPS54560 EVM, SS layout and USB ESD app notes) and the ROBOTIS Dynamixel
    TTL / RS-485 circuits, connector pinouts and X-series spec data.
    FUNCTIONAL.md: what the board does at its connectors and to software —
    power domains, servo direction control via CH344Q TNOW, no-echo gating,
    USB-C UFP strapping, hub port roles, fault behaviour, software contract,
    and the open decisions (D1–D6) / verifications (V1–V5). Capture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
    [manifest.tsv]
2026-08-29 started kicad project
    [backbone.kicad_pcb, backbone.kicad_sch]
2026-10-08 before hand editing
    [backbone.kicad_pcb, backbone.kicad_sch, buck-12v-servo.kicad_sch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]
